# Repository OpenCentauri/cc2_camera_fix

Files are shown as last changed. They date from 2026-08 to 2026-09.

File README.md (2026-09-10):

# Prevent or recover the Elegoo CC2 stock camera failure

Some stock Elegoo Centauri Carbon 2 cameras can stop working after repeated
printer power cycles. This repository provides ways to protect or recover
an affected camera:

- a working camera can receive a small startup fix through USB without
  flashing a firmware image;
- if there is too little free space to install that fix, use a same-camera
  backup to build and restore a preventive image through USB;
- a camera that no longer starts can be recovered from its own flash backup
  with an external programmer.

All routes preserve the identity of **your** camera. There is no generic
firmware image in this repository, and you must never write another camera's
dump to your device.

> **AI-development note:** This fix was developed with the assistance of AI.
> It has produced the expected result in two tested cases, but if you have any
> doubts, independently audit the tools before using them on your hardware.

## First identify your camera

The known failure affects one 8 MiB flash-layout variant of the
`EF-S7-V1.0.30B` camera family. An earlier 16 MiB 30B variant uses materially
different hardware and firmware. A newer `EF-S7-V1.0.30D` revision also uses
different hardware and software and is not affected by this particular
problem.

Do this identification before building a USB cable, buying a programmer, or
running a repair operation.

If the camera feed still works, start with the read-only stream check. Install
[`cc2camera`](docs/INSTALLATION.md), find the printer's IP address or hostname,
and run:

```sh
cc2camera identify-camera PRINTER
```

For example:

```sh
cc2camera identify-camera 192.168.1.50
```

If the stream is unavailable, the signature is unknown, or you want authoritative
visual confirmation, inspect the hardware:

1. Power the printer off and unplug it from mains power.
2. Remove the camera module from the printer by undoing its single mounting
   screw, then unplug its four-wire cable.
3. Look at the large processor on the camera mainboard that's now in front of you.

If it is marked `TX5110`, the camera is likely the newer, unaffected family.
This recovery does not apply. If it is marked `Ingenic T23`, or the marking is
unclear, remove the two housing screws and check the complete PCB revision.

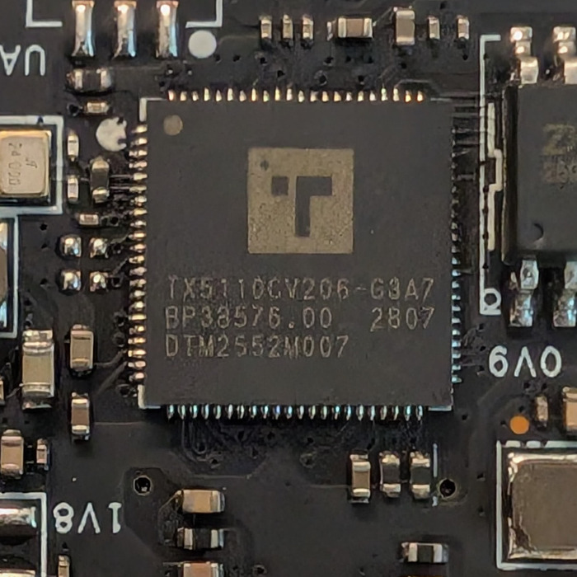
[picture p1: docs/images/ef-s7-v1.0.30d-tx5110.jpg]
TX5110 processor on a newer CC2 camera


The four-digit PCB manufacturing code appears to use `WWYY` week/year order.
It is useful supporting evidence, but is not a safe cutoff on its own: component
or firmware changes may not align exactly with calendar weeks.

| Identification | Observed manufacturing codes | What is known |
|---|---|---|
| `EF-S7-V1.0.30B` / Ingenic T23 / 8 MiB `ZB25VQ64` family | `0226`, `0526` (two units), `1526` | This is the supported layout on which the failure has been observed. Continue below. |
| `EF-S7-V1.0.30B` / Ingenic T23 / 16 MiB `P25Q128H` family | `4025` | This early layout is materially different. The known erase defect has not been established on it, and the current fix does not apply. |
| `EF-S7-V1.0.30D` / likely TX5110 | Not established | This revision is not affected by the known failure. This guide does not apply. |
| Any other revision, processor or flash layout | Not established | It has not been investigated. We do not know whether it is affected, and this guide does not apply. |

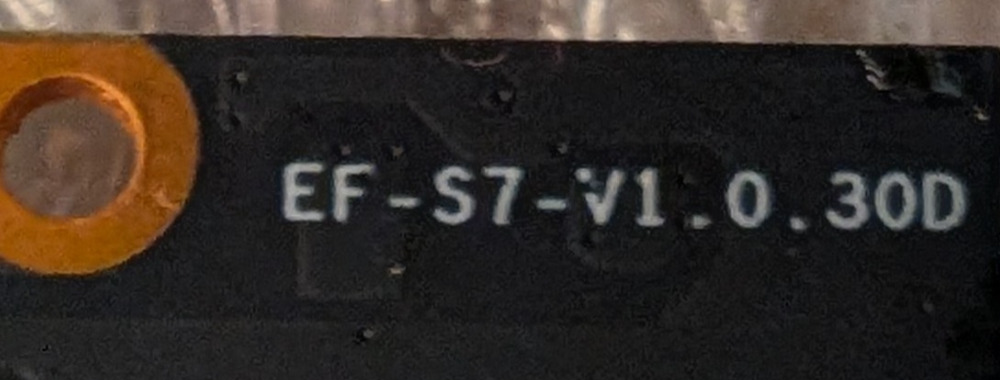
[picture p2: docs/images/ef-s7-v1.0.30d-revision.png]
EF-S7-V1.0.30D PCB marking


Photographs of the `EF-S7-V1.0.30B` board are available in the
[OpenCentauri camera documentation](https://docs.opencentauri.cc/hardware/CC2/camera/).
The stream fingerprint is a convenient read-only family-identification aid.
The complete hardware markings and the tool's firmware and flash-layout checks
determine whether a 30B camera is supported. Never bypass a refusal because a
date code or stream signature appears to match.

## Choose the path that matches your camera

### The affected camera still works

Use the [USB prevention route](#working-camera-usb-prevention). It needs a
simple camera-to-USB cable but no SPI programmer.

### The affected camera no longer works

First check whether the fault is isolated to the camera:

1. Leave the stock camera disconnected.
2. While the printer is off, connect a known-working ordinary USB webcam to
   the printer's front USB port.
3. Power the printer on.

If the replacement webcam produces a feed, the stock camera is likely the
problem. Continue with the
[hardware recovery route](#failed-camera-hardware-recovery).

If the replacement webcam also fails, this test has not isolated the problem
to the stock camera. Stop this camera-recovery procedure.

> **Temporary replacement:** Once the stock camera is disconnected, most
> ordinary USB webcams can be used in the front USB port while you wait for a
> replacement or decide whether to attempt recovery. Connect the webcam before
> powering the printer on so it has the best chance of becoming `/dev/video0`,
> which is the camera device the printer expects. The likely drawback is an
> inconvenient camera angle unless you improvise or print a mount.

## Working camera: USB prevention

Start with the startup fix below. It writes small configuration files and
reapplies a correction each time the camera starts, allowing its filesystem to
reclaim deleted data. It requires no SPI programmer or firmware-image write.
The installer checks that enough already erased space is available before
writing. If space is insufficient, use the
[image restore fallback](#if-there-is-not-enough-space-build-and-restore-an-image).

The startup fix is [physically tested on one supported camera](docs/STARTUP-HOOKS-VALIDATION.md),
including repeated boots and a bounded write/delete pressure test. That camera
already had the earlier preventive image patch; hook-only operation on otherwise
unmodified stock startup was not independently tested.

### What you need

- the affected camera, still able to start;
- access to a printer with a 0.2 mm nozzle;
- four P50 pogo pins, such as P50-J1;
- the USB-A plug and cable from an unused USB data cable;
- [cc2camera installed](docs/INSTALLATION.md), either the Windows executable or Python package;
- the Android platform `adb` executable as described in the installation guide.

### Build the camera-to-USB cable

The included [printable pogo-pin adapter](docs/models/cc2-camera-p50-pogo-adapter.stl)
acts as a plug for the four-pin socket on the camera PCB. Print it with a
**0.2 mm nozzle** and fit four P50 pogo pins; P50-J1 is one suitable example.

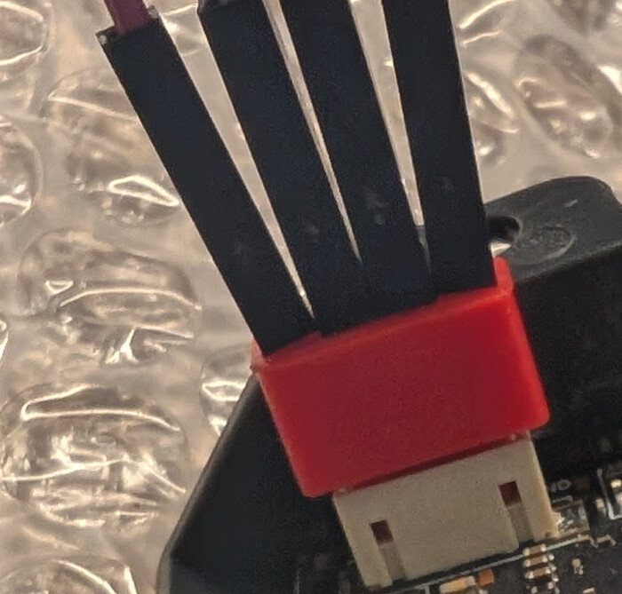
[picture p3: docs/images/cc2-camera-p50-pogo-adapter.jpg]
Printed pogo-pin camera adapter attached to a USB cable


The computer end can be salvaged from an old USB-A cable. Cut off the unwanted
device end, leaving the USB-A plug and enough cable to work with. Make sure it
is a data cable with all four conductors rather than a charge-only cable.

The camera connector carries ordinary USB 2.0:

| Camera pin | Signal | USB-A pin | Typical USB cable color |
|---:|---|---:|---|
| 1 | GND | 4 | Black |
| 2 | D+ | 3 | Green |
| 3 | D- | 2 | White |
| 4 | +5 V | 1 | Red |

Do not trust wire colors unverified. Before connecting the camera, use a
multimeter to confirm every conductor from the USB plug to its pogo pin and
confirm that +5 V is not shorted to ground or either data line.

### 1. Start ADB and make a backup

Follow the [installation guide](docs/INSTALLATION.md) for `cc2camera` and `adb`.
Connect only one camera, then run:

```sh
cc2camera start-adb
cc2camera backup backup.zip
```

Use the command prefix from your [platform's installation instructions](docs/INSTALLATION.md).
If ADB is not on PATH, add `--adb "path/to/adb"` to connected-camera commands.

`start-adb` temporarily starts the camera's existing root ADB service, which
lets the computer run maintenance commands. `backup` reads the complete flash
repeatedly and publishes `backup.zip` only after obtaining three consecutive
identical images. Keep that ZIP unchanged and in a separate safe location.

### 2. Install the startup fix

This step writes files to the camera's configuration partition. Keep power
connected until installation and file readback finish. Read the
[startup-hook guide](docs/STARTUP-HOOKS.md) for prerequisites and recovery
conditions before running:

```sh
cc2camera install-erase-fix --backup backup.zip
```

Confirm with `INSTALL-ERASE-FIX` when prompted. The command checks the camera,
backup, firmware and available space, then installs and reads back the files.
It applies the correction on the next boot; installation does not restart the
camera automatically.

If the command refuses installation **because there is insufficient space**,
continue with the image restore fallback below. For other refusals or any
write/readback failure, stop and resolve the reported problem before proceeding.
Do not bypass validation or retry a partial installation blindly.

### 3. Restart and verify

After successful installation, restart the camera manually. Without optional
persistent ADB, run `start-adb` again to reconnect for verification:

```sh
cc2camera start-adb
adb shell cat /tmp/cc2-hooks.log
```

The log should contain:

```text
cc2flash: erase fix active; master=0x1000; partition geometry=0x4000
cc2flash: 10-erase-fix.sh exit 0
```

Follow the [remaining verification checks](docs/STARTUP-HOOKS.md#verify-on-the-camera)
and confirm the camera feed works before returning it to service. A successful
installation message alone does not establish that the boot hook ran. Stop if
the hook fails or the camera no longer works normally.

### Optional: keep ADB available after restart

Persistent ADB is useful for future maintenance, but is not required for the
erase fix. To enable it, while ADB is online, run:

```sh
cc2camera install-adb-startup --backup backup.zip
```

Confirm with `ENABLE-ADB`. This writes a separate startup hook and performs its
own space checks and readback. After the next restart, ADB should return without
`start-adb`. The erase fix remains independently installed if optional ADB
installation is refused.

### If there is not enough space: build and restore an image

Use the unchanged backup from step 1. This route builds a camera-specific
preventive image and **writes that image to flash through USB**. Keep power
connected throughout restore and verification. Detailed prerequisites and stop
conditions are in the [USB-maintenance reference](usb-maintenance/REFERENCE.md).

```sh
cc2camera build-image backup.zip
cc2camera restore backup-cc2-recovery/cc2-camera-recovery.bin --backup backup.zip
```

The builder validates the backup and creates the preventive image. Do not pass
`--adb` to offline `build-image`. If needed, run `cc2camera start-adb` again before
`restore` and add `--adb "path/to/adb"` to that connected-camera command.

The optional `restore --dry-run` performs the same-camera and allowed-change
checks without opening USB. `restore` repeats those checks, validates the live
camera against the preserved backup, temporarily prepares the known stock SFC
driver, and requires the literal confirmation `RESTORE-CC2` before its first
write. Keep power connected until it returns to normal USB and completes the
required three-read verification. Preserve both the original ZIP and recovery
image, then confirm the camera feed works.

Stop if any command refuses the camera, backup, firmware, partition layout, or
generated image. Do not work around a validation failure. This fallback is for
insufficient space before hook installation; restoring an image from a backup
that already contains hooks has [additional limitations](docs/STARTUP-HOOKS.md#recovery-and-compatibility).

## Failed camera: hardware recovery

This route reads and rewrites the camera's eight-pin SPI flash with an external
programmer. The recommended setup uses the NeoProgrammer graphical
application for every flash operation; only the recovery-image build requires
a command line.

### What you need

- a Windows computer;
- a CH341A/CH341B programmer verified for 3.3 V operation;
- an SOIC-8 test clip and cable;
- a multimeter;
- NeoProgrammer;
- [cc2camera installed](docs/INSTALLATION.md); the standalone Windows executable needs no Python or Git.

The CH341 worked with the flash still soldered on the tested camera. A Bus
Pirate is possible but was not reliable in-circuit on that setup; see the
[programmer reference](hardware-recovery/PROGRAMMER_REFERENCE.md) if you need
that alternative.

### 1. Verify voltage before connecting the camera

With the programmer connected to USB but no camera or clip attached, measure
CH341A pin 28 (`VCC`) relative to ground. It should be approximately **3.3 V**.
Also measure the programmer's flash `VCC` output if possible.

If a measured supply or logic level is near 5 V, stop. Board color, seller
description, purchase date, and jumper position are not proof that a
programmer is safe for a 3 V flash chip.

### 2. Connect the flash

Keep the camera's normal USB/power cable disconnected. Connect the SOIC-8 clip
before plugging the programmer into USB. Align the clip's pin-1/red-stripe
conductor with the flash chip's pin-1 dot or notch, and use the programmer's
25-series SPI position.

Confirm the complete marking on the flash itself. The verified 30B family uses
a 64 Mbit/8 MiB `ZB25VQ64`-family 3 V SPI NOR. If the actual chip, voltage,
capacity, or detected profile differs, stop rather than selecting a merely
similar chip.

### 3. Make three trustworthy backups

In NeoProgrammer:

1. Select **Detect IC** and confirm the exact chip profile and 8 MiB capacity.
2. Select **Read IC** and save the full buffer as `cc2-camera-1.bin`.
3. Without moving the clip, read again and save `cc2-camera-2.bin`.
4. Read a third time and save `cc2-camera-3.bin`.

Each file must be exactly 8,388,608 bytes. The recovery builder compares all
three byte-for-byte. All-`00`, all-`FF`, unstable, wrong-size, or inconsistent
reads mean the connection is not trustworthy. Do not erase anything.

Copy all three files to a separate safe location before continuing. They are
the only verified backup of this camera's identity-bearing data.

### 4. Build the recovery image

Open a terminal in the folder containing your three dump files, as described
in the [installation guide](docs/INSTALLATION.md). Run:

```sh
cc2camera build-image cc2-camera-1.bin --confirm-read cc2-camera-2.bin --confirm-read cc2-camera-3.bin
```

The command performs the stability, firmware, flash-layout, identity, patch,
and generated-image checks. It must finish without an error and create:

```text
cc2-camera-1-cc2-recovery\cc2-camera-recovery.bin
```

If it refuses the dump or reports unfamiliar data, stop. There is deliberately
no general `--force` option.

### 5. Erase, program, and verify

In NeoProgrammer:

1. Detect the chip again and reconfirm its exact profile and 8 MiB capacity.
2. Open the generated `cc2-camera-recovery.bin`. Confirm that the loaded file
   is exactly 8,388,608 bytes. Do not select `config-restored.bin`,
   `serial.cfg`, or any individual region file.
3. Use NeoProgrammer's automatic write sequence with **Erase**,
   **Blank Check**, **Write/Program**, and **Verify** enabled.
4. Require full-chip Verify to finish without any mismatch.

A failed erase, blank check, program, or verify is not a usable result. Keep
the setup connected and diagnose it rather than trying to boot the camera.

Only after complete verification succeeds should you unplug the programmer,
remove the clip, reconnect the camera's normal cable, and test it in the
printer.

## What the repair changes

Affected cameras repeatedly rewrite the same configuration files during every
boot. A defect in the flash driver prevents reliable cleanup of deleted data,
so old filesystem records accumulate until the writable configuration area can
no longer accept the next boot-time writes.

The startup fix corrects the driver's erase setting in memory each boot so
filesystem cleanup can work. It leaves the firmware image in place and stores
its startup files in the writable configuration area.

The image-based repair compacts that area, preserves the camera's own identity,
and changes startup behavior so default files are created only when missing.
It reduces unnecessary writes; it does not persistently repair the driver's
erase setting.

The builder accepts only the known 30B firmware family and allows changes only
inside the audited startup-script window and writable configuration partition.
Technical details, offsets, supported image fingerprints, config modes, and
limitations are in the
[hardware-recovery technical reference](hardware-recovery/TECHNICAL_DETAILS.md).

## Privacy and backups

Raw dumps, `backup.zip`, `serial.cfg`, and generated recovery images contain
unit-specific identifiers. Do not publish them unredacted. Preserve the
original backup separately from the computer used for recovery.

No full camera dump or vendor firmware image is included in this repository.

## Advanced and audit documentation

- [Installation and release downloads](docs/INSTALLATION.md)
- [Complete cc2camera command reference](docs/CLI.md)
- [Startup-fix installation and verification](docs/STARTUP-HOOKS.md)
- [Startup-fix hardware findings](docs/STARTUP-HOOKS-VALIDATION.md)
- [Programmer and alternative-hardware reference](hardware-recovery/PROGRAMMER_REFERENCE.md)
- [Independent recovery-tool verification](hardware-recovery/CC2_RECOVERY_VERIFICATION.md)
- [Hardware-recovery regression results](hardware-recovery/TEST_RESULTS.md)
- [USB-maintenance reference](usb-maintenance/REFERENCE.md)
- [USB project and hardware-validation status](usb-maintenance/PROJECT-STATUS.md)
- [Physical USB restore validation](usb-maintenance/PHYSICAL-VALIDATION.md)
- [Recovered USB protocol](usb-maintenance/PROTOCOL.md)
- [USB reverse-engineering evidence](usb-maintenance/EVIDENCE.md)

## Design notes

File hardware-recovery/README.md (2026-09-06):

# CC2 camera hardware recovery

Start with the repository's
[camera identification and recovery guide](../README.md#first-identify-your-camera).
It determines whether this repair applies and presents the normal
NeoProgrammer workflow with one required command-line invocation.

For details beyond that normal path:

- [CLI reference](../docs/CLI.md) documents inspection, alternate build
  modes, output files, and independent readback verification.
- [Technical details](TECHNICAL_DETAILS.md) document the root cause, exact
  firmware transformation, supported image family, identity handling, safety
  properties, and limitations.
- [Programmer reference](PROGRAMMER_REFERENCE.md) contains the complete
  electrical mapping and the Bus Pirate alternative.
- [Independent verification](CC2_RECOVERY_VERIFICATION.md) and
  [regression results](TEST_RESULTS.md) record the current evidence.

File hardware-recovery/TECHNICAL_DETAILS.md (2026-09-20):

# Hardware-recovery technical details

The normal prevention and recovery paths are documented in the [main user guide](../README.md).
This document records the implementation, validation model, supported image family, and limitations.

## Why the stock camera stops working

The stock camera is a small Linux computer, not just an image sensor. Its firmware has a writable 128 KiB JFFS2 `config` partition. During every boot, the vendor startup script unconditionally copies the same five default configuration files into that partition again.

Normally JFFS2 garbage collection would reclaim the obsolete copies. On this firmware and flash layout, erase/garbage collection does not work correctly. The old records accumulate until the partition cannot accept the next boot-time writes. The camera then fails to finish booting and no longer appears as a working USB camera. From the printer, the symptom is simply a missing or permanently dead camera feed.

This tool repairs both parts of that problem:

- it rebuilds the exhausted `config` partition, either keeping only the
  camera's own serial data or recreating every live regular file once;
- it changes the startup script to create each default file only when it is missing, stopping the deterministic write leak.

## Check that the camera is actually the problem

A missing image does not by itself prove that the camera flash is corrupted. Isolate the camera from the printer before buying or connecting a programmer:

1. Power the printer off and unplug it from mains power.
2. Unscrew the stock camera module and unplug its four-wire cable from the printer. Do not work on the connector while the printer is powered.
3. Connect a known-working, ordinary USB webcam to the printer's front USB port while the printer is still off.
4. Power the printer back on with the stock camera disconnected.
5. If that webcam produces a feed, the printer mainboard, software, and USB-camera path are working; failure of the stock camera module is then likely. If the replacement webcam also fails, diagnose the printer side before attempting this repair.

Connecting the replacement webcam before boot is the safest way to have it appear as `/dev/video0`, which is the device the CC2 uses. Connecting it later can also work, but unplugging and reconnecting USB cameras repeatedly may assign different `/dev/video*` identifiers.

This is a useful isolation test, not proof of this exact flash failure. The builder provides the final check: it refuses a dump unless its firmware structure and invariant bytes match the supported camera firmware exactly.

## What this repair requires

For a failed camera, read and rewrite the eight-pin SPI flash with an external programmer. A working camera can use the USB prevention workflow in the main guide. Both use the same image builder.

The recommended setup is:

- a CH341A/CH341B USB programmer that has been verified for 3.3 V operation;
- an SOIC-8 test clip and cable, allowing the chip to be accessed on the camera board;
- a multimeter;
- NeoProgrammer on a Windows computer;
- Python 3.10 or later for validating the dump and building the repaired image.

A CH341 programmer is inexpensive and worked in-circuit on the tested camera: the flash did not need to be unsoldered. A Bus Pirate is still documented as an alternative, but in-circuit access may fail because other components on the board load or interfere with the SPI bus; on the tested setup it worked only after the flash was unsoldered.

> **Quick voltage safety check:** with the camera disconnected and the programmer powered from USB, measure CH341A pin 28 (`VCC`) relative to ground. It should be approximately **3.3 V**; if it is near 5 V, stop and do not connect the camera. Pin 28 is opposite pin 1 across the notched end of the 28-pin package—confirm the pinout before probing.
>
> This is a useful screening check, not complete certification. Some older CH341A board revisions need a soldered modification or external 3.3 V level shifting, while safe revisions exist and newer stock is often already corrected. Labels and purchase date are not proof: research your exact board and, if uncertain, also measure flash `VCC` and the SPI logic levels. See the [CH341 datasheet](https://www.wch-ic.com/downloads/CH341DS1_PDF.html) and the [older black-board voltage issue](https://wej.k.vu/electronics/ch341a-mini-programmer-fix/) for background.

## What the builder changes

### Persistent startup mitigation

The system patch changes the active copies in `/home/bashrc.sh` from unconditional writes such as:

```sh
cp /system/config/uvc.attr /etc/conf.d/uvc.attr
```

to copy-once checks:

```sh
[ -f /etc/conf.d/uvc.attr ] || cp /system/config/uvc.attr /etc/conf.d/uvc.attr
```

The original and patched scripts are included for audit. The patch preserves the vendor's existing source path for `uvc.config`.

The full system filesystem is not rebuilt. The tool verifies and decompresses the exact stock SquashFS fragment, applies the complete readable source transformation embedded near the top of the Python file, reconstructs the single-block XZ stream with fixed parameters, and updates its SquashFS size field. The reconstructed bytes must equal the exact audited patched hashes. Only this window is changed:

```text
0x463000–0x46AFFF
```

The input window, compressed fragment, decompressed fragment, original `bashrc.sh`, generated `bashrc.sh`, generated XZ stream, and final window each have independent expected SHA-256 checks. The shorter patched XZ stream intentionally leaves the now-unaddressed trailing stock bytes untouched; the authoritative SquashFS fragment size excludes them.

### Config recovery modes

`serial-only` is the default. The
builder extracts the camera's own CRC-valid `serial.cfg` and creates a minimal
128 KiB JFFS2 partition containing:

- one cleanmarker;
- one `serial.cfg` directory entry;
- one uncompressed `serial.cfg` inode;
- the original serial payload byte-for-byte;
- valid JFFS2 header, node, name, and data CRCs.

The five standard UVC/config files are intentionally omitted. The patched startup script creates each missing default once on the first successful boot.

Clean mode refuses to discard CRC-valid names outside the audited stock set.
If you have inspected the source and intentionally want to wipe unfamiliar
config contents too, add `--wipe-unknown-config`. That override still preserves
and cross-checks `serial.cfg`; it is not permission to ignore identity or
firmware validation failures.

`preserve-files` instead resolves the current root-directory view and recreates
every live regular file once in a fresh compact JFFS2 image. It preserves file
contents, mode, owner, timestamps, flags, inode identity, and directory-entry
metadata, while dropping obsolete/dead historical nodes. It supports
uncompressed, zero-filled, and zlib-compressed source fragments and fails
closed on directories, links/special entries, ambiguous metadata, unsupported
compression, fragments larger than the config partition, zlib streams that
expand beyond their declared size, or a live set too large for the audited
compact layout. Zlib decoding caps output at the declared size plus one byte.

## Supported image family

The `EF-S7-V1.0.30B` PCB label covers at least two materially different
hardware and firmware layouts. The four-digit PCB manufacturing code appears
to use `WWYY` week/year order. It is useful evidence, but is not treated as a
compatibility boundary:

| Observed layout | Manufacturing-code observations | Evidence |
|---|---|---|
| Supported 8 MiB `ZB25VQ64` family | `0226`, `0526` (two units), `1526` | The failure was reported on all four cameras. The `1526` unit and one recovered bricked unit have been physically recovered or protected with this fix. |
| Early 16 MiB `P25Q128H` family | `4025` | Two supplied full dumps share the 16 MiB partition map. Photographs show the T23, 30B PCB label, manufacturing code and 128-Mbit flash. Their JFFS2 cleanmarkers occur at `0x8000` intervals, matching an erase size handled by their kernel. The known `0x4000` erase mismatch has not been established on this layout. |

The early dumps were analyzed privately and remain outside the repository.
The 16 MiB family is not accepted by the builder or installers. A manufacturing
code, PCB revision or stream signature never overrides firmware, capacity,
partition-map or erase-geometry validation.

This release intentionally accepts only the exact firmware family already verified in four independent camera dumps with different unit identities:

- 8 MiB `ZB25VQ64` SPI NOR
- Ingenic T23N
- Linux `3.10.14__isvp_pike_1.0__`
- kernel build dated 2025-12-03
- Jovision `ucamera` v1.1.83
- partition layout:

```text
0x000000–0x03FFFF  boot
0x040000–0x18FFFF  kernel
0x190000–0x2E7FFF  root
0x2E8000–0x7CFFFF  system
0x7D0000–0x7DFFFF  HWCONFIG
0x7E0000–0x7FFFFF  config
```

There is no override or `--force` option for a mismatching firmware build. A refusal is a safety feature: do not weaken the checks or copy a reference camera's complete image over an unsupported unit.

## How validation handles different camera identities

A complete raw dump cannot be compared by ignoring only the visible serial
string. JFFS2 appends new nodes on each boot, so two otherwise identical
cameras naturally have different raw `config` histories. The HWCONFIG
partition also contains a per-unit UOID, an associated three-byte value, and a
four-byte little-endian year/month/day field. The date interpretation is based
on the observed `2026-03-02` and `2026-04-01` byte sequences; its exact vendor
semantics remain unknown.

The known 256-byte prefix of its type-12 length-prefixed record is validated.
Two payload lengths have been directly observed:

| Observed shape | Encoded payload length | Bytes after the known 256-byte prefix |
|---|---:|---|
| `type12-length256` | 256 (`0x0100`) | none |
| `type12-length261` | 261 (`0x0105`) | `00 00 02 98 40` or `00 00 00 08 40` |

The second shape was observed in stable multi-read dumps. Their boot, kernel,
root, system, stock startup-script window, partition layout, identity
structures, and exhausted JFFS2 failure states match the supported family.
The record length exactly includes the five added bytes. The camera's own
`ucamera` executable advances over this structure as a little-endian 16-bit
type, a little-endian 16-bit payload length, and that many payload bytes.

The observed serial and UOID families begin with either `12PSSSS3` or
`12PSSSS4`. Both retain the same total lengths and remaining character
structure. The fourth camera established that the adjacent check field spans
three bytes and that the calendar-shaped field varies by unit. Both fields are
preserved exactly and validated structurally rather than treated as firmware
bytes.

The meaning of the five-byte extension is unknown, so its value is not treated
as a firmware invariant. The validator requires record type 12 and one of the
two physically observed payload lengths: 256 bytes with no extension, or 261
bytes with a five-byte opaque extension. The extension is reported by length
and SHA-256. For comparison with the reference firmware, the 261-byte payload
length is normalized to 256 and the five extension bytes to zero. Recovery
preserves the complete input HWCONFIG partition byte-for-byte. Other payload
lengths remain unsupported until physically observed.

The validator therefore performs the strongest safe equivalent of “100% match apart from unit data”:

1. Every firmware byte that should be invariant must match the exact
   fingerprints after normalizing the structurally validated unit fields and
   the five-byte HWCONFIG extension, when present.
2. The 32 KiB SquashFS window containing `bashrc.sh` must equal either the exact stock hash or the exact audited patched hash.
3. These fields are excluded from or normalized for the invariant hash:

```text
0x7D200A–0x7D200C  three-byte HWCONFIG unit check value
0x7D2011–0x7D206E  94-byte HWCONFIG UOID
0x7D206F–0x7D2072  little-endian year/month/day field
0x7D2002–0x7D2003  normalized type-12 payload length
0x7D2104–0x7D2108  opaque five-byte type-12 extension, when present
0x7E0000–0x7FFFFF  writable JFFS2 config log
```

4. The excluded fields are still validated:
   - the type-12 length must be one of the two physically observed lengths;
   - the extension length and SHA-256 are recorded;
   - an all-zero or all-`FF` check value is reported as a warning;
   - the UOID must have an observed prefix and the expected 94-byte structure;
   - the four-byte date must decode as one of the physically observed calendar
     values, `2026-03-02` or `2026-04-01`;
   - `config` must contain CRC-valid JFFS2 nodes;
   - serial-only accepts only the six known filenames unless
     `--wipe-unknown-config` is explicit;
   - preserve-files accepts additional live names only when every entry can be
     safely reconstructed as a regular root file;
   - exactly one unambiguous `serial.cfg` value must be recoverable.

No other differences are accepted. See `REFERENCE_FINGERPRINTS.json`.

## Safety properties

The builder:

- can require any additional physical reads supplied with `--confirm-read` to be byte-for-byte identical;
- requires three identical reads for every unit unless reduced confidence is explicitly accepted;
- refuses files that are not exactly 8 MiB;
- validates exact hashes for every invariant segment;
- accepts only the exact known stock or known patched SquashFS window;
- never edits boot, kernel, root, or HWCONFIG;
- preserves the entire input HWCONFIG partition;
- preserves the original serial payload;
- validates the generated JFFS2 image by parsing it again, including a complete
  content/metadata round trip in preserve-files mode;
- refuses ambiguous, unsupported, or oversized preserve-files layouts;
- refuses unsafe output-directory reuse that could delete inputs or unrelated files;
- validates the complete generated recovery image again;
- proves no bytes changed outside the selected patch/config regions;
- creates a manifest and hashes for every output.

## Limitations

This is a mitigation for the deterministic per-boot write leak. It does not repair the underlying Ingenic SFC/JFFS2 erase-size defect. Other software that performs persistent writes could still consume config space.

The tool supports only the exact firmware build and known type-12 HWCONFIG
prefix represented by the embedded fingerprints. It accepts arbitrary contents
only for the observed five-byte extension. A future Elegoo/Jovision build,
another payload length, or a different record type or known-prefix layout must
be analyzed and fingerprinted separately.

Four real unit identities were directly inspected, including two with the
261-byte HWCONFIG record and one `12PSSSS3` identity. Invariant firmware and
the known HWCONFIG prefix must match exactly after unit-field and extension
normalization, while the UOID and serial must each match their observed
structure.
All unit-specific HWCONFIG bytes and the recovered serial payload are preserved
exactly. Because the proprietary full serial↔UOID derivation is unknown, the
tool does not infer or enforce a relationship between those independently
validated fields.

Static analysis can prove that a bricked dump is transformed into the exact known recovery bytes and that all relevant filesystems/checksums validate. Actual boot recovery still requires a controlled flash, full readback verification, and an observed successful boot; software-only review cannot replace that hardware test.

`serial.cfg` and the generated recovery image contain a unit-specific identifier. Do not publish them unredacted.

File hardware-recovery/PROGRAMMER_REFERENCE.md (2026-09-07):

# Programmer and electrical reference

The recommended NeoProgrammer workflow is documented in the [main user guide](../README.md#failed-camera-hardware-recovery).
This reference retains the complete electrical mapping and alternative-programmer notes.

## Programmer instructions

### Recommended: NeoProgrammer with CH341A/CH341B

NeoProgrammer does not use `cc2-camera-layout.txt`. This workflow erases, writes, and verifies the **complete 8 MiB** `cc2-camera-recovery.bin`, including the unit-specific data copied from the validated input dump.

#### Electrical checks

1. Read the complete part marking on the camera's SPI flash. The verified firmware family uses a 64 Mbit/8 MiB `ZB25VQ64`-family 3 V SPI NOR, but the exact chip and voltage on the board in front of you take precedence. The manufacturer describes `ZB25VQ64` as a 3 V device; do not infer voltage from programmer color, seller description, or a jumper alone. See the [ZB25VQ64 product information](https://www.gdzhianxin.com/index.php?a=show&c=index&catid=108&id=91&m=content).
2. With no camera or clip attached, perform the pin-28 voltage check described above. Also measure the programmer's flash `VCC` output and, if possible, its SPI logic-high levels. Use a proper level/voltage adapter if any measured level does not match the exact flash datasheet.
3. Disconnect the camera's USB cable and every other source of board power. Do not power the camera normally while the programmer supplies the flash. If your successful read setup uses a different, independently verified power arrangement, reproduce that exact arrangement; never connect two power sources blindly.
4. Connect the clip before plugging the CH341 programmer into USB. Align the clip's pin-1/red-stripe conductor with the flash's pin-1 dot/notch, and place the adapter in the programmer's **25-series SPI** position, not the 24-series I²C position.

Standard SOIC-8 SPI NOR signals are:

| Flash pin | Signal | CH341 label |
|---:|---|---|
| 1 | `CS#` | `CS` |
| 2 | `IO1/DO` | `MISO` |
| 3 | `IO2/WP#` | `WP` or pulled high |
| 4 | `GND` | `GND` |
| 5 | `IO0/DI` | `MOSI` |
| 6 | `CLK` | `CLK` |
| 7 | `IO3/HOLD#/RESET#` | `HOLD` or pulled high |
| 8 | `VCC` | verified 3 V supply |

Confirm this mapping against the exact flash datasheet and adapter silkscreen. Do not rely on the table if the package or adapter differs.

#### Establish a trustworthy backup

1. Install the appropriate CH341 driver and start NeoProgrammer. Obtain executables/drivers from a source you trust and scan them before use.
2. Use **Detect IC**, then confirm that the reported manufacturer/device ID, capacity, and exact selected profile correspond to the chip marking. Select `ZB25VQ64` only when that is the actual part. If the exact chip is unavailable, detection is inconsistent, or NeoProgrammer proposes only a vaguely similar `25Q64`, stop rather than guessing.
3. Click **Read IC**, wait for the complete 8 MiB buffer, and save it as `cc2-camera-1.bin`.
4. Without moving the clip, repeat the read twice and save `cc2-camera-2.bin` and `cc2-camera-3.bin`.
5. Require all three files to be exactly 8,388,608 bytes and have identical SHA-256 hashes. On Windows, for example:

```bat
certutil -hashfile cc2-camera-1.bin SHA256
certutil -hashfile cc2-camera-2.bin SHA256
certutil -hashfile cc2-camera-3.bin SHA256
```

All-`00`, all-`FF`, unstable, differently hashed, wrong-size, or intermittently detected reads mean the clip/power/in-circuit setup is not trustworthy. Stop and correct it before any erase or write.

Build the recovery image from those reads:

```bat
cc2camera build-image cc2-camera-1.bin --confirm-read cc2-camera-2.bin --confirm-read cc2-camera-3.bin
```

#### Full-chip erase, program, and verify

1. In NeoProgrammer, re-detect and re-confirm the exact chip profile and 8 MiB capacity.
2. Open the generated `cc2-camera-recovery.bin`. Confirm the loaded buffer/file is exactly 8,388,608 bytes. Do **not** load `config-restored.bin`, `serial.cfg`, or an individual layout region as the full-chip image.
3. Save the three original dumps somewhere separate before continuing. They contain the only verified copy of this camera's unit identity.
4. Use NeoProgrammer's automatic write sequence with **Erase**, **Blank Check**, **Write/Program**, and **Verify** enabled. Depending on the version, this is exposed through **Write IC** or its adjacent operation menu.
5. Do not edit status registers, OTP/security areas, unique IDs, or protection bits pre-emptively. If NeoProgrammer reports write protection, stop and identify the exact status-register meaning from the selected chip's datasheet before changing it.
6. Require NeoProgrammer's verify operation to complete without any mismatch. A failed erase, blank check, write, or verify is not a usable result; keep the setup connected and diagnose it rather than trying to boot.
7. Without moving the clip, run **Read IC** again and save the complete result as `cc2-camera-readback.bin`.
8. Verify that readback with the recovery tool:

```bat
fc.exe /b cc2-camera-1-cc2-recovery\cc2-camera-recovery.bin cc2-camera-readback.bin
```

Only after the tool reports a byte-for-byte match should you unplug the CH341 programmer, remove the clip, reconnect normal camera power, and test boot/USB enumeration.

NeoProgrammer's labels can vary slightly by release, but the required operation order does not: **three stable reads → build → full-chip erase → blank check → program → internal verify → full readback → tool verify**. NeoProgrammer describes the same backup/erase/write/verify capabilities in its [software overview](https://neoprogrammer.org/).

### Alternative: flashrom with a Bus Pirate

The generated `FLASHING.txt` also contains a `flashrom` command for the Bus Pirate. Unlike the NeoProgrammer workflow, it writes only the regions reported as changed and deliberately does not enable programmer-supplied target power.

In-circuit Bus Pirate access may not work on this camera because the rest of the board can interfere with the SPI bus. In the tested setup, the CH341 worked with the flash still soldered to the board, while the Bus Pirate worked only after the chip was unsoldered. Do not interpret unstable or failed reads as permission to write: obtain three identical full dumps first, or switch to the CH341 approach.

If you do use a Bus Pirate, independently verify the exact flash voltage, pinout, wiring, and power arrangement. Never power the camera normally while the programmer is connected unless you have explicitly designed and verified that arrangement.

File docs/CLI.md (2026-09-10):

# cc2camera command reference

Install using the [setup guide](INSTALLATION.md). Start with the workflows in
the [main guide](../README.md); these options are for reference.
Every command accepts `--help`. `cc2camera --version` reports the installed version.
On Windows PowerShell, use `.\cc2camera.exe` for a downloaded executable in the
current folder. Python installations also support `python -m cc2camera`.

## Connected camera

```text
cc2camera devices [--adb EXECUTABLE]
cc2camera device-info [--adb EXECUTABLE] [--serial SERIAL]
cc2camera identify-camera PRINTER [--timeout SECONDS]
cc2camera start-adb [--adb EXECUTABLE] [--serial SERIAL] [--timeout SECONDS]
cc2camera install-adb-startup --backup BACKUP.zip [--adb EXECUTABLE] [--serial SERIAL] [--yes]
cc2camera install-erase-fix --backup BACKUP.zip [--adb EXECUTABLE] [--serial SERIAL] [--yes]
cc2camera backup OUTPUT.zip [--adb EXECUTABLE] [--serial SERIAL]
    [--accept-bootloader-sha256 SHA256]
```

- `devices`: best-effort, read-only USB/HID and ADB listing.
- `device-info`: validate root ADB and the supported MTD partition layout.
  This is not a complete firmware-image inspection.
- `identify-camera`: connect only to the printer's HTTP MJPEG stream on port
  8080 and compare three consecutive JPEG encoder fingerprints with the known
  `EF-S7-V1.0.30B` and `EF-S7-V1.0.30D` signatures. Pass a printer hostname or
  IP address, for example `cc2camera identify-camera 192.168.1.50`. The command
  does not use USB, HID or ADB and does not modify the printer or camera.
  An unrecognized or changing signature is refused as unknown rather than
  guessed. The 30B signature has been observed on two independent known 30B
  cameras; the 30D signature has been observed on one known 30D camera. The
  stream cannot distinguish the early 16 MiB and affected 8 MiB 30B variants.
  Affected 8 MiB cameras have been observed with PCB manufacturing codes
  `0226`, `0526` and `1526`; a supplied early 16 MiB camera is marked `4025`.
  These codes appear to use `WWYY` order, but are supporting evidence rather
  than a safe compatibility cutoff. The tool's firmware and flash-layout
  checks determine whether the fix applies. Default HTTP timeout: 5 seconds.
- `start-adb`: temporarily start the existing daemon; no persistent startup
  file. Default timeout: 30 seconds.
- `install-adb-startup`: install `enabled/90-adb.sh` and the shared
  `/etc/conf.d/system.sh` runner. Requires `ENABLE-ADB` or `--yes`.
- `install-erase-fix`: install `enabled/10-erase-fix.sh` and the shared runner.
  Requires `INSTALL-ERASE-FIX` or `--yes`. It corrects the known kernel's master
  erase size in RAM before camera startup on subsequent boots.
  Both installers require online root ADB, a preserved same-camera backup,
  stable live reads and sufficient clean config space. They perform config
  file writes, not firmware flashing; neither remounts config during installation.
  Different contents at `system.sh` or the selected managed hook path are refused.
  Unrelated regular hooks in `enabled/` remain and execute in filename order.
  Restart manually and follow
  [startup hook verification](STARTUP-HOOKS.md); the erase hook has
  [physical validation on one supported camera](STARTUP-HOOKS-VALIDATION.md).
- `backup`: require three consecutive identical full reads within five
  attempts, then publish a new ZIP atomically. Never overwrites a backup.
  If ADB is offline, explicitly start it and rerun backup; backup itself is
  read-only. A reviewed unknown bootloader can be accepted by its exact
  SHA-256 without bypassing any other check.

`--adb` defaults to `adb`; a path to the executable is also accepted.
`--serial` is the USB ADB serial, not the identifier embedded in the firmware.
It does not relax the restore requirement for exactly one connected camera.

## Offline image work

```text
cc2camera inspect-image INPUT [--confirm-read DUMP]... [--show-identifiers]
cc2camera build-image INPUT [--confirm-read DUMP]... [-o DIR | --output DIR]
    [--config-mode {serial-only,preserve-files}]
    [--wipe-unknown-config] [--allow-fewer-reads] [--show-identifiers]
```

`INPUT` is a raw 8 MiB dump or an unmodified cc2camera backup ZIP.
Inspection validates without creating files; building creates a recovery bundle
in a new `<input-stem>-cc2-recovery/` directory unless `--output` is given.
The complete bundle is published atomically; failed builds leave no partial
bundle at the output path. Existing output directories are refused. Neither
command accesses hardware.

For raw dumps, repeat `--confirm-read` for each independent matching read:

```sh
cc2camera build-image camera-1.bin --confirm-read camera-2.bin --confirm-read camera-3.bin
```

A valid ZIP supplies its own three-consecutive-read evidence. Every raw input
requires three matching reads unless `--allow-fewer-reads` explicitly accepts
the higher risk. This exception is recorded in the bundle and does not bypass
firmware, identity, or mismatch checks.

| Config mode | Behavior |
|---|---|
| `serial-only` (default) | Rebuild config with only the camera's original serial.cfg; missing defaults are created at next boot. |
| `preserve-files` | Rebuild every supported live regular file once, preserving contents and metadata while dropping obsolete records. |

`--wipe-unknown-config` permits discarding unfamiliar names only with
`serial-only`. It never permits discarding the camera's identity.
`--show-identifiers` reveals identifiers in analysis reports; default reports
mask them. Raw dumps, ZIPs, serial.cfg, and recovery images always contain
private unit data regardless of report masking.

The bundle contains:

```text
cc2-camera-recovery.bin
cc2-camera-layout.txt
config-restored.bin
serial.cfg
MANIFEST.json
VALIDATION.txt
FLASHING.txt
SHA256SUMS.txt
```

Use the complete `cc2-camera-recovery.bin` for full-chip programming.
`FLASHING.txt` also contains an advanced flashrom region-write template based
on regions that actually changed. Always require full-chip verification.

## USB restore

```text
cc2camera restore IMAGE --backup BACKUP.zip [--dry-run]
    [--adb EXECUTABLE] [--serial SERIAL]
    [--bootloader-timeout SECONDS] [--reboot-timeout SECONDS]
    [--adb-timeout SECONDS]
```

`--dry-run` validates the candidate, preserved backup, allowed changes, known
preparation kernel, and transfer representation entirely offline. It opens no
transport and writes nothing.
It cannot certify the live camera or predict successful physical writing.

A real restore repeats local validation, requires the user to type `RESTORE-CC2`,
validates the live camera, applies the temporary SFC correction, and writes the
full image. Keep power connected until post-write verification completes.
If needed after reboot, temporary ADB startup requires separate consent.
There is no noninteractive write bypass or post-verification opt-out.

Timeouts default to 30 seconds for bootloader USB, 180 for normal USB return,
and 60 for post-write ADB availability. The last timeout does not cap the flash
reads themselves.

Verification requires three consecutive identical reads and exact agreement
through the end of HWCONFIG. Config may change during the required boot; the
output states explicitly whether config also matched byte-for-byte.

## External programmer verification

Require full-chip verification against the generated 8 MiB image in the
programmer software. If saving an independent readback, compare it with
`fc.exe /b expected.bin readback.bin` on Windows or
`cmp expected.bin readback.bin` on Linux/macOS. Any mismatch is a failure.
The tool does not operate an external programmer.

## Exit status

0 means the requested operation succeeded. 2 means a CLI, validation, or
operating-system error. An unknown `identify-camera` signature is a validation
failure and exits with 2 rather than guessing a camera revision. A successful
dry run is not a successful physical restore. A failed post-write check means a
write may already have occurred; read the error and keep the original backup.

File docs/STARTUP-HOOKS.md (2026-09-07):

# Experimental startup hooks without firmware flashing

This workflow is for the supported T23 camera while it still boots and has
working root ADB. It **writes files to the flash-backed config filesystem**;
it does not flash a firmware image or perform a raw partition erase. Keep a
verified backup from this camera and a working recovery method before testing.
Do not use it on a camera whose config is already exhausted.

The early-boot erase fix has physical validation on one supported camera:
hook execution, config remount, repeated boots, an observed GC erase and a
bounded automatic write/delete pressure test. See the
[hardware findings](STARTUP-HOOKS-VALIDATION.md) for observations and limits.
Offline tests additionally cover admission checks and shell failure paths;
power-loss recovery is not established. Installation never tries to remount
config while `ucamera` is running.

## Install from a checkout

Use the setup instructions in [INSTALLATION.md](INSTALLATION.md). Run from the
repository root so `python -m cc2camera` uses this checkout. Connect only one
camera. Obtain temporary ADB and preserve its backup first:

```sh
python -m cc2camera start-adb
python -m cc2camera backup before-hooks.zip
python -m cc2camera install-erase-fix --backup before-hooks.zip
```

Optional persistent ADB can be installed afterward, while ADB is online:

```sh
python -m cc2camera install-adb-startup --backup before-hooks.zip
```

Install the erase fix first so optional ADB does not consume its required space.
Persistent ADB is not required for the erase fix.

The confirmations are `INSTALL-ERASE-FIX` for the erase fix and `ENABLE-ADB`
for optional persistent ADB.
`--yes` explicitly supplies that consent for scripted local verification.
Both install commands accept `--adb` and `--serial`. They require already-online
ADB; neither silently starts it through HID. Keep the original backup unchanged.

Each command installs its feature in `/etc/conf.d/enabled`, and installs
`/etc/conf.d/system.sh` if absent:

| File | Purpose |
|---|---|
| `system.sh` | Copy the runner and all regular enabled scripts into a private tmpfs directory; execute them in C-locale filename order. |
| `enabled/10-erase-fix.sh` | Validate the known kernel and early-boot state, unmount config normally, correct the master erase size in RAM, and mount config again. |
| `enabled/90-adb.sh` | Start the existing ADB daemon if needed. |

Scripts execute synchronously with `/bin/sh`, before stock startup launches
`ucamera`. They must be regular files; symlinks and subdirectories in `enabled`
are refused by the runner. Hook stdout/stderr goes to `/tmp/cc2-hooks.log`.
A hook failure is logged and subsequent hooks can run if config is mounted.
If config is missing, read-only, or mounted from an unexpected device, the runner starts ADB for recovery and holds
startup rather than allowing the camera to run against an empty mountpoint.
It does not automatically reboot. This deliberate recovery hold lasts until
manual intervention; do not mistake it for a successful camera boot.

There is no migration or automatic overwrite of an existing different
`system.sh` or the selected managed hook. Only those two paths are checked for
expected contents by each installer. Unrelated regular hooks in `enabled/`
remain in place and execute in filename order. Exact files with mode `755`
are idempotent.
If an older or custom script is present, stop, save and review it, then resolve
it explicitly before installation. Do not blindly delete it or retry.

## Space admission and interrupted installation

Each command validates a preserved backup locally, then requires three
consecutive identical live flash reads, the known kernel SHA-256, matching
same-camera immutable data, and the expected partition map. It checks both:

- filesystem available bytes (`statfs`), with one extra logical erase block
  beyond the calculated installation budget;
- complete 16-KiB blocks containing a valid JFFS2 clean marker and otherwise
  only `FF`, with **five clean blocks retained** beyond the installation budget.

Dirty/reclaimable bytes, partial-block holes and entirely `FF` blocks without
clean markers do not count. Unmarked blocks may require the very erase operation
that is broken. The budget accounts for uncompressed data, inode pages,
namespace operations and block-tail slack. Current payloads require a 16-KiB
budget, hence at least six clean marked blocks and 32 KiB available via statfs.
This is deliberately conservative and may refuse a filesystem that could fit
these files under favorable conditions. There is no force option. If admission
fails for insufficient space, use the same-camera backup, image-building and
restore workflow instead. A runtime `force-gc`/unmount workaround is not provided.

The raw check measures already erased, marked blocks rather than assuming that
JFFS2 can reclaim deleted data. `statfs` alone is insufficient: its available
space accounting can include reclaimable dirty space. Neither measurement is
a guarantee against an erase failure, power loss or a concurrent writer.

Files are first pushed to verified tmpfs and read back byte-for-byte. Config is
read again and must be unchanged, and available space is checked again before
persistent writes. The selected hook is installed before the runner, using a
complete temporary file outside `enabled`, sync and rename. Final contents and
permissions are checked through ADB. No existing config file is truncated.

These checks cannot eliminate power-loss failure or a concurrent writer racing
the final check. Keep power stable. A timeout or readback failure can leave
partial installation; retain diagnostics and do not retry blindly. A leftover
`/etc/conf.d/.cc2-new-*` is refused and is never executed as an enabled hook.
No automatic cleanup writes config after an error.

## Verify on the camera

After the erase-fix command reports successful file readback, restart manually.
If persistent ADB was not installed, run `cc2camera start-adb` again to reconnect. Do not
run the erase hook yourself while the camera service is active.

```sh
adb shell cat /tmp/cc2-hooks.log
adb shell cat /proc/mtd
adb shell cat /proc/mounts
adb shell busybox pidof ucamera
adb shell busybox devmem 0x0043b190 32
```

Expected observations:

1. The log reports `10-erase-fix.sh` and contains
   `erase fix active; master=0x1000; partition geometry=0x4000`.
   If the optional ADB hook was installed, `10-erase-fix.sh` appears before
   `90-adb.sh`.
2. Config is mounted read/write from `/dev/mtdblock5` as JFFS2 at `/etc/conf.d`, and **all partition erase sizes
   still read `00004000`** in `/proc/mtd`. `ucamera` starts afterward.
3. If its optional hook was installed, ADB comes back without `start-adb`. The camera feed and its identity still work.
4. The final command returns a freshly read aligned pointer in
   `0x80450000..0x83fffd9c`. To independently read the master erase field,
   subtract `0x80000000` from that pointer and add `0x10`, then use
   `adb shell busybox devmem <calculated-address> 32` **without a value argument**.
   Expected value: `0x00001000`. Do not reuse an address from another boot.

Capture another backup and the kernel log without modifying config:

```sh
python -m cc2camera backup after-hooks.zip
adb shell dmesg
```

Stop if any check is refused, config is missing, the field or partition geometry
is wrong, ADB fails to return, the camera identity/feed changes, or dmesg reports
new erase/CRC/I/O errors. Do not run `flash_eraseall`, format config, kill
`ucamera` to force a remount, or repeatedly power-cycle a failing device.

Successful boot and readback alone establish hook execution, not garbage
collection. The separate [physical validation](STARTUP-HOOKS-VALIDATION.md)
records an observed erase, repeated boots and a bounded automatic GC pressure
test. Users do not need to repeat that stress test as routine installation
verification; the install commands do not stress the config partition.

## Recovery and compatibility

If the runner holds startup because config is missing or unusable, use the recovery ADB
connection to collect `/tmp/cc2-hooks.log`, `dmesg` and `/proc/mounts`. Do not
write to the empty `/etc/conf.d` directory. Use the preserved backup and the
repository's recovery procedure if ordinary mount recovery fails.

With config mounted and stable, removing an enabled hook is a persistent
filesystem operation requiring its own space and recovery assessment; removal
does not undo the current boot's RAM correction. Reboot restores the stock
master value unless the hook runs again. No uninstall command or migration is
provided here.

Full-flash backup still preserves these directories verbatim. The offline
`build-image --config-mode preserve-files` builder supports only flat config
files and **refuses** live subdirectories such as `enabled`; it does not silently
drop them. `serial-only` discards configuration by design and requires explicit
permission to discard unknown names. Do not use either as a hook-preserving
round trip. This workflow does not change the image builder's format support.

## Evidence and remaining uncertainty

Static analysis of all three supplied ROM images found the same kernel:
SHA-256 `0855c3a93f571c3130f1bdd38469e7c806ce713550a3ce536c81167579341545`
for flash bytes `[0x40000, 0x190000)`. The boot hook checks that complete kernel
partition with stock BusyBox MD5
`388e256470b2ad70f4a29cc37e0fee32`, plus exact live instructions, symbols,
partition geometry and the freshly read RAM pointer. MD5 here detects accidental
build differences; it does not authenticate firmware against an adversary.
The installer retains SHA-256. Using the built-in weaker boot fingerprint is an
explicit developer-approved exception; no other gate is relaxed.

The decoded driver selects erase commands for 4, 32 and 64 KiB. Its configured
16-KiB value falls through without initializing the command byte. A second
problem can replace a transfer failure with a later wait-ready success result.
These are static findings, not proof of which command reached the physical chip
on every failed erase. In particular, “the chip does not support 16 KiB” alone
is not an adequate explanation of the driver's behavior.

The hook changes only the master object's erase-size member, through the global
pointer at physical `0x0043b190`, offset `0x10`. Partition objects keep the copied
16-KiB geometry. The decoded loop therefore performs four 4-KiB operations for
a logical 16-KiB request. It does not alter JFFS2's block interpretation: existing
nodes can cross 4-KiB boundaries. The error-propagation defect is not repaired.

[Repository hardware records](../usb-maintenance/SFC-RESTORE-PREPARATION.md) report successful erase/readback after this RAM
field correction and return of failure after reboot. Those are prior reported
observations. The [startup-hook hardware findings](STARTUP-HOOKS-VALIDATION.md)
record physical runner execution, early remount and GC testing. The deliberate
recovery hold remains covered by offline tests, without physical fault injection.
The extracted stock `rcS` invokes `system.sh` after mounting config but before
`/home/bashrc.sh` launches `ucamera`; that establishes the proposed boot window.
Failure to mount config or find the script before that point cannot be repaired
by this hook.

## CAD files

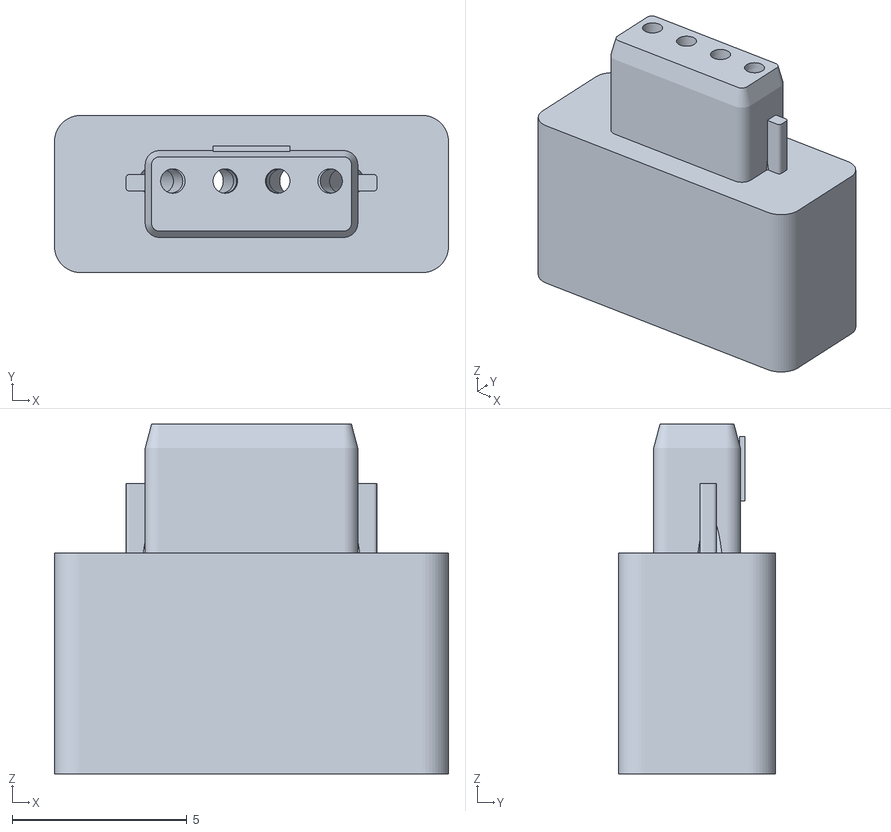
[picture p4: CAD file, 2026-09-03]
docs/models/cc2-camera-p50-pogo-adapter.stl
11.3 x 4.50 x 10.0

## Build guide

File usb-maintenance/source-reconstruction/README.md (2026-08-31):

# CC2 update-path source reconstruction

This directory is a human-readable, C-like reconstruction of the update-related
code in the supplied Elegoo Centauri Carbon 2 camera flash image.

It is **not the vendor's original source code**. Names, types, and control-flow
shape were chosen for readability. Constants, command branches, packet fields,
state transitions, paths, checks, and omissions are derived from the supplied
binaries. Every important reconstructed function is annotated with its original
address so it can be checked against the disassembly.

## Files

- `hid_update_reconstructed.c` — Linux `/bin/hid_update`: normal-mode HID
  framing, version/configuration commands, arbitrary-file upload, upgrade flag,
  and HID event loop.
- `uboot_updater_reconstructed.c` — main U-Boot updater: common frame format,
  metadata/data state machine, ACK/retry behavior, MD5 validation, SPI erase and
  write, HID/CDC transport choice.
- `spl_upgrade_gate_reconstructed.c` — SPL decision that detects the persistent
  upgrade magic and transfers control to the updater.
- `TRACEABILITY.md` — source-address map, confidence notes, and a list of the
  material unsafe behaviors retained in the reconstruction.
- `REPRODUCING.md` — commands for extracting the daemon and disassembling the
  address ranges from the supplied 8 MiB image.
- `protocol_reference.md` — the companion byte-level command and protocol
  reference.

## Analyzed inputs

| Artifact | Size | SHA-256 |
|---|---:|---|
| Supplied SPI-NOR image | 8,388,608 | `269f1b3b205e2ac30ada7cb98a7aeb9ada2e76786dc14abe95ea9c56dce73d1f` |
| Extracted `/bin/hid_update` | 19,048 | `bcbdd698b4b9208f73f7ef1f9846b3a96130a1bcc5c118c0e71543cf4e1ed503` |

The extracted daemon is a stripped little-endian MIPS32r2 ELF with MD5
`8091751fdd4d0d50ea31901663797a86`.

## Scope

The reconstruction covers the complete command surface found in the Linux
maintenance daemon and bootloader updater. It does not attempt to reproduce the
Linux kernel, UVC streaming application, codecs, sensor drivers, or unrelated
U-Boot commands.

No physical-camera write was performed while producing this reconstruction.
USB endpoint assignment and timing therefore remain runtime-unverified.

## How to read the code

Comments use these labels:

- `CONFIRMED` — visible directly in instructions, constants, descriptors, or
  filesystem contents.
- `INFERRED` — a readable name/type or library-level interpretation reconstructed
  from calling convention and use.
- `BUG-COMPAT` — deliberately shows unsafe or surprising behavior present in the
  binary; it is documentation, not recommended implementation.

The source is intended for audit and reasoning, not compilation or deployment.
External helpers such as `transport_send`, `spi_erase`, and `vendor_flash_ioctl`
stand in for vendor/library functions whose internals are outside the relevant
protocol path.

Run the dependency-free protocol checks with:

```sh
python3 verify_protocol_vectors.py
```

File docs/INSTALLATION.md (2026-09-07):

# Install cc2camera

## Windows: standalone executable

1. Open the [GitHub Releases page](https://github.com/phryneas/cc2_camera_fix/releases).
2. Choose a release and expand **Assets**.
3. Download **cc2camera.exe** to a new folder, for example `Documents\CC2-camera`.
4. In File Explorer, open that folder, click its address bar, type `cmd`,
   and press Enter. This opens Command Prompt in the correct folder.
5. Paste this command and press Enter:

```bat
cc2camera.exe --version
```

It should print a version number. Keep this window open for the recovery
instructions. Do not double-click the executable: it is a command-line tool.
In PowerShell, prefix a local executable with `.\`, for example
`.\cc2camera.exe --version`.

The executable is unsigned; Windows may show a reputation warning. Check that
you obtained it from this repository's intended release. Do not disable your
antivirus. If you are not comfortable running it, use the Python route below.
Each release build also attaches `cc2camera.exe.sha256`; you can compare its
digest with `certutil -hashfile cc2camera.exe SHA256`. This checks download
integrity, not publisher identity.

Assets appear only after the release build succeeds. If a release has no
executable, inspect its Actions result or use Python; the source-code ZIP is
not a standalone executable.

## USB workflows also need ADB

Offline image inspection/building and external-programmer recovery do not need
ADB. USB startup, backup, and restore need Google's
[SDK Platform Tools](https://developer.android.com/tools/releases/platform-tools).

On Windows, download and extract the Windows ZIP. Copy the **whole extracted
platform-tools folder** into your CC2-camera folder; keep its DLLs beside
`adb.exe`. There is no need to edit PATH. Test:

```bat
platform-tools\adb.exe version
cc2camera.exe devices --adb "platform-tools\adb.exe"
```

Add `--adb "platform-tools\adb.exe"` to connected-camera commands in the guide.
For example:

```bat
cc2camera.exe start-adb --adb "platform-tools\adb.exe"
cc2camera.exe backup backup.zip --adb "platform-tools\adb.exe"
```

`restore --dry-run` accepts these options but does not access ADB or USB.
On Linux/macOS, download the matching Platform Tools archive and extract it;
use `--adb "/path/to/platform-tools/adb"` if it is not on PATH.
An offline ADB camera is expected before `start-adb`; an authorization,
driver, or device-ambiguity error is not equivalent to that state.

## Python alternative: install directly from GitHub

Use Python 3.10 or newer. No Git or manual repository download is required.
Choose a release tag from Releases. In the command below, replace
`TAG` with that tag (including its leading `v`, if present).

Windows Command Prompt, in your working folder:

```bat
py -m venv .venv
.venv\Scripts\python.exe -m pip install "cc2camera @ https://github.com/phryneas/cc2_camera_fix/archive/refs/tags/TAG.zip"
.venv\Scripts\python.exe -m cc2camera --version
```

Linux/macOS:

```sh
python3 -m venv .venv
.venv/bin/python -m pip install "cc2camera @ https://github.com/phryneas/cc2_camera_fix/archive/refs/tags/TAG.zip"
.venv/bin/python -m cc2camera --version
```

Use that same Python path followed by `-m cc2camera` in place of `cc2camera`
throughout the guide. No environment activation or PATH edit is needed.
HID support is installed with the package. ADB remains separate.
On Linux, your distribution may require its Python venv package and USB device
permissions. Do not use `sudo pip` or bypass an externally-managed-Python error.

## Contributor and release maintenance

Contributors can install from the repository root with
`python -m pip install -e .` and run
`python -m unittest discover -s tests -v`.

The maintainer creates and publishes releases manually in GitHub. Publishing a
release (including a prerelease) triggers the executable workflow on its commit:
install, offline tests, PyInstaller build, frozen CLI smoke checks, hash, upload.
Saving a draft does not trigger it. The workflow creates neither tags nor releases.
Existing assets are not overwritten. The Windows runner builds a console
application with Python/HID support, not ADB or firmware images.
The workflow must be present in the released source.

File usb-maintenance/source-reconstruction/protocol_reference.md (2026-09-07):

# Elegoo Centauri Carbon 2 stock-camera interaction protocol

**Firmware-specific reverse-engineering reference — updated 2026-09-04**

This document describes every command branch found in the supplied CC2 camera's
Linux maintenance daemon and U-Boot updater. It covers normal-mode USB HID,
bootloader HID, the bootloader's alternate CDC transport, configuration access,
the Linux file-upload service, the upgrade-mode trigger, firmware transfer, and
the absence of any USB flash-read command.

The catalog is complete for the two analyzed binaries. It is not a claim about
other firmware revisions. All multibyte integers are little-endian unless noted.

> **Physical status:** one test completed the in-order bootloader HID transfer,
> full-flash erase/write, normal reboot, video check, and independent three-read
> verification. The preceding normal-mode trigger is not safe: its stock erase
> path can fail and page-program the flag over occupied JFFS2 data. The current
> one-command restore remains unsuitable for end users. See
> [the physical validation record](../PHYSICAL-VALIDATION.md).

## 1. Evidence, scope, and confidence

| Artifact | Size | SHA-256 |
|---|---:|---|
| Supplied 8 MiB flash image | 8,388,608 | `269f1b3b205e2ac30ada7cb98a7aeb9ada2e76786dc14abe95ea9c56dce73d1f` |
| Supplied research archive v0.1.0 | 32,904 | `9593b01f3c40085fee6b6d1501538b4a0c2abc93fae0710af5ed25aa5f0d694a` |
| Supplied hardware notes | 4,392 | `7e63ea0ba157b0b6486d4d0f73e26ac09c9e55541fe328e6c71d4dae4babf72e` |
| Extracted `/bin/hid_update` | 19,048 | `bcbdd698b4b9208f73f7ef1f9846b3a96130a1bcc5c118c0e71543cf4e1ed503` |

`/bin/hid_update` is a stripped, little-endian MIPS32r2 ELF with MD5
`8091751fdd4d0d50ea31901663797a86`. Its Linux-side behavior and U-Boot's updater
were reconstructed by static disassembly. The supplied camera image was not
written to physical hardware during this analysis.

Confidence labels used here:

| Label | Meaning |
|---|---|
| Confirmed | Directly represented by code, constants, descriptors, or filesystem data in the supplied image |
| Runtime-unverified | Statically confirmed but not exercised against a physical camera in this work |
| Unknown | Not recoverable with confidence from the supplied image alone |

## 2. System and flash layout

The camera uses two distinct update stages:

1. Linux `/bin/hid_update` handles normal-mode maintenance commands and can set
   two persistent upgrade words.
2. After reboot, SPL sees those words and starts the U-Boot updater, which accepts
   a host-supplied image and writes it to SPI NOR.

The 8 MiB flash map is:

| MTD | Offset | Size | End | Contents |
|---|---:|---:|---:|---|
| `mtd0` | `0x000000` | `0x040000` | `0x040000` | SPL/main U-Boot |
| `mtd1` | `0x040000` | `0x150000` | `0x190000` | Linux uImage |
| `mtd2` | `0x190000` | `0x158000` | `0x2e8000` | root SquashFS |
| `mtd3` | `0x2e8000` | `0x4e8000` | `0x7d0000` | system SquashFS |
| `mtd4` | `0x7d0000` | `0x010000` | `0x7e0000` | plaintext HWCONFIG |
| `mtd5` | `0x7e0000` | `0x020000` | `0x800000` | JFFS2 runtime configuration |

The persistent upgrade words are at flash offset `0x7f8000`, inside `mtd5`.

## 3. USB identities and transports

### 3.1 Normal Linux mode

The active configuration contains:

| Field | Value |
|---|---|
| VID | `0xa108` |
| PID | `0x2240` |
| bcdDevice | `0x0090` |
| Product | `Ingenic HD Web Camera` |
| Manufacturer | `Ingenic Semiconductor Co.,Ltd` |
| Serial | `Ucamera001` |
| `adb_en` configuration | `1` |

The firmware builds a composite camera gadget containing UVC and the maintenance
HID endpoint used by `/bin/hid_update`. ADB is configuration-capable, but the
presence of `adb_en:1` must not be confused with a running daemon; see section 9.

Normal maintenance HID uses report ID `1` and fixed 1,024-byte reports.
`/bin/hid_update` opens `/dev/hidg0` read/write, waits with `select`, and processes
one complete 1,024-byte read at a time. There is no session setup, challenge, or
authentication. Except for the `0x3200` upload sequence field, requests are
independent.

### 3.2 Bootloader HID mode

The U-Boot USB device descriptor is:

```text
12 01 00 02 00 00 00 40 08 a1 08 ff 00 01 00 00 00 01
```

This decodes to USB 2.0, VID `0xa108`, PID `0xff08`, bcdDevice `0x0100`,
64-byte EP0, one configuration, and no USB string descriptors.

The vendor HID report descriptor declares usage page `0xff00`, report ID `1`,
8-bit fields, and report count `0x0bff` (3,071) in each direction. A report is
therefore 3,072 bytes including the report ID. Endpoint addresses and maximum
packet sizes are assigned at runtime and cannot be stated from the template.

### 3.3 Bootloader CDC mode

U-Boot also contains a CDC serial gadget. It feeds the same updater state machine
as HID, so CDC adds no commands. The updater frame is sent directly over CDC,
without the HID report ID or 3,072-byte padding.

The CDC descriptor template contains runtime placeholders, including a zero PID.
The stable CDC PID and endpoint assignments are therefore **unknown** without a
physical enumeration trace.

## 4. Normal-mode HID framing

### 4.1 Report layout

Requests and responses are fixed at 1,024 bytes:

| Offset | Size | Request meaning | Response meaning |
|---:|---:|---|---|
| 0 | 1 | report ID `0x01` | report ID `0x01` |
| 1 | 2 | magic `5a 5a` | magic `5a 5a` |
| 3 | 2 | command | echoed command |
| 5 | 1 | frame type | frame type |
| 6 | 2 | payload length | payload length |
| 8 | 4 | auxiliary value; sequence for `0x3200` | status code |
| 12 | 2 | CRC | CRC |
| 14 | `length` | payload | payload |
| remainder | — | normally zero padding | zero padding |

For valid host traffic, frame type `1` means payload/continuation and frame type
`2` means payload/final. The request parser includes payload in the CRC for both
types. Other frame-type values are not explicitly rejected, but their payload is
not covered by CRC and several handlers still trust `length`; they should not be
used.

The response builder emits a payload only for response frame type `1`. Every
ordinary acknowledgement is type `0`, length zero, with the result in the
32-bit status field.

### 4.2 CRC algorithm

The CRC is a nonstandard reflected use of polynomial `0x1021`:

```python
def cc2_crc16(data: bytes) -> int:
    crc = 0xffff
    for byte in data:
        crc ^= byte
        for _ in range(8):
            old_lsb = crc & 1
            crc >>= 1
            if old_lsb:
                crc ^= 0x1021
    return crc & 0xffff
```

The input is report bytes `0..11`, followed by exactly `length` payload bytes
when request frame type is `1` or `2`. CRC bytes `12..13` and report padding are
excluded. The check vector `b"123456789"` produces `0x1dba`.

The daemon does not bound the declared payload length to the 1,010 bytes remaining
in a report before calculating CRC. Malformed lengths can make it read beyond its
1,024-byte input buffer.

### 4.3 Parser status values

| Status | Meaning |
|---:|---|
| `0` | success |
| `1` | command/handler failure |
| `2` | wrong report ID |
| `3` | wrong magic |
| `4` | CRC mismatch |
| `5` | unknown high-nibble command group |

An unknown command inside a recognized group commonly produces **no response**,
not status `5`. Host software needs a timeout.

### 4.4 Top-level command dispatch

| Command range | Disposition |
|---|---|
| exact `0x0001` | version query |
| other `0x0xxx` | no response |
| any `0x1xxx` | no-op path; no response |
| recognized `0x2xxx` | configuration GET/SET |
| unrecognized `0x2xxx` | no response |
| recognized `0x3xxx` | Linux file upload |
| unrecognized `0x3xxx` | no response |
| **any `0x4xxx`** | set upgrade words and reboot |
| `0x5xxx`–`0xfxxx` | response status `5` |

The `0x4xxx` behavior is group-wide. `0x4000` is the conventional command, but
every command whose high nibble is `4` reaches the same destructive path.

## 5. Complete normal-mode command catalog

### 5.1 Version query

| Command | Request | Success response | Failure |
|---:|---|---|---|
| `0x0001` | No payload required | type `1`, status `0`, first line of `/tmp/version.txt` without newline | status `1` if open/read fails |

The file is opened with mode `r+`. Extra request payload is ignored.

### 5.2 Configuration commands (`0x2xxx`)

Every listed field has an even GET command and the immediately following odd SET
command. These are all configuration commands recognized by this binary:

| GET | SET | Key in `/etc/conf.d/uvc.config` | Present in supplied active config? |
|---:|---:|---|---|
| `0x2000` | `0x2001` | `manufact_lab` | yes |
| `0x2010` | `0x2011` | `serial_lab` | yes |
| `0x2020` | `0x2021` | `productnumber` | no |
| `0x2030` | `0x2031` | `vendor_id` | yes |
| `0x2040` | `0x2041` | `product_id` | yes |
| `0x2050` | `0x2051` | `device_bcd` | yes |
| `0x2f00` | `0x2f01` | `model_lab` | no |
| `0x2f10` | `0x2f11` | `cmei_lab` | no |
| `0x2f20` | `0x2f21` | `appkey` | no |
| `0x2f30` | `0x2f31` | `product_lab` | yes |
| `0x2f40` | `0x2f41` | `adb_en` | yes |
| `0x2f50` | `0x2f51` | `sensor_name` | yes |
| `0x2f60` | `0x2f61` | `i2c_addr` | yes |
| `0x2f70` | `0x2f71` | `default_boot` | yes |
| `0x2f80` | `0x2f81` | `sensor_fps` | yes |
| `0x2f90` | `0x2f91` | `sensor_width` | yes |
| `0x2fa0` | `0x2fa1` | `sensor_height` | yes |
| `0x2fb0` | `0x2fb1` | `hvflip` | yes |
| `0x2fc0` | `0x2fc1` | `rcmode` | yes |
| `0x2fd0` | `0x2fd1` | `bitrate` | yes |
| `0x2fe0` | `0x2fe1` | `qp_value` | yes |

GET semantics:

- Request payload is ignored.
- The daemon scans `/etc/conf.d/uvc.config`, splits each candidate line at `:`,
  trims the key at its first space, and returns the raw value bytes between the
  colon and newline.
- Success is response type `1`, status `0`, with the value as payload.
- A missing key, open error, or parse error returns status `1`.

SET semantics:

- Send the replacement value as request payload using frame type `1` or `2`.
- The daemon rewrites the matching line, preserving the original key/padding and
  replacing the bytes after the colon.
- It buffers the remainder of the file, writes the replacement line and then
  restores that tail. If the result is shorter than the old file, it zero-pads
  back to the old length instead of truncating, so shorter values can leave NUL
  bytes at the end of the configuration file.
- Success is response type `0`, status `0`; failure is status `1`.
- There is no type, range, encoding, or semantic validation.
- Changes affect the JFFS2 runtime copy. The boot script copies the SquashFS
  default only if the runtime file is absent.
- The implementation uses small fixed stack buffers and does not adequately
  constrain lengths. Values should be short textual strings.

Keys absent from the active file still have handlers, but GET/SET fails until a
matching line exists. Unlisted configuration keys such as `gop`, `qp_reform`,
audio fields, and UVC format fields have no HID command in this binary.

### 5.3 Linux arbitrary-file upload commands (`0x3xxx`)

This family is host-to-camera only. It has no download or file-read operation.

Internal states are:

| State | Meaning |
|---:|---|
| `1` | idle |
| `2` | buffer allocated; destination required |
| `3` | receiving file data |
| `4` | final packet received; ready to commit |
| `5` | error |

```mermaid
stateDiagram-v2
    [*] --> Idle
    Idle --> NeedPath: 3000 init
    NeedPath --> Receiving: 311x / 3120 / 3150 / 31f0
    Receiving --> Receiving: 3200 type 1
    Receiving --> Ready: 3200 type 2
    Ready --> Idle: 3300 success
    Receiving --> Error: packet error
    Ready --> Error: commit error
```

All 13 recognized commands are:

| Command | Required state | Operation | Normal next state |
|---:|---:|---|---:|
| `0x3000` | `1` | initialize; allocate `0x01000200` bytes (16 MiB + 512), zero counters | `2` |
| `0x3110` | `2` | select destination path from request payload | `3` |
| `0x3111` | `2` | select destination path from request payload | `3` |
| `0x3112` | `2` | select destination path from request payload | `3` |
| `0x3113` | `2` | select destination path from request payload | `3` |
| `0x3114` | `2` | derive `/system/lib/modules/sensor_%s_t31.ko` using configured `sensor_name` | `3` |
| `0x3115` | `2` | derive `/system/etc/sensor/%s-t31.bin` using configured `sensor_name` | `3` |
| `0x3116` | `2` | select destination path from request payload | `3` |
| `0x3120` | `2` | select destination path from request payload | `3` |
| `0x3150` | `2` | select destination path from request payload through a separate but equivalent handler | `3` |
| `0x31f0` | `2` | select destination path from request payload | `3` |
| `0x3200` | `3` (also erroneously accepts `5`) | append numbered payload data | `3` or `4` |
| `0x3300` | `4` (also erroneously accepts `5`) | remove old path, write accumulated file, chmod `0777` | `1` |

Destination selection details:

- Payload bytes are copied into a shared 128-byte path buffer.
- The path is terminated at the first ASCII space.
- There is no adequate length check before the copy; valid producers should use
  at most 127 bytes and avoid spaces.
- The numeric distinctions among the payload-path commands do not change their
  behavior in this build. Their original vendor meanings are unknown.

`0x3200` data packets use the normal report fields as follows:

| Normal-report field | Meaning |
|---|---|
| command | `0x3200` |
| frame type `1` | more packets follow |
| frame type `2` | final packet |
| auxiliary value at offset 8 | absolute 32-bit packet sequence |
| payload | file bytes to append |

Sequences `0` and `1` are accepted specially. For sequence values `>=2`, the
value must equal the last accepted sequence plus one. The daemon checks that the
cumulative byte count does not exceed `0x01000200`. On a sequence or capacity
error it returns status `1`, frees the buffer, clears its pointer, and enters
state `5`. The state dispatcher nevertheless permits later data/commit calls in
state `5`; this is a firmware bug and is unsafe to exercise.

`0x3300` commit behavior is:

1. Require the final-packet flag.
2. Execute `rm <path>` through the shell, then `sync`.
3. Open `<path>` as `wb` and write exactly the accumulated bytes.
4. Execute `chmod 0777 <path>` through the shell.
5. If the target is exactly `/system/bin/hid_update`, copy the old executable to
   `/system/bin/hid_update_bak` before replacement.
6. Free the upload buffer and return status `0`, state `1` on success.

The remove and chmod commands interpolate the host-controlled path without shell
quoting. Truncation at the first space does not neutralize shell metacharacters.
The protocol has no authentication, signature, hash, atomic replacement, or
readback. It can overwrite persistent configuration or executable files and
should never be exposed to an untrusted USB host.

For recognized commands issued in the wrong state, the dispatcher usually
returns status `0` while doing nothing. Host software must track the state rather
than treating status `0` as proof of an action.

### 5.4 Upgrade-mode trigger (`0x4xxx`)

The conventional HID-mode request uses command `0x4000`, frame type `1`, and
exactly eight payload bytes:

```text
54 44 50 55 a1 03 02 01
```

These are two words:

```text
word0 = 0x55504454
word1 = 0x010203a1
```

The complete meaningful prefix of the 1,024-byte request, including CRC, is:

```text
01 5a 5a 00 40 01 08 00 00 00 00 00 f8 0e
54 44 50 55 a1 03 02 01
```

The remainder is zero padding.

The daemon copies the caller-declared payload length but submits a fixed eight-byte
driver request, so any length other than eight is unsafe. It opens `/dev/ucamera`,
writes the two words to flash offset `0x7f8000` with ioctl `0x2000550c`, then
internally reads the same eight bytes with ioctl `0x2000550d`. That read is only
used for local logging and is never returned to the USB host.

On successful write it replies status `0`, then calls `reboot`. On write failure
it replies status `1` but still follows the reboot path. The response echoes the
actual `0x4xxx` command received.

SPL checks `word0`. Main U-Boot interprets `word1` as:

| `word1` | Transport |
|---:|---|
| `0x010203a0` | CDC |
| `0x010203a1` | HID |
| any other value | HID default |

If Linux starts while `word0` still equals `0x55504454`, `/bin/hid_update` clears
both words to `0xffffffff` during daemon startup.

#### Physical trigger failure

On the tested camera, `0x7f8000` contained the JFFS2 cleanmarker prefix
`85 19 03 20 0c 00 00 00`. The daemon's erase attempt failed, after which its
page program produced the bitwise-AND result
`04 00 00 00 00 00 00 00` instead of the requested words. SPL therefore read
`0x00000004, 0x00000000` and booted Linux normally.

Runtime errors and exact-kernel disassembly agree on the cause: the SFC driver
was configured internally for `0x4000`-byte erases, but its sector-erase routine
selects opcodes only for `0x1000`, `0x8000`, and `0x10000`. A boot-specific live
RAM experiment changed that internal value to `0x1000`; ordinary 16 KiB MTD
erase requests were then successfully subdivided into 4 KiB sector erases.
That dynamic address and mounted-JFFS2 experiment are not a portable procedure.

## 6. Bootloader updater protocol

### 6.1 HID envelope

A bootloader HID OUT report is:

| HID offset | Size | Meaning |
|---:|---:|---|
| 0 | 1 | report ID `0x01` |
| 1 | variable | updater frame described below |
| remainder | — | padding to exactly 3,072 bytes |

IN reports have the same envelope. Use the embedded frame length; HID padding is
not checksummed. Over CDC, send and receive only the embedded updater frame.

### 6.2 Common updater frame

Host-to-device magic is `80 00 ee`; device-to-host magic is `81 00 ee`.

| Frame offset | Size | Meaning |
|---:|---:|---|
| 0 | 3 | direction-specific magic |
| 3 | 1 | frame type |
| 4 | 2 | total frame length, including final checksum |
| 6 | variable | payload |
| `length - 1` | 1 | additive checksum |

The checksum is `sum(frame[0:length-1]) & 0xff`. The smallest well-formed producer
frame is seven bytes. The parser uses the length supplied in the frame and does
not provide a general command namespace. Type-3 frames are checksum-validated;
the type-1 metadata path calls the same validator but mistakenly ignores its
return value, as detailed below.

All observed frame types are:

| Type | Direction | Payload | Meaning |
|---:|---|---|---|
| `1` | host → device | exactly 10 bytes | initialize firmware transfer |
| `2` | device → host | 4-byte LE integer | ACK: next expected absolute packet number |
| `3` | host → device | 4-byte sequence + data | numbered transfer data |
| `5` | device → host | one byte | terminal success (`01`) or failure (`00`) |

Only host types `1` and `3` reach the updater state machine. There is no host
type for command dispatch, flash read, memory read, query, cancel, or reboot.

### 6.3 Type-1 transfer metadata

A canonical type-1 frame is 17 bytes:

| Payload offset | Size | Meaning |
|---:|---:|---|
| 0 | 2 | maximum transfer-data bytes per type-3 frame (`subpack_size`) |
| 2 | 4 | total transfer-stream size, including the 128-byte image header |
| 6 | 2 | data packets accumulated per ACK (`packets_per_ack`) |
| 8 | 2 | firmware version; parsed/logged but not used for acceptance |

U-Boot calculates:

```text
frame_size   = subpack_size + 11
packet_count = ceil(transfer_size / subpack_size)
batch_size   = frame_size * packets_per_ack
batch_count  = ceil(packet_count / packets_per_ack)
```

It allocates a buffer for the entire `transfer_size` plus buffers used to assemble
a batch. Allocation failure prevents normal progress. On success the device sends
type `2` with payload `00 00 00 00`, meaning packet zero is next.

Malformed-metadata handling is weak. After checking the three-byte magic and the
type byte, the state machine unconditionally copies ten payload bytes. It neither
requires total length 17 nor acts on the checksum validator's result. It also
does not reject zero `subpack_size`/`packets_per_ack` before division or impose a
safe upper bound on `transfer_size` before allocation. A valid host must use a
17-byte, correctly checksummed frame with both divisors nonzero and a transfer
size consistent with the intended flash image.

For HID, a practical maximum is `subpack_size = 3060`: six common-header bytes,
four sequence bytes, 3,060 transfer bytes, and one checksum byte make a 3,071-byte
embedded frame; adding the HID report ID makes 3,072.

### 6.4 Type-3 data and ACK semantics

| Type-3 payload offset | Size | Meaning |
|---:|---:|---|
| 0 | 4 | absolute, zero-based packet number |
| 4 | up to `subpack_size` | consecutive transfer-stream bytes |

Packet numbers must be consecutive. U-Boot validates each frame's magic and
additive checksum and copies the data portion into the complete transfer buffer.
At each configured batch boundary it sends a type-2 ACK.

The ACK's four-byte payload is **not a constant**. It is:

```text
u32le(next packet number the device expects)
```

Examples when `packets_per_ack = 1`:

| Event | Type-2 ACK payload |
|---|---|
| metadata accepted | `00 00 00 00` |
| packet 0 accepted and more data remains | `01 00 00 00` |
| packet 1 accepted and more data remains | `02 00 00 00` |
| device requests retransmission beginning at packet 7 | `07 00 00 00` |

The final packet does not receive a type-2 ACK. It leads to MD5 validation and a
type-5 terminal status.

On an invalid frame or sequence, U-Boot resets accumulation to the start of the
current batch and sends an ACK containing that batch's first expected packet.
The error counters eventually produce type `5`, payload `00`; the bad-frame path
tolerates four errors and fails on the next, while the stalled-transfer helper
aborts when its retry counter reaches five. Exact wall-clock timing depends on
the gadget main loop and remains runtime-unverified.

Using `packets_per_ack = 1` minimizes retransmission ambiguity. A host should
still treat the ACK value as authoritative and resend from the requested absolute
packet number when necessary.

### 6.5 Transfer stream and 128-byte image header

The bytes carried by type-3 frames form one logical stream:

| Stream offset | Size | Meaning |
|---:|---:|---|
| 0 | 4 | ignored by this U-Boot build |
| 4 | 4 | target SPI flash offset |
| 8 | 4 | image length |
| 12 | 16 | binary MD5 of image bytes |
| 28 | 100 | ignored by this U-Boot build |
| 128 | `image_length` | bytes to erase/write |

For a valid producer, metadata `transfer_size` is `128 + image_length`. After the
last packet, U-Boot computes MD5 across exactly `image_length` bytes starting at
stream offset 128 and compares all 16 bytes to the header. It does not explicitly
cross-check the header length against the metadata allocation; a malformed larger
`image_length` can make the MD5 path read beyond the received transfer buffer.

On MD5 mismatch, it sends type `5` with payload `00` and does not enter the
erase/write path. On MD5 match, it sends type `5` with payload `01`, waits about
200 ms, then calls:

```text
erase(flash_offset, image_length)
write(flash_offset, image_length, transfer_buffer + 128)
```

The success byte proves only that the **received RAM image** matched its header.
It is transmitted before erase/write. This U-Boot build does not:

- check that `flash_offset + image_length <= 0x800000`;
- check the erase or write return values;
- read the programmed flash back;
- authenticate or verify a signature; or
- preserve partitions outside the requested range automatically.

Host software must enforce the 8 MiB limit and any partition policy. A full-image
write naturally replaces the persistent words at `0x7f8000`. A partial write can
leave the upgrade flag set and produce an update-mode boot loop.

## 7. End-to-end host sequence

A correct HID-mode flow is:

1. Enumerate normal HID `a108:2240` and exchange 1,024-byte reports.
2. Send a valid `0x4000` request with the exact eight-byte HID trigger payload.
3. Read status `0`; expect USB disconnect/reboot.
4. Enumerate bootloader HID `a108:ff08`.
5. Construct the 128-byte image header and split the complete stream into at most
   3,060-byte chunks.
6. Send type-1 metadata; require type-2 ACK value `0`.
7. Send numbered type-3 packets. At every nonfinal batch boundary, parse the
   type-2 ACK as the next expected absolute packet number.
8. After the final packet, require type-5 payload `01` for received-data MD5.
9. Do not treat that byte as programmed-flash verification. Allow time for
   erase/write and reboot before looking for normal mode.
10. Verify flash through an independent read path if one is available.

No protocol-level operation can safely cancel a transfer or clear the persistent
flag once the camera is in U-Boot update mode. Power loss during erase/write may
brick the camera.

## 8. Commands that do not exist

Exhaustive control-flow review found no USB-accessible operation for:

- reading SPI flash in Linux maintenance HID;
- reading SPI flash in U-Boot HID or CDC;
- downloading a Linux file through `0x3xxx`;
- querying U-Boot updater status beyond ACK/terminal status;
- verifying programmed flash;
- erasing without a subsequent write;
- selecting a named MTD partition; or
- authenticating a host or image.

Generic SPI read functions exist elsewhere in U-Boot for boot and console use,
but no updater branch calls them on behalf of USB. Linux ioctl `0x2000550d` reads
only the fixed eight-byte upgrade-word request and does not return those bytes to
the host.

## 9. Readback and guarded ADB startup

The root filesystem contains `/bin/adbd`, and the UVC configuration contains
`adb_en:1`, but the default persistent config does not directly launch the
daemon. Setting `adb_en` alone does not execute it.

The root SquashFS `/etc/init.d/rcS` supplies the missing boot mechanism. It:

1. locates the MTD partition named `config`;
2. mounts its JFFS2 filesystem at `/etc/conf.d`;
3. executes `/etc/conf.d/system.sh` if that file exists; and
4. only afterward mounts `/system` and launches `/home/bashrc.sh`.

Because `/bin/adbd` is in the root filesystem, a persistent `system.sh` whose
exact contents are `/bin/adbd &` starts the daemon at the next boot. The device
owner runtime-verified this by manual file creation. The boot hook and binary
location are independently confirmed in the supplied image.

The client exposes the two startup mechanisms as separate `start-adb` and
`install-adb-startup` commands. `backup` does not enter either path. Without any
setup, the stock gadget always exposes an ADB USB transport without a running
daemon, so the pre-daemon host state is `Ucamera001 offline`, not an absent
device. The startup commands classify both that exact offline state and a
genuinely absent selected device as eligible. A missing local ADB executable,
timeout, multiple or unauthorized devices, a non-root shell, malformed
partition map, failed/short read, or unstable acquisition remains a refusal.

The stock daemon implements legacy ADB `shell` and sync/`pull`, but rejects the
newer `exec-out` service with `error: closed`. The client therefore uses `shell`
only for textual `id` and `/proc/mtd` results, removing the doubled carriage
returns observed on Windows before parsing. It pulls each `/dev/mtdN` through
ADB sync into a fresh private host file, requires the exact validated partition
size, concatenates in MTD order, and deletes the temporary directory. It makes
at most five complete attempts and accepts only three consecutive byte-identical
8 MiB images. A nonconsecutive three-of-five majority is not accepted. It never
sends binary flash data through the terminal-oriented shell service.

This choice is runtime-grounded: on Windows 11 with ADB 35.0.2, a live
`adb pull /dev/mtd4` returned exactly 65,536 bytes. Its local MD5
`56392b3d32797a089432c7b633ef921f` matched `md5sum /dev/mtd4` on the camera.

### 9.1 Temporary upload-command start

`cc2camera start-adb` uses two confirmed bugs without weakening
the general upload-path API:

1. literal targets are truncated only at the first ASCII space; and
2. commit interpolates the remaining host-controlled target into unquoted
   `system("rm %s")` before calling `fopen(target, "wb")`.

The client sends this exact sequence:

| Step | Command | Frame details | Effect |
|---:|---:|---|---|
| 1 | `0x3000` | type `1`, empty payload | allocate/reset upload state |
| 2 | `0x3110` | type `1`, payload `/tmp/.cc2flash-adbd-bootstrap;/bin/adbd&` | select immutable no-space injection target |
| 3 | `0x3200` | type `2`, sequence `0`, payload one newline byte | mark upload final/ready |
| 4 | `0x3300` | type `1`, empty payload | execute injected `rm` shell line, then reach expected failing literal open |

At step 4 the first shell command is exactly:

```sh
rm /tmp/.cc2flash-adbd-bootstrap;/bin/adbd&
```

The `rm` side addresses tmpfs and `/bin/adbd` is launched once in the
background. The subsequent literal path contains `/bin/adbd&` below a normally
nonexistent `/tmp/.cc2flash-adbd-bootstrap;` directory, so `fopen` fails and the
later unquoted `chmod` is not reached. This produces a normal status-1 commit
reply; USB gadget changes may instead remove HID before the reply is readable.
The client accepts failure/timeout/disconnection only for that final exchange.
Live Windows testing confirmed that `/bin/adbd` starts and accepts `adb shell`,
but also showed that the old ADB transport can close during the USB transition;
in that case `adb wait-for-device` exits immediately with `error: closed`.
The client therefore polls the selected device until it is online, tolerating
only absent, stock `offline`, and exact `error: closed` transition states within
the bounded startup timeout. Each `adb get-state` subprocess is capped at the
remaining deadline; non-positive, infinite, and NaN durations are rejected
before HID is sent. An ADB subprocess timeout is a hard failure rather than a
fourth retryable transition state. The command validates root ADB and exits;
the user then runs the separate, strictly read-only `backup` command.

No persistent startup file is created. The handler still executes `sync` after
the shell command, so normal firmware writes already pending against JFFS2 may
be flushed; this mechanism specifically avoids adding the known
`/etc/conf.d/system.sh` mutation rather than promising a quiescent flash.

The uploader enters error state after the expected failed commit. If ADB does
not appear, another attempt may require rebooting the camera to reset the
uploader state.

### 9.2 Persistent startup hook

`cc2camera install-adb-startup` warns that it will overwrite an existing file,
then requires either the interactive phrase `ENABLE-ADB` or its explicit
noninteractive `--yes` option. It sends this normal-HID sequence:

| Step | Command | Frame details | Effect |
|---:|---:|---|---|
| 1 | `0x3000` | type `1`, empty payload | allocate/reset upload state |
| 2 | `0x3110` | type `1`, payload `/etc/conf.d/system.sh` | select persistent destination |
| 3 | `0x3200` | type `2`, sequence `0`, payload `/bin/adbd &` | send the one final 11-byte packet |
| 4 | `0x3300` | type `1`, empty payload | remove/recreate target and chmod `0777` |

After four status-zero replies, `install-adb-startup` exits with status `3`. It
explicitly reports that no flash was read and no host backup file was created.
The user must manually restart or power-cycle the camera and run `backup`. That
command requires a root identity, validates all six MTD names and sizes, and
requires three consecutive identical complete reads within five attempts.

### 9.3 Stable-read and boot-hash gates

Only after the three-read stability gate passes does `backup` fingerprint the
full 256 KiB `boot` partition. The built-in known reference is:

```text
5602ec961b4410ccceea0d4910e4fa768c6998bd4ba86143ba50855bdd0b7a54
```

If the stable image has a different boot SHA-256, the command publishes no
backup and prints that exact observed value. The user may independently review
it and rerun with `--accept-bootloader-sha256 <observed-sha256>`. A supplied hash
that differs from the newly observed partition is rejected. The accepted v2
manifest records whether the basis was `known-reference` or `explicit-hash`.
The raw image and manifest are published as exactly two members of one ordinary
ZIP, `flash.bin` and `manifest.json`. The client completes, flushes, and
CRC-checks a same-directory temporary archive before an atomic create-if-absent
hard link exposes the final `.zip`. The publication step cannot overwrite a
destination created concurrently, and it cannot expose only one half of the
image/evidence pair. Restore rejects additional/duplicate/encrypted members,
unsupported compression, the wrong advertised image size, oversized or
non-object JSON, decoder-limit failures from overlong integers or excessive
nesting, malformed or impossible counters, hash mismatches, and legacy manifest
formats before enabling a write.

After a restore returns to normal-mode USB, `--adb-timeout` bounds only the wait
for the selected daemon to become online. The three-consecutive-read verification
then runs as a separate phase with the normal per-command timeouts. This avoids
misrepresenting a short ADB-availability window as a bound on as many as thirty
partition pulls.

The persistent startup hook is a solderless recovery path, but it is
intentionally **not read-only**:

- `0x3300` removes any previous `/etc/conf.d/system.sh`, so the old file cannot
  be preserved through this protocol;
- normal HID provides no file download or content verification;
- the success response establishes only that the daemon-side write path returned
  success; and
- the client-generated four-command persistent transaction has offline tests
  but no physical USB capture in this work.

The later root ADB partition reads provide flash readback, but they do not recover
the previous contents of `system.sh` after it has been overwritten. Direct SPI
or UART remains the independent route when preserving existing config is
required before any mutation.

## 10. Client compatibility status

| Component | Current client behavior | Firmware behavior | Status |
|---|---|---|---|
| Bootloader data ACK | parses `u32le(next_expected_packet)` and requires the next in-order value; aborts on retry request | payload is the next expected packet, including a batch restart after an error | In-order 2,742-packet physical transfer passed; retransmission remains unimplemented and untested |
| Persistent ADB start | separate guarded command installs `/etc/conf.d/system.sh`; backup remains read-only | `rcS` executes the persistent hook next boot | Implemented and offline-tested; manual hook behavior runtime-verified |
| Temporary ADB start | separate command sends an immutable no-space upload target, tolerates only final-commit failure/disconnect, and polls across the old transport closing | unquoted `rm` target starts `/bin/adbd`; literal `fopen` then fails | Physical startup and root shell verified on Windows |
| Backup acceptance | requires three consecutive identical full reads within five attempts, gates on the known or explicitly accepted boot hash, and publishes one verified ZIP | ADB sync/`pull` can read each raw MTD device | Complete 8 MiB live acquisition verified; strengthened read/archive policy is offline-tested |
| Public Python catalog | exposes all 57 exact normal commands, every `0x4xxx` match, and boot types 1/2/3/5 with builders/decoders | complete analyzed dispatcher/state-machine surface | Implemented with source comments and exhaustive offline mapping tests |

The protocol builder, MD5 header, packet numbering, and bootloader transfer are
consistent with the analyzed code and the one-camera physical result. Restore
is still not hardware-ready because the normal-to-boot trigger has a confirmed
erase failure, retransmission remains unimplemented, and no uninterrupted
workaround has been physically validated.

## 11. Static-analysis anchors

These addresses make the findings reproducible. Linux addresses are ELF virtual
addresses. The main U-Boot image starts at flash file offset `0x6800`, linked at
`0x80100000`; for it, `VA = file_offset - 0x6800 + 0x80100000`.

| Function/data | Address |
|---|---:|
| Linux response builder | `0x00401034` |
| Linux parser/top-level dispatcher | `0x0040123c` |
| Linux HID handler thread | `0x004017d4` |
| configuration GET | `0x00401cd0` |
| configuration SET | `0x00402038` |
| configuration dispatcher | `0x004024c0` |
| upload initialization | `0x00402830` |
| upload packet append | `0x004028dc` |
| upload commit | `0x004029f0` |
| sensor-derived path builder | `0x00402ba8` |
| upload dispatcher | `0x00402e3c` |
| SPL upgrade-word read | `0xf0001c28` |
| SPL `0x55504454` comparison | `0xf0001c54` |
| U-Boot host-frame validator | `0x80117948` |
| U-Boot device-frame builder | `0x801179ec` |
| U-Boot retry/ACK helper | `0x80117b28` |
| U-Boot updater state machine | `0x80117d1c` |
| U-Boot SPI updater initialization | `0x801186ac` |
| U-Boot transport selection | `0x80118714` |
| U-Boot MD5 routine | `0x80119620` |
| U-Boot HID report envelope | `0x8011b9d8` |

## 12. Runtime uncertainties

The following remain hardware-unverified or unknown:

- the bootloader CDC PID and exact serial endpoint configuration;
- host HID API differences on systems other than the tested Windows host;
- retransmission behavior after a physical retry request;
- a safe uninterrupted normal-Linux-to-U-Boot entry procedure;
- general erase/write behavior and failure reporting beyond the one successful
  full-image write;
- whether other CC2 camera firmware revisions use the same commands; and
- any board-level recovery behavior associated with the `BSL0` pad.

These uncertainties do not change the command catalog, ACK semantics, lack of
bootloader USB readback, the physically observed trigger failure, or the unsafe
success-before-write behavior.

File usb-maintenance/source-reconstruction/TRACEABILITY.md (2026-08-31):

# Traceability and confidence

## Linux `/bin/hid_update`

| Reconstructed function | Original VA | Evidence represented |
|---|---:|---|
| `linux_main` | `0x00400b90` | two detached threads; main sleeps forever |
| `process_watch_thread` | `0x00400e90` | `ps > /tmp/1.txt`; scans for `ucamera`; 15-second loop |
| `cc2_crc16` | `0x00400fe8` | reflected right-shift loop using `0x1021`, initial `0xffff` |
| `send_normal_response` | `0x00401034` | 1,024-byte report construction, CRC, write |
| `dispatch_normal_report` | `0x0040123c` | validation, status codes, top-level command groups |
| `hid_event_thread` | `0x004017d4` | device opens, upgrade-word cleanup, `select`/read loop |
| `probe_ucamera_ready` | `0x00401b94` | `/dev/ucamera` read and ioctl `0x20005508` |
| `config_get` | `0x00401cd0` | command/key lookup and value response |
| `config_set` | `0x00402038` | tail-buffered configuration rewrite and zero-padding |
| `dispatch_config` | `0x004024c0` | all 42 GET/SET commands |
| `upload_init` | `0x00402830` | 16 MiB + 512 allocation and field reset |
| `upload_append` | `0x004028dc` | sequence/capacity checks and final flag |
| `upload_commit` | `0x004029f0` | remove/write/chmod/backup behavior |
| `build_sensor_path` | `0x00402ba8` | `sensor_name` lookup and two derived paths |
| `dispatch_upload` | `0x00402e3c` | full `0x3xxx` command state machine |

The ELF's `.pdr` records provide the function starts above even though ordinary
symbols were stripped. PLT relocations identify the libc and pthread calls.

## SPL and main U-Boot

The main U-Boot image begins at flash file offset `0x6800` and is linked at
`0x80100000`, so `VA = file_offset - 0x6800 + 0x80100000`.

| Reconstructed function | Original VA | Evidence represented |
|---|---:|---|
| SPL upgrade-word read | `0xf0001c28` | reads 8 bytes at flash `0x7f8000` |
| SPL magic comparison | `0xf0001c54` | compares word 0 with `0x55504454` |
| `validate_host_frame` | `0x80117948` | host magic and additive checksum |
| `build_device_frame` | `0x801179ec` | response magic, length, payload, checksum |
| retry/ACK helper | `0x80117b28` | batch ACK and five-error abort behavior |
| `updater_receive` | `0x80117d1c` | type-1 metadata and type-3 data branches |
| SPI updater initialization | `0x801186ac` | SPI probe and function-table setup |
| `select_update_transport` | `0x80118714` | persistent `a0`/`a1` mode selection |
| MD5 calculation | `0x80119620` | image-data MD5 |
| HID envelope | `0x8011b9d8` | report ID 1 and 3,072-byte HID reports |

## Important omissions and bug-compatible behavior

These findings are especially useful when verifying host/client assumptions:

1. Neither USB updater implements SPI-flash readback.
2. Any normal-mode command in the `0x4xxx` group reaches the reboot/upgrade path.
3. Normal-mode CRC length is trusted before being bounded to the report.
4. Linux file-upload paths are host-controlled for most `0x31xx` commands and
   are passed through shell strings (`rm %s`, `chmod 0777 %s`) without quoting.
5. Upload state checks also accept state `5` for `0x3200` and `0x3300` because
   the compiled arithmetic test is flawed.
6. U-Boot checks metadata magic/type but calls the common validator without using
   its result before copying the 10-byte metadata payload.
7. U-Boot does not reject zero subpacket size, zero packets-per-ACK, oversized
   transfer size, or inconsistent header/metadata lengths.
8. U-Boot compares MD5 only over `header.image_length` bytes beginning at offset
   128, without proving the allocation contains that range.
9. U-Boot sends the type-5 success byte before SPI erase/write and does not check
   erase/write results or perform a readback.
10. The SPI target range is not checked against the 8 MiB chip boundary.

## What remains inferred or runtime-unverified

- Decompiled local/global names and aggregate types.
- Exact source syntax and original function boundaries for inlined helpers.
- CDC runtime PID and endpoint assignments.
- Normal and bootloader endpoint addresses selected at runtime.
- Hardware timing, disconnect/re-enumeration timing, and physical write outcome.

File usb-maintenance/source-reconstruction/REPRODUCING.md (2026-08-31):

# Reproducing the static analysis

These commands assume the main project archive's `tools/` directory and a local
copy of the supplied 8 MiB flash image. They are read-only.

```sh
IMAGE=cc2-camera-after-bashrc.bin
sha256sum "$IMAGE"
```

The expected SHA-256 is:

```text
269f1b3b205e2ac30ada7cb98a7aeb9ada2e76786dc14abe95ea9c56dce73d1f
```

## Extract `/bin/hid_update`

The root SquashFS starts at flash offset `0x190000`:

```sh
python3 tools/squashfs_extract.py \
  --offset 0x190000 "$IMAGE" extracted-root
sha256sum extracted-root/bin/hid_update
md5sum extracted-root/bin/hid_update
readelf -h -S -r extracted-root/bin/hid_update
```

Expected hashes:

```text
SHA-256 bcbdd698b4b9208f73f7ef1f9846b3a96130a1bcc5c118c0e71543cf4e1ed503
MD5     8091751fdd4d0d50ea31901663797a86
```

The ELF's `.text` VMA and file offsets coincide relative to `0x00400000`.
Examples:

```sh
python3 tools/mips32_disasm.py extracted-root/bin/hid_update \
  --base 0x00400000 --file-offset 0 \
  --start 0x00400fe8 --end 0x0040123c

python3 tools/mips32_disasm.py extracted-root/bin/hid_update \
  --base 0x00400000 --file-offset 0 \
  --start 0x0040123c --end 0x004017d4

python3 tools/mips32_disasm.py extracted-root/bin/hid_update \
  --base 0x00400000 --file-offset 0 \
  --start 0x004024c0 --end 0x00403480
```

Use `.pdr` records to recover the stripped function starts and `.rel.plt` to map
PLT slots to imported libc/pthread names. `readelf -r` lists all 42 PLT entries.

## Disassemble the main-U-Boot updater

The main U-Boot image begins at flash file offset `0x6800`, linked at
`0x80100000`:

```sh
python3 tools/mips32_disasm.py "$IMAGE" \
  --base 0x80100000 --file-offset 0x6800 \
  --start 0x80117948 --end 0x801187cc
```

Thus, for any main-U-Boot address in this reconstruction:

```text
flash_file_offset = VA - 0x80100000 + 0x6800
```

The transport-selection fallthrough can be checked separately:

```sh
python3 tools/mips32_disasm.py "$IMAGE" \
  --base 0x80100000 --file-offset 0x6800 \
  --start 0x80118714 --end 0x801187cc
```

It compares word 1 with `0x010203a0`, then `0x010203a1`, and substitutes
`0x010203a1` for any other value.

## Disassemble the SPL gate

The early SPL image is mapped at `0xf0000000` from flash offset zero:

```sh
python3 tools/mips32_disasm.py "$IMAGE" \
  --base 0xf0000000 --file-offset 0 \
  --start 0xf0001c28 --end 0xf0001c80
```

The read starts at `0xf0001c28`; the comparison with `0x55504454` is anchored at
`0xf0001c54`.

## Verify protocol vectors

From the reconstruction directory:

```sh
python3 verify_protocol_vectors.py
```

This checks the unusual normal-HID CRC, the canonical eight-byte upgrade trigger,
the 17-byte bootloader metadata frame, nonzero ACK packet values, and the 128-byte
image header/MD5 layout without opening a USB device.

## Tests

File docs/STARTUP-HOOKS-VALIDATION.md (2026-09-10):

# Startup-hook hardware validation

These findings cover the supported Ingenic T23 camera with ZB25VQ64 flash
(JEDEC ID `5e4017`), Linux `3.10.14__isvp_pike_1.0__`, build #32 dated
2025-12-03, and PCB manufacturing code `1526`. Tests were performed by the
developer on one camera; private same-camera backup archives were compared
offline. No dumps or identity-bearing file contents are included here.

The tested camera already had the image-based preventive startup change that
copies defaults only when missing. Hook operation and the deliberate pressure
workload are physically tested on that setup. Hook-only operation with an
otherwise unmodified stock startup image was not separately tested.

## Installation and repeated boots: observed

The installer reported three consecutive identical flash reads, successful
hook-file installation/readback, and a reserved write budget of 16,384 bytes.
After reboot, the developer supplied:

```text
cc2flash: running 10-erase-fix.sh
cc2flash: erase fix active; master=0x1000; partition geometry=0x4000
cc2flash: 10-erase-fix.sh exit 0
cc2flash: running 90-adb.sh
cc2flash: 90-adb.sh exit 0
```

The same success log was reported after approximately 5–10 more reboots.
ADB returned automatically, config was mounted read/write as JFFS2, and
`ucamera` was running. The developer confirmed a working camera feed.
The supplied kernel log had no JFFS2 erase/CRC/I/O failure; unrelated USB/video
messages are not evidence about flash erasure.

All six `/proc/mtd` entries continued to report `00004000` erase size.
This is expected: the hook corrects the master driver's RAM field to 4 KiB,
while keeping the partition and filesystem geometry at 16 KiB. Successful
hook completion includes its normal unmount, RAM readback and mount checks.

The stock partition name is uppercase `HWCONFIG`. The earlier
`erase fix refused: partition-map` result was a case-sensitive admission
mismatch, not evidence that an attempted erase failed. The comparison now
normalizes case.

## Garbage collection: observed progression

The config partition is flash range `[0x7e0000, 0x800000)`: 128 KiB,
or eight logical 16-KiB blocks. A “clean block” below means a complete block
containing the valid JFFS2 clean marker followed only by erased `FF` bytes.
It does not mean every block containing deleted records has been reclaimed.

| Snapshot | Clean blocks | Direct observation |
|---|---:|---|
| After hook installation | 7 | Hook files persist; no erase transition in this comparison. |
| After a 16-KiB random write/readback/delete batch | 6 | Deleted test records consume space; developer reported success and no new kernel errors. |
| After 1 cumulative GC HUP request | 6 | An old clean marker becomes obsolete; no completed erase yet. |
| After 5 cumulative requests | 6 | Live records relocate; no completed erase yet. |
| After 13 cumulative requests | 5 | More live records relocate; first block still contains data. |
| After 25 cumulative requests | 6 | First logical block is erased and has a fresh clean marker. |
| After approximately 5–10 further reboots | 6 | All nine live file contents remain unchanged. |
| After 32 automatic pressure batches | 5 | All batches complete; live files remain unchanged. |

Manual requests sent SIGHUP to the identified `jffs2_gcd_mtd5` thread.
They were research operations, not a supported `force-gc` command. A request
need not finish an entire block: the intermediate snapshots show incremental
work. The kernel's GC implementation and
[upstream background thread](https://github.com/torvalds/linux/blob/v3.10/fs/jffs2/background.c)
support that interpretation.

The 25-request snapshot directly establishes an erase: 16,059 previously
programmed bytes in `[0x7e0000, 0x7e4000)` returned to `FF`, and the block
contains a fresh valid clean marker. All nine live files were preserved.
Sending a signal and seeing no kernel error alone would not establish this.

## Automatic pressure test: observation and inference

The test used 32 batches, each creating 8 KiB from `/dev/urandom` in tmpfs,
copying it to a dedicated config test file, calling `sync`, comparing contents,
deleting the test file, calling `sync` again and waiting one second.
It did not send manual GC signals or remount config.

Before writing, it checked the corrected master field and absence of the test
path. Each batch counted full clean blocks using raw MTD reads and a known
clean-block MD5. Stops were one or fewer clean blocks, command/readback
failure, matching kernel errors, or a maximum of 256 KiB cumulative payload.

The developer reported:

```text
Completed batches: 0; clean blocks: 6
Completed batches: 1; clean blocks: 6
Completed batches: 2; clean blocks: 5
...
Completed batches: 31; clean blocks: 5
CC2_PRESSURE_LIMIT_256_KIB
Final clean blocks: 5
```

Every intervening reported count after batch 2 was five. The final dump
contains obsolete test records for inode 18 and inode 49, consistent with the
first and final creations. There is no live pressure-test file.
All nine live files, including camera configuration and the three hook files,
are byte-for-byte identical to the after-reboots backup. Flash outside config
is also byte-for-byte identical.

**Inference:** successful synchronized random-data writes totaling twice the
partition capacity, with readback and a stable supply of clean blocks, strongly
support automatic reclamation keeping up with this workload.

**Limit of the dump comparison:** the two endpoint images contain no observed
0-to-1 bit transitions. A block that begins erased, is written and erased
during the test, and ends erased appears unchanged. These snapshots therefore
do not identify or count the individual automatic erase cycles. The direct
erase evidence comes from the separate manual-GC comparison above.

The test stopped at its workload limit, not near exhaustion. It did not
establish recovery from a nearly full initial filesystem, nor guarantee
indefinite endurance or survival under interrupted power.

## Space admission and the full-partition fallback

Installer admission combines filesystem availability with already erased,
clean-marker blocks. Dirty/reclaimable bytes do not satisfy the raw-space gate.
That distinction matters when erasure is broken: filesystem accounting alone
does not establish immediately writable physical space.

The current installation budget is one 16-KiB block, with five additional clean
blocks retained; statfs must report at least 32 KiB available. The pressure
experiment's lower stop threshold does not relax the installer's admission
policy. A successful install on this camera is not physical validation of
every borderline-space refusal or interrupted-write path.

For insufficient installation space, the chosen workflow is **same-camera
backup → patch image → restore**. No runtime `force-gc` route is provided.
The developer observed open `ucamera` descriptors for three config files;
stopping execution does not close those descriptors. SIGTERM is not a
freeze/resume mechanism, and successful ordinary unmount after stopping the
service was not established. Runtime service manipulation was abandoned.

## Evidence fingerprints and reproducibility

The following are SHA-256 hashes of the complete `flash.bin` members, not the
ZIP containers. Each archive passed the preserved-backup checks, including
the recorded three consecutive identical reads.

| Private snapshot label | SHA-256 |
|---|---|
| after-gc-hup-25 | `374220e6ee44bef82e1764e99debbf1f7b903eea4794e56d5b55a629e4a60129` |
| after-reboots | `502d0b3bee256a03658bb51173f6ed944c70e5eaafa298bc9bbe97bae540ff19` |
| after-auto-gc-pressure | `c4b324b5f350b0a66a0c070f1307d169a0686b57eeedc75b24f894f542f17d13` |

Read-only comparison method: validate each archive, compare bytes outside
config, split config into eight 16-KiB blocks, check exact clean-marker/FF
patterns, and scan CRC-valid JFFS2 nodes. Resolve latest directory entries
(inode zero means deletion) and reconstruct live file fragments by version.
An accurate node bit alone does not mean a record belongs to a live file.
Compare reconstructed file contents, and separately count bit transitions
and previously programmed bytes returning to FF.

This testing establishes successful operation on the stated setup, with direct
manual-GC erase evidence and strong automatic-GC evidence. Recovery hold under
an injected mount failure, power-loss behavior, near-full initial state and
hook-only operation on unmodified stock startup remain outside the physical
coverage. The separate driver error-propagation defect is not corrected by
the erase-size hook.

See [STARTUP-HOOKS.md](STARTUP-HOOKS.md) for installation and routine
verification. Repeating the pressure experiment is not required for normal use.

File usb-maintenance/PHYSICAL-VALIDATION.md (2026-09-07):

# Physical USB restore validation

**Initial experiment date:** 2026-09-04  
**Integrated validation date:** 2026-09-06  
**Hardware:** one `EF-S7-V1.0.30B` camera with an Ingenic T23N and ZB25VQ64

This document records the initial destructive investigation and the later
successful physical validation of the integrated USB restore path. It separates
direct observations from remaining limits. Console excerpts have been shortened and all host paths, camera
serials, unit-specific identifiers, and unit-specific image hashes have been
removed.

## Result at a glance

| Question | Result |
|---|---|
| Can the U-Boot HID updater receive a complete image? | **Yes**, on the tested camera: all 2,742 packets were accepted and the RAM-image MD5 matched. |
| Can it erase and write the full 8 MiB flash? | **Yes**, on the tested camera: normal USB returned and an independent three-read ADB backup matched the candidate through HWCONFIG. |
| Did the camera work afterward? | **Yes**: normal HID returned and a live video picture was observed. |
| Does the integrated `cc2camera restore` enter U-Boot reliably? | **Yes**, on the tested supported camera: it dynamically located and corrected the live SFC field, then the stock flag write entered U-Boot without manual preconditioning. |
| Did the complete integrated restore pass physical verification? | **Yes**: one uninterrupted CLI invocation completed pre-write stable reads, flag creation, bootloader transfer/write, normal reboot, and three-read post-write verification. |

The initial test separated a working bootloader transfer from a broken stock
Linux trigger. The implemented restore path now validates the exact supported
kernel and live camera, dynamically prepares the SFC field, and performs that
transition successfully as part of the complete verified operation.

## Relevant flash layout

The 128 KiB JFFS2 config partition is `/dev/mtd5`, at full-flash range
`0x7e0000–0x7fffff`. The Linux daemon stores the two persistent upgrade words
at full-flash offset `0x7f8000`, which is config-relative offset `0x18000` and
the start of the seventh 16 KiB JFFS2 eraseblock.

The requested eight bytes are:

```text
54 44 50 55 a1 03 02 01
```

They decode as `0x55504454` (`UPDT`) and `0x010203a1` (HID transport). SPL
enters the updater only when it reads those values.

## First attempt: trigger corruption instead of upgrade mode

Before the first restore attempt, the target contained a valid JFFS2
cleanmarker:

```text
85 19 03 20 0c 00 00 00 b1 b0 1e e4
```

The normal-mode HID handler attempted to program the upgrade words without
successfully erasing the containing NOR sector. SPI NOR page programming can
change a bit from 1 to 0, but cannot change 0 back to 1. The physical result
was exactly the bitwise AND of the old and requested bytes:

```text
old:       85 19 03 20 0c 00 00 00
requested: 54 44 50 55 a1 03 02 01
result:    04 00 00 00 00 00 00 00
```

The client consequently timed out waiting for bootloader HID:

```text
Entering bootloader HID mode; the 8-byte flag write begins now.
cc2flash: error: timed out waiting for HID a108:ff08
```

UART proved this was not merely a Windows enumeration race. SPL read the
damaged value and continued into ordinary Linux:

```text
flash_flag1 = 0x00000004, flash_flag_2 = 0x00000000
```

No U-Boot metadata or image packet was sent during this attempt, and no
full-flash erase/write began.

On the following Linux boot, JFFS2 also detected the damaged cleanmarker and
tried to erase the affected block. That erase failed:

```text
jffs2: Magic bitmask 0x1985 not found at 0x00018000: 0x0004 instead
the transfer length is error,803,jz_spi_norflash_erase_sector
jffs2: Newly-erased block contained word 0x4 at offset 0x00018000
```

An independently acquired stable backup confirmed that boot through HWCONFIG
was byte-identical to the pre-attempt backup. Changes were confined to config,
including the exact AND result at `0x7f8000`.

## Kernel erase-size mismatch

The running MTD interface reports a 16 KiB erase size:

```text
/dev/mtd5 size:      131072
/dev/mtd5 erasesize: 16384
```

Static disassembly of the exact camera kernel found that
`jz_spi_norflash_erase_sector` selects opcodes only for these internal sizes:

| Internal size | Opcode | Operation |
|---:|---:|---|
| `0x1000` | `0x20` | 4 KiB sector erase |
| `0x8000` | `0x52` | 32 KiB block erase |
| `0x10000` | `0xd8` | 64 KiB block erase |

There is no branch for the configured `0x4000` value. The erase command is
therefore invalid for this 16 KiB configuration, matching the runtime driver
errors above.

For one test boot, `/proc/kallsyms` and the exported driver object were used to
locate the live internal erase-size field. Its physical address was derived at
runtime; it is **not a stable address across boots or devices**. Changing only
that live field from `0x4000` to `0x1000` caused each 16 KiB MTD erase request
to be split into supported 4 KiB sector erases. `flash_eraseall /dev/mtd5`
then completed without driver errors, and all 128 KiB read back as `0xff`.

During that diagnostic experiment, the field was restored to `0x4000`
afterward. The later implementation derives and validates the live pointer,
sets the field only for the restore transition, and relies on reboot to
reinitialize the driver; it remains a temporary preparation rather than a
persistent kernel fix.

## Lab path that reached U-Boot

The experiment then established the following facts:

1. With the live erase-size field temporarily set to `0x1000`, the config
   partition could be erased and formatted as JFFS2.
2. A camera-specific `serial.cfg` was recreated before reboot. The subsequent
   boot mounted config cleanly and the patched startup script recreated the
   ordinary default files. The optional persistent `system.sh` was absent.
3. Normal attempts to remount config read-only failed because `ucamera` kept
   writable descriptors open. BusyBox `mount -f` only faked the operation, and
   SysRq `u` did not remount this JFFS2 mount.
4. Sending `SIGSTOP` to `ucamera` kept its PID visible to `monitor.sh`, so the
   shell watchdog did not reboot the camera. Normal HID and the temporarily
   started ADB service remained reachable.
5. Erasing config while it was still mounted read-write was physically possible
   with `ucamera` stopped, but is filesystem-unsafe and is not an end-user
   procedure.
6. A restore was triggered while `ucamera` was still stopped, so the host timed
   out waiting for a HID response. After `SIGCONT`, the pending handler ran,
   programmed the now-erased flag location, and rebooted.
7. SPL then read the exact requested words and U-Boot enumerated as HID
   `a108:ff08`.

The decisive UART excerpt was:

```text
Upgrade_flag0 = 0x55504454, Upgrade_flag1 = 0x10203a1
...
flash_flag1 = 0x55504454, flash_flag_2 = 0x010203a1
...
Upgrade mode = hid mode!!!
```

This proved that an erased target could accept the normal daemon's eight-byte
program and that stopping `ucamera` was the wrong ordering. The integrated path
therefore leaves `ucamera` running, performs no manual config erase, and keeps
the validated preparation and HID trigger inside one bounded operation.

## Bootloader transfer and full-flash write

Because the original CLI invocation had already exited, a one-off continuation
used the existing validated image/header builders and HID transfer function
against the waiting bootloader. It did not bypass image validation.

The complete 8 MiB image plus its 128-byte header required 2,742 packets. The
host observed the expected ACK sequence and final type-5 success. UART showed
all 16 received-image MD5 bytes matching, followed by the erase and write path:

```text
the whole firmware get,img size = 800000 ,img offset = 0
#####start erase flash#####
*****start write flash*****
Data transfer complete
```

The terminal type-5 success still proves only the RAM-image MD5; U-Boot sends
it before erase/write and does not check or report the SPI operation return
values. The independent readback below is what established write success.

## Independent post-write verification

After normal USB mode returned:

- the camera produced a live video picture;
- temporary root ADB startup succeeded through normal HID;
- `cc2camera backup` obtained three consecutive identical 8 MiB reads in three
  attempts;
- every byte from boot through the end of HWCONFIG (`0x000000–0x7dffff`)
  matched the validated candidate;
- the invariant firmware fingerprint and permanent startup-script patch passed
  strict validation;
- the live JFFS2 config contained the six expected names and no `system.sh`;
- config was not byte-identical to the initial clean image, as expected after
  first boot recreated default files.

Therefore the physical evidence validates the in-order bootloader HID transfer,
full-chip erase/write, normal reboot, video operation, and independent ADB
readback on this one camera.

## Integrated automatic restore validation

The follow-up test exercised PR #10 exactly as implemented, without manually
changing RAM, manually erasing config, stopping `ucamera`, or using a separate
transfer continuation:

1. `cc2camera start-adb --serial <camera>` started temporary root ADB.
2. `cc2camera restore ... --backup ... --serial <camera>` displayed the complete
   write plan and received the literal `RESTORE-CC2` confirmation.
3. The integrated preparation obtained three consecutive identical live flash
   reads, matched them to the preserved backup, dynamically located and verified
   the SFC object and its erase-size member, synchronized pending writes, and
   set/read back `0x1000`.
4. The stock HID trigger entered bootloader mode. All 2,742 transfer packets were
   accepted, U-Boot accepted the image MD5, and full-flash erase/write began.
5. Normal USB returned. After separately confirmed temporary ADB startup, the
   command obtained three consecutive identical post-write reads in three
   attempts.
6. Every boot-stable byte through HWCONFIG matched the candidate. Config changed
   during the required verification boot and was correctly not claimed
   byte-exact.

Sanitized host result:

```text
Validating the live camera and preparing its temporary SFC erase size.
Flash read 3/5 complete; consecutive identical: 3/3
Entering bootloader HID mode; the 8-byte flag write begins now.
Transfer: 100% (2742/2742)
Bootloader accepted the image MD5 and has started erase/write.
Normal mode returned; requiring three consecutive identical flash reads for post-write verification.
Flash read 3/5 complete; consecutive identical: 3/3
Restore complete: three consecutive post-write reads match every boot-stable byte through HWCONFIG.
```

The UART capture independently showed the flag erase/write, exact upgrade words,
SPL recognition, bootloader HID mode, and completed U-Boot write. No
`transfer length is error,803` occurred during the integrated flag operation.
The same error reappeared after Linux rebooted with its ordinary `0x4000`
configuration, confirming again that this preparation is intentionally temporary.

Therefore the integrated `cc2camera restore` path is physically verified end to
end on the supported camera and kernel: stable preflight readback, automatic RAM
preparation, stock trigger, stock bootloader transfer/write, reboot, live normal
USB, and independent stable post-write readback all succeeded.

## Remaining limits

- Physical validation covers one `EF-S7-V1.0.30B`/T23N/ZB25VQ64 camera and
  the exact gated stock kernel. Other board and firmware revisions remain
  unsupported unless separately analyzed and added.
- The live driver-object address must always be derived and verified at runtime.
  Hard-coding the address observed in either experiment would be unsafe.
- The decoded erase loop predicts one 4 KiB physical erase for the eight-byte
  flag operation, but that precise collateral footprint was not independently
  measured before the subsequent full-flash write. The preserved backup remains
  mandatory.
- Reboot restores the original `0x4000` configuration; this is preparation for
  the stock update transition, not a persistent fix for later JFFS2 erase/GC.
- Automatic retransmission is not implemented. Both successful physical
  transfers proceeded in order without requesting retransmission.

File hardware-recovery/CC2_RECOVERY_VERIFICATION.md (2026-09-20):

# CC2 camera recovery tool — independent verification

> **Historical verification record:** This document describes the v1.1.0 tool
> and the two physical dumps available on 2026-08-22. It is retained as an
> audit record, not as the current compatibility contract. See
> [TECHNICAL_DETAILS.md](TECHNICAL_DETAILS.md) for the current supported
> HWCONFIG/identity structures and [TEST_RESULTS.md](TEST_RESULTS.md) for the
> four-camera validation record.

Review date: 2026-08-22  
Reviewed tool: `cc2_sig_tool.py` v1.1.0

## Conclusion

The revised tool correctly recognizes both supplied bricked CC2 camera ROMs, preserves their distinct unit identities, rebuilds their exhausted JFFS2 config partitions, and installs the intended copy-once startup mitigation. It is fail-closed for invariant firmware changes and produces the exact recovery hashes already recorded for both units.

The software-level recovery claim is verified. A new hardware-level recovery claim is not possible from files alone: definitive proof still requires writing a physical bricked camera, obtaining a byte-identical full readback, and observing successful boot/USB enumeration.

## Direct evidence

| Property | Bricked unit A | Bricked unit B |
|---|---:|---:|
| Input SHA-256 | `4325aebe84d70dd937de1790aa48f4b36ee2731def0ee5504ed080e4df13e819` | `ff9c8962abd06a14661db1857f6318b06f6378e93c4d812d96224094063bbcf9` |
| Config non-`FF` use | 98.567% | 98.486% |
| CRC-valid JFFS2 nodes | 630 | 655 |
| Obsolete nodes | 628 | 653 |
| Live names | `serial.cfg` only | `serial.cfg` only |
| Generated SHA-256 | `5939d62a32fd97ab15a5d9b8ab71571831f0f2a30d66019c23deef892905ec09` | `269f1b3b205e2ac30ada7cb98a7aeb9ada2e76786dc14abe95ea9c56dce73d1f` |

The inputs have different serial values, UOIDs, two-byte HWCONFIG check values, and raw config histories. Every supposedly invariant byte has the same fingerprint. For each output:

- boot, kernel, root, all unmodified system bytes, and the complete HWCONFIG partition remain byte-for-byte equal to that unit's input;
- the exact CRC-valid `serial.cfg` payload recovered from that unit is preserved;
- config becomes the canonical minimal JFFS2 image;
- the generated ROM passes the complete validator again.

Unit B's generated SHA-256 equals the permanent hardware-readback hash recorded in the earlier test results. The raw readback was not provided in this review, so that historical file itself could not be independently compared.

## Does the patch fix the stated bug?

Yes, for the specific deterministic boot-write mechanism.

The stock `/home/bashrc.sh` executes five unconditional `cp` commands into the JFFS2-backed `/etc/conf.d` on every boot. JFFS2 is log structured, so rewriting the same logical files still appends new nodes and obsoletes older ones. Both bricked dumps exhibit the expected end state: roughly 98.5% physical use and hundreds of obsolete nodes.

The patch changes each command to the POSIX-shell form:

```sh
[ -f /etc/conf.d/file ] || cp /system/config/file /etc/conf.d/file
```

After recovery, the minimal config contains only `serial.cfg`. The five defaults are therefore created once on the first successful startup. On later boots their destination files exist, so those five persistent writes stop. The patched script has the same 5,699-byte length as stock and passes `sh -n`.

This mitigates the observed write leak; it does not fix the underlying Ingenic SFC/JFFS2 erase or garbage-collection defect. Other persistent writers could still consume the partition.

## Does it recover an already bricked image?

At the image level, yes. Both supplied bricked configs retain one unambiguous CRC-valid serial but are almost physically exhausted. The builder replaces that log with a small CRC-valid JFFS2 partition containing the same serial and ample erased space, then applies the permanent startup mitigation.

The result for both real units is deterministic and matches the previously documented output hashes. This is sufficient to verify image construction, identity preservation, and filesystem consistency. Only an actual flash/readback/boot test can establish electrical and runtime recovery for a particular board.

## Historical cross-serial behavior and residual risk

At the time of this review, cross-serial support was directly verified on two
real units and structurally tested on a third synthetic identity.

The validator normalizes the observed five-byte opaque HWCONFIG extension and
excludes the known unit-specific HWCONFIG fields and mutable config log from
invariant comparison. It still requires:

- exact firmware and known HWCONFIG-prefix hashes everywhere else;
- a type-12 payload with one of the physically observed lengths, 256 or 261;
- the exact stock or audited patched SquashFS window;
- a 94-byte UOID with the observed character structure;
- exactly one recoverable serial matching the observed serial format;
- valid JFFS2 CRCs and only known config filenames.

Every raw image requires three byte-identical physical reads by default. `--allow-fewer-reads` is an explicit reduced-confidence escape hatch and is recorded with a warning in generated artifacts.

The proprietary full serial↔UOID derivation and the meanings of the two-byte
HWCONFIG check value and five-byte record extension remain unknown. The tool
therefore validates the serial and UOID structures independently, records the
extension length and hash, and preserves all of those bytes exactly. It cannot
prove their full semantic relationship. This is the principal residual
cross-device identity risk. Requiring multiple physical reads minimizes
corruption risk without inventing an unverified formula.

## Auditability improvements in v1.1

The earlier ~32 KiB Base85-encoded XOR blob was removed. The patch is now produced from:

1. the complete readable old and new shell blocks;
2. exact hashes for the stock XZ stream, decompressed fragment, stock script, patched script, patched decompressed fragment, patched XZ stream, and final 32 KiB window;
3. deterministic standard-library LZMA2/XZ construction with a 128 KiB dictionary;
4. one explicit SquashFS fragment-size update.

An independent read-only SquashFS v4/XZ parser extracted `bashrc.sh` from the stock and generated ROMs. The extracted files were byte-for-byte equal to the supplied original and patched scripts, respectively.

Additional safety changes:

- `--keep-config` refuses any exhausted or noncanonical partition;
- every raw image requires three matching reads by default unless reduced confidence is explicitly accepted with `--allow-fewer-reads`;
- readback verification first validates that the expected image is patched and canonical;
- output overwrite cannot recursively delete inputs, subdirectories, symlink targets, or unrelated files;
- generated Bus Pirate examples use documented `dev` and `spispeed` parameters and do not silently enable target power. See the [official flashrom Bus Pirate documentation](https://flashrom.org/supported_hw/supported_prog/buspirate.html).

## Regression results

All executed tests passed:

- both actual bricked inputs generated their exact expected outputs;
- an already patched canonical output rebuilt idempotently with no write region;
- a structurally valid unseen serial/UOID with three matching reads was accepted and preserved;
- one-bit mutations in kernel or the system patch window were rejected;
- structurally valid serial and UOID values with different prefixes were accepted and preserved;
- unknown contents in the observed five-byte type-12 extension were accepted
  and preserved, while short and unobserved record lengths were rejected;
- keeping either exhausted config was rejected;
- a one-bit programmer readback mismatch was rejected;
- the deterministic XZ, readable source replacement, JFFS2 writer/parser, strict post-build validation, and shell syntax checks all passed.

## Recommended hardware validation sequence

1. Make three full reads without moving the clip; require identical SHA-256 hashes.
2. Run `analyze`, then `build` with the other two reads supplied via `--confirm`.
3. Verify the exact flash part voltage and all SPI connections from the marking/datasheet.
4. Write only the generated layout regions. Do not power the target simultaneously from USB/device power and programmer target power.
5. Without disturbing the connection, make a full 8 MiB readback.
6. Run the tool's `verify` command and require byte-for-byte identity.
7. Disconnect the programmer, restore normal power, and observe boot and USB enumeration.

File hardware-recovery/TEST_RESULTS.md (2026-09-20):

# Validation and regression test results

Tool version: `1.2.1`

Review date: 2026-09-04

## USB-backup interoperability regression tests

- A strict `cc2flash-backup-v2` ZIP with exactly `flash.bin` and
  `manifest.json` is accepted without extraction.
- Image size, SHA-256, MD5, boot fingerprint and acceptance basis, exact MTD
  partition map, and three-consecutive-of-five acquisition policy are checked
  before the flash image reaches the firmware validator.
- A manifest/image hash mismatch and any extra ZIP member are rejected.
- The validated manifest contributes exactly three evidenced physical reads,
  satisfying the build gate for every image without `--allow-fewer-reads`.
- The hardware-recovery self-test and all nine focused
  interoperability/config-mode tests pass on Python 3.12.
- Oversized zero-filled fragments are rejected before allocation. Zlib
  fragments are rejected before decompression when their declared size exceeds
  the config partition, and decompression output is bounded when the stream
  expands beyond its declared size.

## Attached current USB-backup interoperability

The locally supplied current-format ZIP was used only as a test input and was
not added to the repository. Its manifest records three consecutive identical
reads, the known bootloader fingerprint, and the camera's six-partition map.

- The unmodified ZIP passed strict archive, evidence, partition-map, firmware,
  identity, and JFFS2 validation without reduced-read overrides.
- Default clean-data correctly refused the live unfamiliar `system.sh` name.
- Clean-data with `--wipe-unknown-config` and preserve-data both built directly
  from the ZIP without extraction.
- Preserve-data retained the contents and relevant metadata of all seven live
  regular files: `dev_config.cfg`, `serial.cfg`, `system.sh`, `uvc.attr`,
  `uvc.config`, `uvc2.attr`, and `uvc_dualstream.config`.
- The preserved config contains one cleanmarker, one dirent and one inode per
  file, and zero obsolete nodes.
- Both generated full images passed USB maintenance's image safety checks and
  same-camera allowed-region comparison against `flash.bin` from the ZIP.

The table below retains the earlier two-unit regression record. Unit B's clean
output/readback equality was re-executed with the newly attached files; unit A
was not present in this interoperability run.

## Full-ROM regression record

| Input | Unit identity | Input SHA-256 | Config state | Generated SHA-256 | Result |
|---|---|---|---|---|---|
| Shared bricked camera | distinct unit A | `4325aebe84d70dd937de1790aa48f4b36ee2731def0ee5504ed080e4df13e819` | 98.567% non-`FF`; 628 obsolete nodes; only `serial.cfg` live | `5939d62a32fd97ab15a5d9b8ab71571831f0f2a30d66019c23deef892905ec09` | passed |
| Second bricked camera | distinct unit B | `ff9c8962abd06a14661db1857f6318b06f6378e93c4d812d96224094063bbcf9` | 98.486% non-`FF`; 653 obsolete nodes; only `serial.cfg` live | `269f1b3b205e2ac30ada7cb98a7aeb9ada2e76786dc14abe95ea9c56dce73d1f` | passed |

Both inputs have the same exact invariant firmware fingerprint and stock SquashFS window, but different serials, UOIDs, three-byte HWCONFIG check values, and raw JFFS2 histories. Each output preserves its own complete HWCONFIG partition and exact recovered `serial.cfg` payload.

The attached unit-B hardware readback was independently hashed and compared
byte-for-byte with the newly generated clean-data image in this review.

## `12PSSSS3` identity variant validation

Validation date: 2026-09-20

A fourth physical camera supplied a stable multi-read dump with SHA-256
`574c71e6572093ea1b65c3ca9c3e5e1dd1e55d71443ca7b282db8ce700c45c85`.
The contributor compared multiple independent reads by MD5; one representative
raw dump was available for the local software test and was not added to the
repository.

- Boot, kernel, root, and every invariant system byte match the supported
  firmware exactly.
- The stock startup-script window is present.
- The type-12 record has the observed 261-byte shape and a second observed
  opaque extension value.
- The serial and UOID use the structurally matching `12PSSSS3` family.
- The dump established a three-byte unit check at `0x7D200A–0x7D200C` and a
  calendar-shaped field at `0x7D206F–0x7D2072`, decoding to `2026-03-02`.
- After normalizing those validated unit fields, every remaining HWCONFIG byte
  matches the existing cameras exactly.
- Config is 98.761% non-`FF`, with 634 CRC-valid nodes, 632 obsolete nodes, and
  only `serial.cfg` live.
- Strict inspection passed. A local serial-only recovery build passed complete
  post-build validation and produced SHA-256
  `c28fdd1865219a82dd815bea3333acba91091ac809721b130e805adb53062b66`.
  The build preserved HWCONFIG byte-for-byte and changed only the audited
  startup-script window and config partition.

The local recovery build used the explicit reduced-read option because only
one representative file, rather than all independently acquired copies, was
available in the test environment. This is software validation only; the
generated image was not flashed or boot-tested.

## Independent filesystem and patch checks

- A separate read-only SquashFS v4/XZ parser extracted `/home/bashrc.sh` from stock and generated images.
- The stock extraction was byte-for-byte equal to `bashrc-original.sh` (`984e1d34…a48417d`).
- The generated extraction was byte-for-byte equal to `bashrc-patched.sh` (`eab95c4e…e0f88`) and passed `sh -n`.
- The v1.1 tool contains no Base85/XOR binary patch. It applies a readable shell block replacement, constructs the exact XZ container, and reproduces the same patched 32 KiB SHA-256 (`36e9b9b2…51b2b`).
- Recovered configs contain one cleanmarker, one `serial.cfg` dirent, one uncompressed inode, and valid JFFS2 header/node/name/data CRCs; all remaining bytes are `FF`.
- The generated ROMs pass the complete strict validator again after construction.

## Regression and rejection tests

- The observed type-12 HWCONFIG records with 256-byte and 261-byte payloads are
  accepted. Unknown contents in the five-byte extension are normalized and
  preserved exactly.
- A payload shorter than the known 256-byte prefix, unobserved 257-, 262-, and
  512-byte payloads, and a non-type-12 record are rejected. Mutations after the
  declared extension remain covered by invariant validation.
- A locally reconstructed full image with the third camera's invariant variant
  bytes passed strict analysis and recovery generation; the generated image
  retained HWCONFIG byte-for-byte. This is software validation, not a physical
  flash or boot test of that camera.
- Four distinct real serial/UOID identities were inspected; the available
  full-ROM regression inputs were accepted and preserved.
- An additional structurally valid synthetic identity with two confirmation
  reads (three total): accepted and preserved.
- A raw image with only one read: rejected unless `--allow-fewer-reads` is explicit.
- One-bit kernel mutation: rejected.
- One-bit system-patch-window mutation: rejected.
- Structurally valid serial and UOID values with different prefixes: accepted
  and preserved independently.
- `--keep-config` on either exhausted bricked partition: rejected.
- One-bit full-programmer readback mismatch: rejected with the affected region.
- Rebuilding an already patched canonical image: idempotent; no write region reported.
- Existing output directory containing an unknown entry: rejected instead of deleting it.

## Scope of the recovery claim

Software-level recovery is verified: the available bricked dumps are transformed into strict, canonical images with the documented hashes, readable patched startup logic, preserved unit identity, and valid filesystem structures. One output also equals the earlier recorded permanent readback hash.

Hardware-level recovery is not newly proven by this review. That requires flashing a physical bricked camera, making a full byte-identical readback, and observing a successful boot/USB enumeration. The tool's generated `FLASHING.txt` makes that the required final validation step.

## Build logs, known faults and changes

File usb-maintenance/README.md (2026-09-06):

# CC2 camera USB maintenance

Start with the repository's
[camera identification and prevention guide](../README.md#first-identify-your-camera).
It determines whether this work applies and presents the supported USB backup,
preventive-image build, restore, and verification sequence.

The current detailed installation, backup, restore, API, limitation, and test
documentation remains in the [USB-maintenance reference](REFERENCE.md).

Before considering a write, also read:

- [Project status](PROJECT-STATUS.md)
- [Physical USB restore validation](PHYSICAL-VALIDATION.md)
- [SFC restore preparation](SFC-RESTORE-PREPARATION.md)
- [Protocol documentation](PROTOCOL.md)
- [Reverse-engineering evidence](EVIDENCE.md)

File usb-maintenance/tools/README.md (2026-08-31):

# Analysis helpers

These dependency-free tools make the static analysis reproducible without
redistributing the supplied firmware:

- `squashfs_extract.py` reads the XZ-compressed SquashFS 4 images used by the
  dump and extracts their files read-only.
- `mips32_disasm.py` is the small little-endian MIPS32/MIPS32r2 disassembler
  used for the address anchors in `EVIDENCE.md`.
- `mips_pic_xrefs.py` locates PIC/GOT references to strings in stripped MIPS
  ELFs and the linked U-Boot image.

Run each tool with `--help` for its exact arguments.  Never run an extractor
against a mounted device; give it an offline image file.

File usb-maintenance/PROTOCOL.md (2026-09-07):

# Elegoo Centauri Carbon 2 stock-camera interaction protocol

**Firmware-specific reverse-engineering reference — updated 2026-09-04**

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

## 1. Evidence, scope, and confidence

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

Confidence labels used here:

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

## 2. System and flash layout

The camera uses two distinct update stages:

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

The 8 MiB flash map is:

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

The persistent upgrade words are at flash offset `0x7f8000`, inside `mtd5`.

## 3. USB identities and transports

### 3.1 Normal Linux mode

The active configuration contains:

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

### 3.2 Bootloader HID mode

The U-Boot USB device descriptor is:

```text
12 01 00 02 00 00 00 40 08 a1 08 ff 00 01 00 00 00 01
```

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

### 3.3 Bootloader CDC mode

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

## 4. Normal-mode HID framing

### 4.1 Report layout

Requests and responses are fixed at 1,024 bytes:

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

### 4.2 CRC algorithm

The CRC is a nonstandard reflected use of polynomial `0x1021`:

```python
def cc2_crc16(data: bytes) -> int:
    crc = 0xffff
    for byte in data:
        crc ^= byte
        for _ in range(8):
            old_lsb = crc & 1
            crc >>= 1
            if old_lsb:
                crc ^= 0x1021
    return crc & 0xffff
```

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

### 4.3 Parser status values

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

### 4.4 Top-level command dispatch

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

## 5. Complete normal-mode command catalog

### 5.1 Version query

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

The file is opened with mode `r+`. Extra request payload is ignored.

### 5.2 Configuration commands (`0x2xxx`)

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

GET semantics:

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

SET semantics:

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

### 5.3 Linux arbitrary-file upload commands (`0x3xxx`)

This family is host-to-camera only. It has no download or file-read operation.

Internal states are:

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

```mermaid
stateDiagram-v2
    [*] --> Idle
    Idle --> NeedPath: 3000 init
    NeedPath --> Receiving: 311x / 3120 / 3150 / 31f0
    Receiving --> Receiving: 3200 type 1
    Receiving --> Ready: 3200 type 2
    Ready --> Idle: 3300 success
    Receiving --> Error: packet error
    Ready --> Error: commit error
```

All 13 recognized commands are:

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

Destination selection details:

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

`0x3200` data packets use the normal report fields as follows:

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

`0x3300` commit behavior is:

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

### 5.4 Upgrade-mode trigger (`0x4xxx`)

The conventional HID-mode request uses command `0x4000`, frame type `1`, and
exactly eight payload bytes:

```text
54 44 50 55 a1 03 02 01
```

These are two words:

```text
word0 = 0x55504454
word1 = 0x010203a1
```

The complete meaningful prefix of the 1,024-byte request, including CRC, is:

```text
01 5a 5a 00 40 01 08 00 00 00 00 00 f8 0e
54 44 50 55 a1 03 02 01
```

The remainder is zero padding.

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

SPL checks `word0`. Main U-Boot interprets `word1` as:

| `word1` | Transport |
|---:|---|
| `0x010203a0` | CDC |
| `0x010203a1` | HID |
| any other value | HID default |

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

#### Physical trigger failure

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

## 6. Bootloader updater protocol

### 6.1 HID envelope

A bootloader HID OUT report is:

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

### 6.2 Common updater frame

Host-to-device magic is `80 00 ee`; device-to-host magic is `81 00 ee`.

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

All observed frame types are:

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

### 6.3 Type-1 transfer metadata

A canonical type-1 frame is 17 bytes:

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

U-Boot calculates:

```text
frame_size   = subpack_size + 11
packet_count = ceil(transfer_size / subpack_size)
batch_size   = frame_size * packets_per_ack
batch_count  = ceil(packet_count / packets_per_ack)
```

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

### 6.4 Type-3 data and ACK semantics

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

The ACK's four-byte payload is **not a constant**. It is:

```text
u32le(next packet number the device expects)
```

Examples when `packets_per_ack = 1`:

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

### 6.5 Transfer stream and 128-byte image header

The bytes carried by type-3 frames form one logical stream:

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

```text
erase(flash_offset, image_length)
write(flash_offset, image_length, transfer_buffer + 128)
```

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

## 7. End-to-end host sequence

A correct HID-mode flow is:

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

## 8. Commands that do not exist

Exhaustive control-flow review found no USB-accessible operation for:

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

## 9. Readback and guarded ADB startup

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

The root SquashFS `/etc/init.d/rcS` supplies the missing boot mechanism. It:

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

The client exposes the two startup mechanisms as separate `start-adb` and
`install-adb-startup` commands. `backup` does not enter either path. Without any
setup, the stock gadget always exposes an ADB USB transport without a running
daemon, so the pre-daemon host state is `Ucamera001 offline`, not an absent
device. Only temporary `start-adb` accepts that offline state or an absent selected
ADB device as a reason to attempt HID startup. Persistent `install-adb-startup`
requires already-online root ADB and a preserved backup. A missing local ADB executable,
timeout, multiple or unauthorized devices, a non-root shell, malformed
partition map, failed/short read, or unstable acquisition remains a refusal.

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

### 9.1 Temporary upload-command start

`cc2camera start-adb` uses two confirmed bugs without weakening
the general upload-path API:

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

The client sends this exact sequence:

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

At step 4 the first shell command is exactly:

```sh
rm /tmp/.cc2flash-adbd-bootstrap;/bin/adbd&
```

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

### 9.2 Persistent startup hook

The supported command is `cc2camera install-adb-startup --backup BACKUP.zip`.
It requires already-online root ADB, a preserved same-camera backup, three
consecutive stable live reads and sufficient clean config space. Consent is
`ENABLE-ADB` or explicit `--yes`.

It stages and reads back files in tmpfs, then installs the shared
`/etc/conf.d/system.sh` runner and `enabled/90-adb.sh` through ADB filesystem
operations. It verifies persistent bytes and permissions. Different contents at
`system.sh` or the selected `enabled/90-adb.sh` path are refused, not overwritten.
Unrelated regular hooks in `enabled/` remain and execute in filename order.
No HID upload transaction is used.
Restart manually after success. For offline ADB, first run `start-adb`, then
`backup`. See [startup hooks](../docs/STARTUP-HOOKS.md).

### 9.3 Stable-read and boot-hash gates

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

```text
5602ec961b4410ccceea0d4910e4fa768c6998bd4ba86143ba50855bdd0b7a54
```

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

Persistent hook installation writes config files and requires its backup before
mutation. Normal HID offers no file download/readback; it is used only by the
separate temporary ADB-start mechanism described above, not the hook installer.

## 10. Client compatibility status

| Component | Current client behavior | Firmware behavior | Status |
|---|---|---|---|
| Bootloader data ACK | parses `u32le(next_expected_packet)` and requires the next in-order value; aborts on retry request | payload is the next expected packet, including a batch restart after an error | In-order 2,742-packet physical transfer passed; retransmission remains unimplemented and untested |
| Persistent ADB start | guarded ADB command installs shared runner and ADB hook after backup and space checks | `rcS` executes the persistent hook next boot | Offline-tested; shared runner and persistent ADB physically verified on one camera |
| Temporary ADB start | separate command sends an immutable no-space upload target, tolerates only final-commit failure/disconnect, and polls across the old transport closing | unquoted `rm` target starts `/bin/adbd`; literal `fopen` then fails | Physical startup and root shell verified on Windows |
| Backup acceptance | requires three consecutive identical full reads within five attempts, gates on the known or explicitly accepted boot hash, and publishes one verified ZIP | ADB sync/`pull` can read each raw MTD device | Complete 8 MiB live acquisition verified; strengthened read/archive policy is offline-tested |
| Public Python catalog | exposes all 57 exact normal commands, every `0x4xxx` match, and boot types 1/2/3/5 with builders/decoders | complete analyzed dispatcher/state-machine surface | Implemented with source comments and exhaustive offline mapping tests |

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

## 11. Static-analysis anchors

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

## 12. Runtime uncertainties

The following remain hardware-unverified or unknown:

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

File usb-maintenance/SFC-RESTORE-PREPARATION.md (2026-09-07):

# SFC preparation for stock HID restore

## Scope and prerequisites

`restore` temporarily changes one internal Linux SFC erase-size word before
asking the stock HID updater to write its bootloader flag. It does not install
an updater, replace bootloader software, erase config manually, or stop
`ucamera`. The subsequent stock bootloader transfer still replaces the full
8 MiB flash with the explicitly confirmed, same-camera recovery image.

Use an independently preserved three-consecutive-read backup. Keep dumps outside
the repository. The recovery image must match it outside the audited system
patch window and config partition. Start root ADB explicitly before restore:

```sh
cc2camera start-adb --serial <camera-serial>
cc2camera restore fixed.bin --backup backup.zip --serial <camera-serial>
```

The preparation requires exactly one online ADB device and one normal camera
HID interface, with matching serials. The serial is a transport-selection check,
not proof of unit identity: stable live flash is also compared with the backup,
including HWCONFIG. Unknown kernels, layouts, instructions, pointers, values,
ambiguous devices, and failed checks are refused without a HID upgrade request.
Read-only commands do not perform this preparation.

## Exact supported kernel and pointer derivation

The full kernel partition at `0x040000–0x18ffff` must have SHA-256:

```text
0855c3a93f571c3130f1bdd38469e7c806ce713550a3ce536c81167579341545
```

This gate is checked on the local backup before hardware access and again on
the stable live image. The known kernel uImage loads at `0x80010000` and contains
an LZMA-compressed payload. The following is independently decoded MIPS
interoperability information, not vendor source:

| Virtual instruction address | Instruction | Meaning |
|---|---|---|
| `0x801f06d4` | `lui s3, 0x8044` | Upper part of global address |
| `0x801f06e0` | `lw a0, -20080(s3)` | Load object pointer from `0x8043b190` |
| `0x801f0764` | `lw v0, 16(v0)` | Recovery erase-loop stride at object `+0x10` |
| `0x801efca4` | `lw v0, 16(s1)` | Sector opcode selection from the same member |

The driver selects sector-erase opcode `0x20` for `0x1000`, `0x52` for `0x8000`,
and `0xd8` for `0x10000`. Its `0x4000` configuration has no corresponding branch.

Live `/proc/kallsyms` must contain exactly one entry for each:

| Symbol | Virtual address |
|---|---|
| `recovery_norflash_erase` | `0x801f06cc` |
| `jz_spi_norflash_erase_sector` | `0x801efc74` |
| `direct_erase_norflash` | `0x801f080c` |

The implementation also checks the four live instruction words above. These
fixed code/global addresses apply only to the exact gated kernel, not other
builds. The **object address is read afresh on every invocation**:

```text
object_virtual = read32(0x0043b190)
erase_size_physical = object_virtual - 0x80000000 + 0x10
```

The observed `0x818b4800` pointer yielded `0x018b4810`. That heap address is not
hard-coded. The pointer must be aligned and in the bounded cached 64 MiB RAM
window above kernel/static memory; the inspected object member range must fit.
The MTD partition map must retain its known `0x4000` geometry, and the internal
member must be either `0x4000` or an already-patched `0x1000`.

## Mutation and failure behavior

After all preflight reads, preparation runs `sync`, checks device selection
again, and rechecks the object pointer and old member value inside the same
remote shell invocation as the write. It writes only `0x1000`, reads it back,
requires an explicit success marker, and independently rereads the pointer and
member before permitting the HID trigger. Already-patched state is verified
without rewriting it. Legacy ADB shell exit status alone is not considered
evidence of remote success. Each ADB subprocess retains its bounded timeout.

No rollback to `0x4000` is attempted. A failure after the write may leave the
live field patched; the error says so, and no automatic retry or HID trigger
follows. A later HID timeout may mean a request is pending or the camera has
already rebooted: inspect device state before deciding what to do next. Do not
disconnect power during a bootloader erase/write. Reboot reinitializes the
driver, so this is not a persistent kernel fix.

The stock flag operation requests eight bytes at full-flash `0x7f8000`
(`/dev/mtd5` offset `0x18000`). The decoded loop and opcode selection predict a
single 4 KiB erase, followed by the flag program. **Its exact physical footprint
was not independently measured before the subsequent full-flash restore.**
The flag sector belongs to mounted JFFS2 and can contain live records; successful
upgrade entry does not promise config preservation if the subsequent restore
fails. The preserved backup remains essential.

## Physical evidence and integrated validation

The first supplied UART log and host transcript established this manual
sequence on the tested camera:

1. Start temporary root ADB through the existing normal-HID command.
2. Sync and manually set/read back the live field as `0x1000`.
3. Run ordinary `cc2camera restore`, leaving `ucamera` running and not manually
   erasing config.
4. Complete all 2,742 packets, return to normal USB, and obtain three consecutive
   identical post-write reads matching every boot-stable byte through HWCONFIG.

Sanitized UART observations:

```text
erase_flash addr=8355840,len=8
write_flash offset=8355840,size=8
Upgrade_flag0 = 0x55504454, Upgrade_flag1 = 0x10203a1
flash_flag1 = 0x55504454, flash_flag_2 = 0x010203a1
Upgrade mode = hid mode!!!
```

The flag operation did not emit the prior erase error. However, the subsequent
Linux boot again emitted `transfer length is error,803,jz_spi_norflash_erase_sector`,
and the developer read back `0x4000`. The startup-script mitigation does not
permanently repair this kernel erase path. Config was deliberately not claimed
byte-exact after the verification boot.

The follow-up test exercised the integrated PR #10 command without any manual
RAM edit or other preconditioning. It obtained three consecutive identical
pre-write reads, completed all automated SFC pointer/instruction/value checks,
set and verified the live field, entered stock bootloader HID, transferred all
2,742 packets, returned to normal USB, and obtained three consecutive identical
post-write reads. Those reads matched every boot-stable byte through HWCONFIG;
config was correctly reported separately after first-boot changes.

Sanitized host result:

```text
Validating the live camera and preparing its temporary SFC erase size.
Flash read 3/5 complete; consecutive identical: 3/3
Entering bootloader HID mode; the 8-byte flag write begins now.
Transfer: 100% (2742/2742)
Normal mode returned; requiring three consecutive identical flash reads for post-write verification.
Flash read 3/5 complete; consecutive identical: 3/3
Restore complete: three consecutive post-write reads match every boot-stable byte through HWCONFIG.
```

The accompanying UART capture showed the flag erase/write, exact upgrade words,
SPL recognition, bootloader HID mode, and completed U-Boot write. The integrated
flag operation emitted none of the earlier erase errors. Linux later returned
to its ordinary `0x4000` field and its unrelated runtime erase errors, as
expected for a temporary preparation.

Offline synthetic tests cover preparation success and refusal paths, dynamic
heap addresses, matching transport selection, kernel and instruction gates,
stable-read failures, pointer bounds, unexpected values, sync failure, guarded
write failure, readback failure, restore ordering, and absence of a HID trigger
on refusal. Existing post-restore readback tests remain in place. The supplied
kernel was independently decoded locally; neither it nor either raw log is
committed.

**Hardware-verified:** the integrated automatic preparation and complete restore
passed physical write and three-read readback verification on the supported
camera and exact gated kernel. Other firmware revisions and the precise
pre-transfer collateral erase footprint remain unverified.

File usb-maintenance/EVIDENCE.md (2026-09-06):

# Static-analysis and runtime evidence

For the first destructive physical restore experiment—including the failed
normal-mode trigger, kernel erase-size mismatch, successful bootloader write,
and independent readback—see
[PHYSICAL-VALIDATION.md](PHYSICAL-VALIDATION.md). Raw dumps, UART logs, host
paths, serials, and unit-specific hashes are intentionally not published.

## Inputs

| Artifact | Size | SHA-256 |
|---|---:|---|
| supplied SPI dump | 8,388,608 | `269f1b3b205e2ac30ada7cb98a7aeb9ada2e76786dc14abe95ea9c56dce73d1f` |
| recovered `/bin/hid_update` | 19,048 | `bcbdd698b4b9208f73f7ef1f9846b3a96130a1bcc5c118c0e71543cf4e1ed503` |

Recovered `/bin/hid_update` MD5 is
`8091751fdd4d0d50ea31901663797a86`, matching the task's known binary.

## Flash mapping

Magic and filesystem parsing confirm:

| Flash range | Content |
|---|---|
| `0x000000–0x03ffff` | SPL and U-Boot |
| `0x040000–0x18ffff` | uImage Linux kernel |
| `0x190000–0x2e7fff` | SquashFS root |
| `0x2e8000–0x7cffff` | SquashFS system |
| `0x7d0000–0x7dffff` | plaintext HWCONFIG partition |
| `0x7e0000–0x7fffff` | JFFS2 config partition |

The dependency-free extractor in `tools/squashfs_extract.py` handles the two
XZ-compressed SquashFS 4 filesystems in this dump.  Extracted vendor files and
the supplied dump are not redistributed with this project.

## Linux updater anchors

The recovered MIPS32/uClibc ELF opens `/dev/hidg0` and `/dev/ucamera`.
Disassembly confirms:

| Function | Finding |
|---|---|
| response builder at `0x00401034` | fixed 1024-byte report and normal CRC |
| parser/dispatcher at `0x0040123c` | magic, CRC, status, command groups |
| configuration GET at `0x00401cd0` | reads one of 21 keyed values |
| configuration SET at `0x00402038` | tail-buffered keyed rewrite and zero-padding |
| configuration dispatcher at `0x004024c0` | all 42 even/odd GET/SET commands |
| upload initialization at `0x00402830` | allocates 16 MiB + 512-byte receive buffer |
| upload packet append at `0x004028dc` | sequence/length/final-packet handling |
| upload commit at `0x004029f0` | shell remove, file write, chmod, optional daemon backup |
| upload dispatcher at `0x00402e3c` | all 13 recognized `0x3xxx` commands and five states |
| high-nibble `0x4000` branch | write/read eight bytes at flash `0x7f8000`, reply, reboot |

The transition ioctls are `0x2000550c` (write) and `0x2000550d` (read), with a
driver request length of eight bytes.

## SPL anchors

The SPL is in the first flash boot region and its analyzed code maps directly
from flash offset zero to the linked `0xf0000000` region. At linked address
`0xf0001c28` it reads eight bytes from SPI offset `0x7f8000`. At
`0xf0001c54` it constructs and compares `0x55504454`.

## Main U-Boot mapping

The main U-Boot binary starts at flash offset `0x6800`, linked at
`0x80100000`.  Equivalently, a flash file offset maps to virtual address:

```text
VA = 0x800f9800 + flash_offset
```

Its canonical PIC global pointer is `0x80136ef0`.

| Address / file offset | Finding |
|---|---|
| file `0x354bc` | HID USB descriptor, `a108:ff08` |
| file `0x35607` | HID report descriptor, ID 1 and 3071-byte reports |
| `0x80117948` | host-frame magic and additive-checksum validator |
| `0x801179ec` | device-frame builder (`81 00 ee`) |
| `0x80117d1c` | complete metadata/data receive state machine |
| `0x801186ac` | SPI flash initialization |
| `0x80118714` | read flags and select CDC/HID transport |
| `0x8011b9d8` | HID response envelope; fixed 3072-byte USB request |
| `0x80119620` | MD5 implementation |

Within `0x80117d1c`, the only accepted host types are 1 and 3.  The final path
copies the first 128 bytes to a local header, computes MD5 over the following
`header.image_size` bytes, compares header bytes 12–27, and invokes the SPI
object's erase and write methods using header words at offsets 4 and 8.

The metadata branch calls the host-frame validator at `0x80117948` but does not
branch on its return value before copying ten payload bytes. The data branch at
`0x801181d8` does test the validator result. This establishes that metadata magic
and type are checked by the outer branch while metadata length/checksum are not
fully enforced; type-3 checksums are enforced.

## ADB startup and backup path

The extracted root filesystem contains `/bin/adbd` and BusyBox. Both active
system camera configurations contain `adb_en :1`, and strings in `adbd` include
its root-service paths. The default image does not directly launch `adbd`.

The root SquashFS `/etc/init.d/rcS` does, however, contain a generic persistent
startup hook. Its established boot order is:

1. identify the partition named `config`;
2. mount its JFFS2 filesystem at `/etc/conf.d`;
3. test for `/etc/conf.d/system.sh` and execute it when present; and
4. only then mount the system SquashFS and run `/home/bashrc.sh`.

Because `/bin/adbd` is in root SquashFS, the exact file contents `/bin/adbd &`
are valid at that point. The device owner independently runtime-verified that
manually creating this file starts ADB after restart. The normal-HID uploader's
ability to select an arbitrary persistent path, append the 11 content bytes,
remove/recreate the target, and chmod it `0777` is statically confirmed at the
Linux updater anchors above. The persistent-file client HID sequence remains
runtime-unverified in this analysis. The separate temporary command-injection
sequence has since been verified on physical hardware as described below.

## Live Windows ADB transport validation

The device owner ran the client-generated temporary startup sequence against a
physical camera on Windows 11 with Google ADB 35.0.2. The sequence started the
stock daemon, changed `Ucamera001` from `offline` to `device`, and provided a
root interactive shell. The old composite transport first returned
`error: closed`, establishing the need for bounded state polling after HID.

The same session compared the daemon's read services:

| Probe | Result |
|---|---|
| `adb shell id` | success: `uid=0(root) gid=0(root)` |
| `adb exec-out id` | failure: `error: closed` |
| `adb shell cat /proc/mtd` | success; expected six-partition map, with doubled CR on Windows |
| `adb pull /proc/mtd` | success: 227 bytes |
| camera `md5sum /dev/mtd4` | `56392b3d32797a089432c7b633ef921f` |
| `adb pull /dev/mtd4` | success: 65,536 bytes; local MD5 matched camera |

The pulled `mtd4` SHA-256 was
`ff1d60111d2517e1423a0b9c72b7b3c62e9388e54217929cbd33e2d16909958c`.
This establishes ADB sync/`pull` as a byte-preserving Windows transport for a
raw MTD character device on this firmware. A subsequent client invocation
successfully acquired and published a complete 8 MiB image:

| Property | Value |
|---|---|
| Full-image SHA-256 | `bccc6818a998d1c143c94543194e2d314cdee7a5f43b62db1fc6bb0b038c22a7` |
| Full-image MD5 | `245763ac1fd9a6afdc79450886266a09` |
| 256 KiB boot SHA-256 | `5602ec961b4410ccceea0d4910e4fa768c6998bd4ba86143ba50855bdd0b7a54` |

Comparison with the supplied reference image showed byte identity for boot,
kernel, root, system, and HWCONFIG; differences were confined to the live JFFS2
config partition. The boot SHA-256 above is therefore the client's built-in
known reference. The first same-boot acquisition attempt failed the then-current
two-read equality gate, while the next invocation succeeded. This motivated the
stronger policy of requiring three consecutive identical images while allowing
at most five attempts for live state to settle.

The stable-read gate precedes the boot-hash gate. An unknown boot hash is not
reported or accepted from a lone read: it is exposed only after three
consecutive full images agree, and it must then be accepted by exact value.

## Corrected bootloader ACK interpretation

The type-2 frame builder receives four bytes from U-Boot state at
`global + 0x6118`. Metadata initialization clears that value, producing the
initial ACK `00 00 00 00`. After a successful nonfinal batch, the state machine
adds `packets_per_ack` to the current absolute packet base, stores the result at
the same location, and transmits it. Thus the type-2 payload is
`u32le(next_expected_packet)`, not four constant zero bytes. The existing
v0.1.0 Python transport's data-ACK comparison is not hardware-compatible.

## Human-readable reconstruction

`source-reconstruction/` contains annotated C-like source for the Linux daemon,
the SPL upgrade gate, and the U-Boot updater. It is explicitly not presented as
the vendor's original source: recovered constants, branches, paths, packet
fields, and state transitions are separated from inferred names and normalized
control flow. `source-reconstruction/TRACEABILITY.md` maps each reconstructed
function to its original virtual address, while `REPRODUCING.md` gives read-only
commands for regenerating the relevant disassembly from the supplied image.

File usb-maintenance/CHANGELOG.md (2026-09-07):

# Changelog

## Unreleased — physically validated USB restore

- Removed whole-image reference hashes from runtime analysis and removed their
  stable-read shortcut. Every raw dump now requires three matching physical
  reads unless reduced confidence is explicitly accepted with
  `--allow-fewer-reads`.
- Documented the initial destructive trigger failure: the stock SFC erase path
  does not handle its configured 16 KiB size, so page-programming over an
  occupied JFFS2 cleanmarker produced the NOR bitwise-AND result instead of the
  upgrade words.
- Added fail-closed restore preparation that dynamically derives and validates
  the live SFC object, temporarily selects the supported 4 KiB erase size, and
  verifies readback before sending the stock HID flag request.
- Physically validated the integrated one-command `cc2camera restore` path on
  the supported camera and exact gated kernel: three stable pre-write reads,
  automatic RAM preparation, stock bootloader entry, all 2,742 packets, full
  8 MiB erase/write, normal reboot, and three stable post-write reads matching
  every boot-stable byte through HWCONFIG.
- Confirmed that the preparation requires no manual config erase, process
  suspension, replacement updater, or bootloader modification.

## v0.8.0 — hardware/USB recovery interoperability

- Bumped the Python client to v0.6.0.
- Added `plan-restore --backup` so the candidate/preserved-backup pair can be
  validated without opening USB.
- Made both `plan-restore --backup` and `restore` require the replacement to
  match the preserved camera backup byte-for-byte outside hardware recovery's
  audited `0x463000–0x46afff` SquashFS window and
  `0x7e0000–0x7fffff` config partition.
- Split strict preserved-backup loading from its compatibility hash API so the
  restore guard compares actual bytes, not only filenames or unit identifiers.
- Documented the complete
  `cc2camera backup → cc2_sig_tool build → cc2camera restore` workflow.
- Post-restore verification now asks for separate interactive consent before
  starting ADB temporarily when a clean config returns without the persistent
  hook. Restore `--yes` does not bypass this prompt; declined and non-interactive
  invocations send no ADB-start HID command. Successful readback requires an
  exact match through the end of HWCONFIG and reports config changes caused by
  the verification boot instead of incorrectly claiming a full byte-exact
  mismatch.
- Uses one `--adb-timeout` deadline for the preliminary post-restore ADB probe
  and the post-HID availability wait; the initial `get-state` can no longer add
  an independent ten-second delay.
- Expanded the offline suite from 78 to 85 tests, including allowed-region
  interoperability, wrong-unit rejection, offline pair planning, post-boot
  config handling, temporary ADB startup, and proof that a compatibility
  failure occurs before USB is opened.

## v0.7.0 — read-only backup and stable boot fingerprint

- Bumped the Python client to v0.5.0.
- Made `backup` strictly read-only. An offline camera now receives instructions
  for the separate `start-adb` or `install-adb-startup` commands; it is never
  mutated as an automatic fallback.
- Requires three consecutive byte-identical 8 MiB reads within at most five
  attempts, matching the repository's hardware-recovery
  minimum while allowing live JFFS2 state two additional chances to settle.
- Added a known SHA-256 gate for the complete 256 KiB boot partition:
  `5602ec961b4410ccceea0d4910e4fa768c6998bd4ba86143ba50855bdd0b7a54`.
- Unknown boot partitions fail only after the three-read gate, print the exact
  observed hash, and require an exact reviewed
  `--accept-bootloader-hash <sha256>` override before any backup is published.
- Publishes the raw image and `cc2flash-backup-v2` manifest as the two members
  of one ordinary ZIP. The completed archive is flushed, CRC-checked, and
  exposed through an atomic same-filesystem create-if-absent hard link. This
  eliminates both the prior half-pair window and concurrent overwrite race.
  Restore consumes the ZIP directly.
- Makes the ADB startup deadline bound each `get-state` subprocess and rejects
  zero, negative, infinite, and NaN durations before sending HID.
- Type-checks untrusted manifest counters before comparison, so malformed JSON
  is rejected as a protocol error instead of escaping as `TypeError`.
- Rejects impossible v2 stable-read counts and unsupported ZIP compression as
  clean protocol errors.
- Rejects damaged DEFLATE/LZMA member streams as clean protocol errors instead
  of allowing decompressor exceptions to escape with a traceback.
- Rejects overlong JSON integers and excessive manifest nesting as clean
  protocol errors instead of allowing decoder exceptions to escape.
- Treats an ADB subprocess timeout as an immediate hard failure, keeping the
  startup poll's retry set limited to absent, stock `offline`, and exact
  `error: closed` transition states.
- Defines restore `--adb-timeout` as the bounded online-availability wait; the
  stable readback then runs as a separate operation under per-command timeouts.
- Expanded the offline suite from 54 to 78 tests, including stability ordering,
  hash output/override behavior, create-if-absent ZIP publication, malformed
  manifests, bounded availability timeouts, read-only backup, and separate ADB
  commands.

## v0.6.0 — temporary ADB startup through upload command

- Bumped the Python client to v0.4.0.
- Added `backup --start-adb-through-upload-command`, which uses the recovered
  normal-HID uploader's unquoted target handling to start `/bin/adbd` for the
  current boot and then continues directly into the existing two-pass read.
- Classifies the stock camera's expected pre-daemon `offline` ADB state as
  startup-eligible; ambiguity, authorization, and other ADB failures still
  refuse both HID fallbacks.
- Replaces the single post-injection `adb wait-for-device` call with a bounded
  state poll. Live Windows testing showed that a successful startup closes the
  old USB transport first, causing `wait-for-device` to exit with
  `error: closed` even though the new daemon then accepts `adb shell`.
- Uses the stock daemon's legacy `shell` service for text and its binary-safe
  sync/`pull` service for MTD acquisition. Live Windows testing established that
  `exec-out` is unsupported, while a 65,536-byte `/dev/mtd4` pull exactly
  matched the camera-side MD5.
- Kept the ordinary upload target builder's shell-metacharacter rejection and
  added one immutable, audit-oriented builder for the exact no-space target
  `/tmp/.cc2flash-adbd-bootstrap;/bin/adbd&`.
- Treats only the final `0x3300` failure, timeout, or HID disconnect as expected;
  initialize, target, and final-data failures still abort before injection.
- Preserved `--bootstrap-adb` as a mutually exclusive persistent alternative.
- Expanded the offline suite from 41 to 54 tests, including ADB-offline
  classification, the exact injected
  frame, expected commit rejection, HID re-enumeration, legacy text-shell
  parsing, ordered binary pulls, and same-run backup.

## v0.5.0 — complete public Python command library

- Bumped the Python client to v0.3.0.
- Added the audit-oriented `cc2camera.commands` module with all 57 exact
  normal-mode command values, all 21 configuration GET/SET pairs, all 13 upload
  operations, the complete 16-bit dispatcher map, and group-wide `0x4xxx`
  matching.
- Added typed, side-effect-free builders for version/configuration/upload/
  upgrade operations and U-Boot metadata/data frames.
- Added all four U-Boot frame types and strict next-expected-packet/terminal
  response decoders.
- Refactored HID transport to use the shared builders; ordinary in-order restore
  ACK validation now matches the disassembly. Retransmission remains explicit
  but unimplemented, and no destructive physical test was performed.
- Expanded the offline suite from 22 to 41 tests, including a two-packet ACK
  sequence, metadata safety validation, and exact catalog/table checks.

## v0.4.0 — guarded ADB-startup fallback

- Bumped the Python client to v0.2.0.
- Confirmed the root `rcS` boot hook that executes persistent
  `/etc/conf.d/system.sh` before mounting `/system`.
- Added an ADB availability classifier so only a genuinely absent selected
  device can enter recovery; local ADB errors, ambiguity, authorization/root
  failures, and partition mismatches do not trigger a device write.
- Added the exact normal-HID upload of `/bin/adbd &`, interactive typed
  confirmation, explicit `--bootstrap-adb` automation opt-in, exit status `3`,
  and manual-restart instructions.
- Expanded the offline suite from 13 to 22 tests. Restore remains blocked by
  the known next-expected-packet ACK incompatibility.

## v0.3.0 — source-reconstruction checkpoint

- Added annotated C-like reconstructions of Linux `/bin/hid_update`, the SPL
  upgrade gate, and the main-U-Boot update state machine.
- Added exact function/address traceability and read-only reproduction commands.
- Added dependency-free vectors for the normal CRC, upgrade trigger, bootloader
  metadata/ACK framing, and image-header MD5 layout.
- Documented the configuration SET routine's tail buffering and zero-padding.
- Retained the prior corrections that U-Boot ACKs carry the next expected packet
  number and that stock startup scripts do not autostart `adbd`.

At this checkpoint, the Python client was still the original research
implementation and was blocked by the two issues then described in
`PROJECT-STATUS.md`; v0.4.0 resolves the ADB-startup half only.

## v0.2.0 — complete protocol reference

- Added the complete normal-HID and U-Boot HID/CDC protocol catalog.
- Corrected the bootloader ACK interpretation.
- Corrected the earlier assumption that ADB is immediately available on stock
  USB.

## v0.1.0 — initial research client

- Added offline protocol builders/parsers, HID transport scaffolding, ADB backup
  logic, safety gates, and 13 mocked/offline tests.

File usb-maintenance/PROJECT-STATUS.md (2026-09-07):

# Project status

**Documentation checkpoint: 2026-09-04**

## Completed

- Confirmed the 8 MiB flash/MTD map and both SquashFS filesystems.
- Recovered and disassembled the exact 19,048-byte `/bin/hid_update`.
- Documented the complete 1,024-byte normal-HID frame and CRC.
- Cataloged the version command, all 42 configuration commands, all 13 Linux
  file-upload commands, and the group-wide `0x4xxx` bootloader trigger.
- Documented U-Boot HID/CDC framing, metadata, numbered data, ACK values, retry
  behavior, the 128-byte image header, MD5 check, and SPI erase/write sequence.
- Established that neither updater stage exposes flash or file download.
- Corrected the earlier ADB assumption: `adbd` exists but is not autostarted.
- Confirmed that root `rcS` mounts JFFS2 at `/etc/conf.d` and executes an
  optional `/etc/conf.d/system.sh` before mounting `/system`.
- The guarded `install-adb-startup --backup BACKUP.zip` command requires online
  root ADB, stable reads and clean space. It installs/readbacks a shared runner
  and separate ADB hook through ADB, refuses different contents at `system.sh`
  or the selected `enabled/90-adb.sh` path, and requires a manual restart.
  Unrelated regular enabled hooks remain and execute in filename order.
- Added a separate nonpersistent `start-adb` command that starts `/bin/adbd`
  through the uploader's unquoted `rm` target, waits for root ADB, and exits
  without reading flash or installing a persistent file.
- Made `backup` strictly read-only. It requires three consecutive identical
  full reads within five attempts before evaluating a known boot-partition
  SHA-256 or an exact user-reviewed override.
- Publishes `flash.bin` and `manifest.json` inside one verified ZIP through an
  atomic same-filesystem create-if-absent hard link; a concurrently created
  destination is never overwritten, and restore validates the archive directly.
- Bounds every post-HID ADB probe by the remaining startup deadline, rejects
  invalid durations before HID, and rejects malformed manifest field types as
  ordinary protocol errors.
- Replaced backup use of unsupported `adb exec-out` with legacy text `shell`
  plus binary-safe sync/`pull`. A live Windows pull of `/dev/mtd4` returned the
  exact expected 65,536 bytes and matched the camera-side MD5.
- Corrected the bootloader ACK interpretation: type-2 payload is
  `u32le(next_expected_packet)`.
- Reconstructed the complete update-relevant Linux daemon, SPL gate, and main
  U-Boot state machine as annotated C-like source with exact address anchors.
- Added reproducible extraction/disassembly commands and dependency-free packet
  vectors for independent review.
- Added `cc2camera.commands`, a public typed catalog for all 57 exact normal-HID
  commands, the full 16-bit dispatcher behavior, and all four U-Boot frame types.
- Added side-effect-free builders for every recovered operation, plus typed ACK
  and terminal-status decoders, with source anchors and safety comments beside
  the implementation.
- Refactored the CLI-used HID paths to consume the public builders rather than
  maintaining a second set of command literals.
- Added direct interoperability with hardware recovery: its builder consumes
  the preserved USB ZIP, while `restore --dry-run --backup` and `restore` prove the
  generated image matches that same camera outside the two audited edit
  regions.
- Made post-write verification compatible with both hardware-recovery config
  modes: after a serial-only boot it separately prompts for permission to start
  ADB temporarily, requires an exact match through HWCONFIG, and separately
  reports config changes made by that boot. Starting temporary ADB requires
  separate consent.

## Client status

The included Python client is now v0.6.0 with 106 passing offline tests. Its
backup path is strictly read-only and requires three consecutive identical full
reads within five attempts. Temporary and persistent ADB setup are separate
commands rather than fallback flags on `backup`. An accepted backup is one ZIP
archive, so the raw image cannot be published without its evidence manifest.
The restore path parses type-2 payloads as the next expected absolute packet and
rejects a retransmission request with an explicit error; automatic
retransmission is not implemented. A physical integrated restore completed the automatic live SFC preparation,
all 2,742 packets, full-flash erase/write, normal reboot, and required
three-read post-write verification. The earlier unprepared trigger failure is
now detected and avoided by exact-kernel, live-state, and readback gates.

Before opening USB, restore now compares the replacement with `flash.bin` from
the validated preserved ZIP. Only hardware recovery's exact SquashFS patch
window and config partition may differ. This rejects a wrong-camera recovery
image or unsupported additional edits. The same check is available read-only
through `restore --dry-run --backup`.

After restore, the client acquires another three consecutive reads. All bytes
through `0x7dffff` must match the candidate exactly. The writable config
partition is compared and reported separately because the first successful
serial-only boot recreates missing defaults before ADB can read it back.

The expanded tests verify exact catalog completeness, all 21 configuration
pairs, all 13 uploader commands, all four U-Boot frame types, group-wide
`0x4xxx` behavior, builders/decoders, stable-read/hash/archive gates, bounded
deadline propagation, post-restore availability-timeout separation,
malformed-manifest, JSON decoder-limit, unsupported-ZIP, and corrupt
compressed-member rejection,
hard failure on a hung ADB subprocess, the exact
`3000 → 3110 → 3200(final) → 3300` ADB-startup upload, interactive guards, and
proof that declined or non-interactive post-restore prompts send no HID command,
the temporary command-injection transaction, and the prior backup/image safety
checks.

Post-restore ADB availability uses one deadline for the preliminary probe and
the post-HID wait. The preliminary `get-state` subprocess cannot exceed
`--adb-timeout`, and it no longer adds its default ten-second budget before the
documented wait.

Without any setup, the stock USB gadget always enumerates an ADB transport as
`offline` until `adbd` starts. The availability classifier treats that exact
state, as well as a genuinely absent device, as eligible for both the temporary
and persistent startup mechanisms. Ambiguous, unauthorized, non-root, and
malformed-device states remain refusals.

## Hardware status

- A destructive physical experiment was completed on one
  `EF-S7-V1.0.30B`/T23N/ZB25VQ64 camera. The sanitized record is in
  [PHYSICAL-VALIDATION.md](PHYSICAL-VALIDATION.md).
- The first normal-mode trigger attempted to write the eight-byte upgrade flag
  over a JFFS2 cleanmarker at `0x7f8000`. Its erase failed, and the observed
  bytes were exactly the bitwise AND of the old data and requested flag. SPL
  read `0x00000004, 0x00000000`, so it booted Linux rather than U-Boot HID.
- Runtime logging and exact-kernel disassembly identified an erase-geometry
  mismatch: the driver was configured for `0x4000`, while the sector-erase
  routine has opcode cases only for `0x1000`, `0x8000`, and `0x10000`.
  Temporarily changing the boot-specific live field to `0x1000` made complete
  MTD erases succeed. Restore now derives, validates, changes, and reads back
  that field immediately before the stock flag operation. Reboot resets it, so
  this remains temporary preparation rather than a persistent fix.
- After experimental config preconditioning, SPL read the exact upgrade words
  and bootloader HID `a108:ff08` enumerated. A one-off continuation transmitted
  all 2,742 packets. U-Boot accepted the RAM-image MD5, erased and wrote the
  complete 8 MiB image, and returned to normal USB.
- The camera produced live video after the write. Temporary ADB startup then
  worked, and a post-write backup obtained three consecutive identical 8 MiB
  reads in three attempts. Boot through HWCONFIG matched the candidate exactly;
  strict validation passed, while config differed only as expected from the
  serial-only first boot. `system.sh` was absent.
- A later test exercised the integrated client as one uninterrupted operation,
  without a manual RAM edit, config erase, process suspension, or separate
  continuation. It obtained three stable pre-write reads, completed the dynamic
  preparation and stock HID transition, wrote the image, returned to normal
  USB, and obtained three stable post-write reads matching every boot-stable
  byte through HWCONFIG.
- No direct USB flash-read command was found. The temporary ADB route avoids
  installing a persistent file: it attempts a tmpfs removal, starts `/bin/adbd`,
  and then reaches the vendor's `sync` plus expected failing `fopen`. Normal
  firmware activity may still have pending JFFS2 writes, so this is not a claim
  that every flash byte remains unchanged during a live boot.
- The device owner physically verified the shared startup runner, persistent
  ADB, erase correction and repeated boots on one supported camera.
  [Hardware findings](../docs/STARTUP-HOOKS-VALIDATION.md) distinguish direct
  erase observations from automatic-GC inference and record the test limits.
- The temporary upload-command ADB start is derived from the reconstructed
  `hid_update` control flow. Its first physical-camera test successfully started
  `/bin/adbd` and allowed `adb shell`; the Windows host exposed a now-corrected
  retry bug by returning `error: closed` from the old USB transport first.
- An earlier live session confirmed that stock `adbd` rejects `exec-out`, but its
  sync service pulls raw MTD devices without byte changes. A later invocation
  acquired a complete 8 MiB image with SHA-256
  `bccc6818a998d1c143c94543194e2d314cdee7a5f43b62db1fc6bb0b038c22a7`.
  Its boot partition is byte-identical to the supplied reference image and has
  SHA-256
  `5602ec961b4410ccceea0d4910e4fa768c6998bd4ba86143ba50855bdd0b7a54`.
  The strengthened three-consecutive-read policy has now also passed both the
  pre-write and post-write physical acquisitions used for this experiment.

The authoritative protocol and full command catalog are in `PROTOCOL.md`; static
anchors and hashes are in `EVIDENCE.md`. The human-readable reconstruction and
its audit guide are in `source-reconstruction/`.

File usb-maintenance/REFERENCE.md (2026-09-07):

# USB-maintenance reference

The normal user journey begins in the [main camera guide](../README.md). This document retains the complete installation, command, API, protocol-status, limitation, and test reference.

`cc2camera` is a safety-focused maintenance client and protocol description for
the stock Elegoo Centauri Carbon 2 camera firmware found in the supplied
8 MiB flash dump.

> **Research status:** a physical test validated in-order bootloader HID
> transfer, full-flash erase/write, normal reboot, video, and independent
> three-read verification on one camera. The same test found that the preceding
> normal-mode trigger can fail destructively when its config-sector target is
> occupied. The integrated client now validates and temporarily corrects that
> live erase-size field; its complete restore path passed physical write and
> three-read verification on the supported camera. Preserve a three-read backup
> and read [SFC restore preparation](SFC-RESTORE-PREPARATION.md) together with
> `PHYSICAL-VALIDATION.md` before restoring.

The important result is that the bootloader USB updater is **write-only**. It
does not implement a flash-read request. The included backup implementation
instead reads `/dev/mtd0` through `/dev/mtd5` over root ADB. It uses the
legacy shell service for text checks and binary-safe `adb pull` for MTD bytes;
the stock daemon does not support modern `adb exec-out`. `backup` is strictly
read-only: if ADB is offline, run the separate `start-adb` command for a
temporary start. With ADB online and a backup preserved, use
`install-adb-startup --backup BACKUP.zip` to install the persistent
`/etc/conf.d/system.sh` hook and then restart.

This code was recovered by static analysis and tested offline against the
provided dump. Live Windows testing has validated temporary HID startup, root
`adb shell`, byte-exact `adb pull`, and a complete 8 MiB backup. Capture a
backup accepted from three consecutive identical reads before considering
restore.

## Human-readable source reconstruction

The `source-reconstruction/` directory translates the update-relevant binary
paths into annotated C-like source:

- `hid_update_reconstructed.c` covers the complete normal-mode command parser,
  all configuration and upload commands, the persistent flag write, and the HID
  event loop.
- `spl_upgrade_gate_reconstructed.c` covers the early upgrade-magic decision.
- `uboot_updater_reconstructed.c` covers metadata/data frames, ACK/retry state,
  MD5 validation, transport selection, and SPI erase/write ordering.
- `TRACEABILITY.md` maps functions to binary addresses, and `REPRODUCING.md`
  gives commands to regenerate the relevant disassembly.

This is an audit aid, not recovered original vendor source or a replacement
updater. Read `source-reconstruction/README.md` before relying on it.

## Install

Follow the [installation guide](../docs/INSTALLATION.md).
The Windows executable includes Python and HID support; ADB is installed
separately. The complete command syntax is in the [CLI reference](../docs/CLI.md).

For contributor installation, run `python -m pip install -e .` at the repository
root. Run the offline suite there with `python -m unittest discover -s tests -v`.

## Public Python command API

`cc2camera.commands` mirrors the complete recovered command surface, including
commands that the CLI does not currently use. The module is intentionally
side-effect free and contains large audit comments beside the numeric tables,
wire builders, binary-address anchors, state requirements, and hazards.

The public catalog contains:

- `NormalCommand`: all 57 exact normal-mode values—one version query, 42
  configuration GET/SET commands, 13 file-uploader commands, and canonical
  `0x4000`;
- `CONFIGURATION_COMMANDS`: all 21 literal configuration-key pairs, including
  whether each key was present in the supplied active configuration;
- `UPLOAD_COMMANDS`: the full 13-command uploader state machine;
- `NORMAL_DISPATCH_MAP`: the silent/no-op/unknown behavior for the complete
  16-bit command space, plus group-wide `0x4xxx` matching;
- `BOOT_FRAME_TYPES`: U-Boot types 1, 2, 3, and 5, with directions and payload
  meanings; and
- typed builders and response decoders for every implemented operation.

For example, these calls only construct and inspect bytes; they do not open USB:

```python
from cc2camera.commands import (
    ConfigurationKey,
    NormalCommand,
    build_config_get_request,
    build_config_set_request,
    build_upload_target_request,
    describe_normal_command,
)
from cc2camera.protocol import parse_normal_report

request = build_config_get_request(ConfigurationKey.SENSOR_NAME)
assert parse_normal_report(request).command == 0x2F50

replacement = build_config_set_request("adb_en", "1")
assert parse_normal_report(replacement).command == 0x2F41

# Every recovered literal-path selector is available, not just CLI-used 0x3110.
target = build_upload_target_request(NormalCommand.UPLOAD_TARGET_31F0, "/tmp/a")

# Noncanonical values are reported accurately because all 0x4xxx values reboot.
assert describe_normal_command(0x4ABC).name == "upgrade_and_reboot_0x4abc"
```

Sending is separate and explicit: open `HidHandle` and pass a built report to
`hid_transport.exchange_normal`. Configuration SET, upload commit, and upgrade
reports mutate the device; building them does not.

## Backup workflow

Connect exactly one camera in normal USB mode, then:

```sh
cc2camera devices
cc2camera device-info
cc2camera backup backup.zip
```

Without any setup and before `adbd` starts, the stock camera always exposes its
USB ADB function and appears in `adb devices` as `Ucamera001 offline`. The client
treats that exact offline state like an absent transport for both startup
mechanisms; it does not treat ambiguity, authorization errors, or other ADB
failures the same way.

If ADB is already online, `backup` proceeds without a normal-HID write. To start
the installed daemon only for this boot, use the separate command:

```sh
cc2camera start-adb
cc2camera backup backup.zip
```

This sends `0x3000`, the immutable no-space target
`/tmp/.cc2flash-adbd-bootstrap;/bin/adbd&` through `0x3110`, one harmless final
newline through `0x3200`, and then `0x3300`. The vulnerable daemon executes:

```sh
rm /tmp/.cc2flash-adbd-bootstrap;/bin/adbd&
```

before attempting to open the complete target as a literal pathname. That open
is expected to fail because the semicolon-suffixed tmpfs component is not a
directory. A status-1 reply or HID disconnect after `0x3300` is therefore not
used as the success signal. Live Windows testing showed that the old USB
transport can first return `error: closed` even though the newly started daemon
already accepts `adb shell`. The client polls through that exact transition,
stock `offline`, and temporary absence for up to 30 seconds. It then verifies
root ADB and stops; `backup` is a separate read-only invocation. Other ADB
errors and earlier upload failures remain fatal. Override the wait only when
necessary:

```sh
cc2camera start-adb --timeout 60
```

This route does not install a persistent file or require a restart. The vendor
handler nevertheless calls `sync`, and the running stock firmware may already
have pending JFFS2 changes, so it is not a guarantee that unrelated live-system
writes never reach flash. It specifically avoids the known `system.sh` change.

For optional persistent ADB, obtain online root ADB and preserve a backup first:

```sh
cc2camera start-adb
cc2camera backup backup.zip
cc2camera install-adb-startup --backup backup.zip
```

If installing the erase fix too, install it before optional persistent ADB so
its space budget takes priority. See [startup hooks](../docs/STARTUP-HOOKS.md).

The installer requires `ENABLE-ADB` (or explicit `--yes`), validates the backup
and live camera, checks clean config space, stages/readbacks files in tmpfs,
and installs the shared runner plus `enabled/90-adb.sh` through ADB. It verifies
persistent bytes and permissions. Different contents at `system.sh` or the
selected `enabled/90-adb.sh` path are refused. Unrelated regular hooks in
`enabled/` remain and execute in filename order. It does not use destructive HID
file upload. Restart manually after
successful installation.

`start-adb` is a no-op when the selected ADB device is already online.
`backup` never invokes either command automatically. Offline ADB requires the
temporary `start-adb` command, not the persistent installer.

`backup` requires the exact recovered partition sequence and sizes:

| MTD | Start | Size | Name |
|---|---:|---:|---|
| mtd0 | `0x000000` | `0x040000` | boot |
| mtd1 | `0x040000` | `0x150000` | kernel |
| mtd2 | `0x190000` | `0x158000` | root |
| mtd3 | `0x2e8000` | `0x4e8000` | system |
| mtd4 | `0x7d0000` | `0x010000` | hwconfig |
| mtd5 | `0x7e0000` | `0x020000` | config |

It attempts at most five complete reads and requires three **consecutive**
byte-identical 8 MiB images. A three-of-five majority is insufficient. Only
after that stability gate does it hash the 256 KiB `boot` partition and compare
it with the built-in known SHA-256:

```text
5602ec961b4410ccceea0d4910e4fa768c6998bd4ba86143ba50855bdd0b7a54
```

An unknown boot hash stops the command after the three matching reads and
prints the exact observed hash. After independently reviewing it, that one
value can be accepted explicitly:

```sh
cc2camera backup --accept-bootloader-sha256 <observed-sha256> backup.zip
```

The supplied value must exactly match the newly observed hash. Only then does
the client publish `backup.zip`. The ordinary ZIP contains exactly:

| Member | Purpose |
|---|---|
| `flash.bin` | accepted raw 8 MiB flash image |
| `manifest.json` | `cc2flash-backup-v2` acquisition evidence |

The manifest records the acquisition counts, hashes, partition map, boot
fingerprint, and acceptance basis. Both members are completed and CRC-checked
under a temporary name before one same-filesystem create-if-absent hard link
exposes the final ZIP. Publication cannot replace an archive that appears
concurrently, and an interruption cannot publish only the image or only its
evidence. Standard ZIP tools can extract `flash.bin` for independent inspection.

### Hardware-recovery interoperability

Pass the unmodified ZIP directly to the hardware-recovery builder; its embedded
three-consecutive-read evidence satisfies that tool's physical-read gate:

```sh
cc2camera inspect-image backup.zip
cc2camera build-image backup.zip
```

The builder writes
`backup-cc2-recovery/cc2-camera-recovery.bin`. It does not alter or replace
`backup.zip`. Preserve that original archive: it remains the acquisition
evidence required by restore.

Validate the resulting pair without opening USB:

```sh
cc2camera restore --dry-run \
  backup-cc2-recovery/cc2-camera-recovery.bin \
  --backup backup.zip
```

This proves that the candidate is a full restore image and is byte-identical to
the preserved camera backup everywhere except hardware recovery's audited
`0x463000–0x46afff` SquashFS patch window and
`0x7e0000–0x7fffff` config partition. The same compatibility check runs again
before `restore` opens USB, preventing a recovery image from another camera
or an image with unsupported additional edits from being written.

If ADB lists more than one device, pass the camera serial explicitly:

```sh
cc2camera backup --serial Ucamera001 backup.zip
```

The exact serial exposed by ADB may differ; use `cc2camera devices` to inspect it.

## Restore workflow (physically validated on the supported camera)

Root ADB must already be online; use the separate `start-adb` command if needed.
Connect only one ADB device and one normal camera HID interface, with matching
serials. See [SFC restore preparation](SFC-RESTORE-PREPARATION.md) for the exact
kernel gate, runtime pointer derivation, failure behavior, and hardware evidence.

Validate a candidate without opening USB:

```sh
cc2camera restore --dry-run fixed.bin --backup backup.zip
```

A full restore requires exactly `0x800000` bytes.  It also rejects an image
whose word at `0x7f8000` is the persistent upgrade magic, because that image
would return to upgrade mode on every reboot.

Restore requires the separately preserved three-read backup and its v2
manifest.
The replacement must match that backup outside the two hardware-recovery
regions documented above.
The transport parses each nonfinal ACK as the next expected absolute packet and
aborts if U-Boot requests retransmission, which this research client does not yet
implement. The command currently exists as:

```sh
cc2camera restore fixed.bin --backup backup.zip
```

Without correcting the live SFC erase size, the stock flag operation can damage
an occupied JFFS2 node without entering the bootloader. The integrated command
now validates and applies that temporary preparation before sending the flag.
The original failure, manual investigation, and successful end-to-end automated
validation are recorded in [PHYSICAL-VALIDATION.md](PHYSICAL-VALIDATION.md) and
[SFC-RESTORE-PREPARATION.md](SFC-RESTORE-PREPARATION.md).

The command prints the complete target range and hashes, then requires the
literal confirmation `RESTORE-CC2` for every real restore. Its phases are:

1. Validate `fixed.bin` and both members of `backup.zip` locally.
2. Require the known kernel, three consecutive identical live reads, and a
   match to the preserved backup outside the audited recovery regions. Validate
   root/MTD geometry, kernel symbols/instructions, and the runtime SFC pointer.
   Sync, set the internal erase size to `0x1000`, and verify it before sending
   the stock 8-byte upgrade flag through normal Linux HID. No manual config
   erase or process suspension is performed; `0x4000` is not restored in RAM.
3. Wait for bootloader HID `a108:ff08`.
4. Transfer a 128-byte update header plus the image in numbered packets.
5. Require the bootloader's whole-image MD5 success indication.
6. Wait without removing power while the bootloader erases, writes, and reboots.
7. Ensure root ADB is online. If it is offline, ask interactively whether to
   start `/bin/adbd` temporarily through normal HID; only an explicit `y` or
   `yes` sends that command. Then acquire three consecutive identical flash
   images over ADB.
8. Require every boot-stable byte from `0x000000` through the end of HWCONFIG at
   `0x7dffff` to match `fixed.bin`. Report whether config also stayed exact;
   serial-only images legitimately create default config files during this boot.

The bootloader reports MD5 acceptance **before** erase/write and offers no
post-write status or readback. ADB readback is therefore mandatory for a successful USB restore.

Consent to the flash write and consent to start ADB are separate. Both require interactive confirmation. Empty or negative input, and non-interactive stdin, send
no ADB-start HID command and leave the completed restore explicitly
unverified.

`--adb-timeout` is one deadline shared by the initial bounded ADB probe and, if
the temporary start is explicitly confirmed, the post-HID wait for ADB to come
online. Once ADB is online, stable post-write verification begins as a separate
operation with the ordinary per-command timeouts; the option does not claim to
bound up to five complete flash reads.

Do not unplug the camera after the MD5 response. A failed transfer before the
MD5 check does not erase flash, but the persistent flag may leave the camera in
bootloader mode; reconnecting the bootloader and retransmitting a full known
image is then the intended recovery path.

## Current limits

- Temporary ADB startup, binary-safe partition pulls, and a complete 8 MiB
  backup have been exercised on a physical camera from Windows. One first-run
  acquisition failed its equality gate while live state was settling; a later
  invocation produced matching full reads. The client now requires three
  consecutive matches within five attempts.
- Bootloader data ACK parsing now matches the disassembly for in-order packets,
  and one physical in-order transfer completed all 2,742 packets. Automatic
  retransmission remains absent and was not exercised.
- The bootloader full-flash erase/write, normal reboot, live video, and
  independent three-consecutive-read verification succeeded on one camera.
  The manual RAM-patched trigger and the later integrated automatic preparation
  both succeeded. The integrated run completed the full write, normal reboot,
  and required three-read verification.
- The stock Linux SFC driver advertises a 16 KiB erase size while its erase
  routine has opcode cases for 4, 32, and 64 KiB only. A boot-specific live RAM
  change to the internal size made 4 KiB sector erases work, confirming the
  mismatch. Restore now validates and applies that temporary preparation; it
  is not a persistent kernel fix and resets on reboot.
- Persistent ADB installation requires a backup and online ADB, refuses different
  contents at `system.sh` or the selected `enabled/90-adb.sh` path, and verifies
  installed contents. Unrelated regular enabled hooks remain and execute. The temporary upload-command
  route deliberately relies on a vendor command-injection bug. That temporary startup has now been
  hardware-verified, but the vendor handler's `sync` caveat remains.
- CDC transport is identified but not implemented; HID is the bootloader's
  default and the path used here.
- Range writes are intentionally omitted.  Although the header accepts an
  arbitrary offset and length, a partial write normally leaves the upgrade
  flag at `0x7f8000` set and can cause an upgrade-mode boot loop.
- The stock bootloader does not bounds-check the image range and does not check
  or report the return values of its SPI erase/write calls.  The client applies
  the missing range checks itself.

See [PROTOCOL.md](PROTOCOL.md) for the recovered wire formats and
[EVIDENCE.md](EVIDENCE.md) for static-analysis offsets and hashes. Read
[PROJECT-STATUS.md](PROJECT-STATUS.md) before running the client.

## Tests

```sh
python -m unittest discover -s tests -v
```

The 106 tests exercise the 57-entry normal command catalog, all configuration and
upload mappings, command builders, U-Boot frame types/ACK decoders, frame
vectors, checksums, image headers, packet numbering, partition validation, ADB
absence/offline/error classification, three-consecutive-of-five acquisition,
boot-hash gating, create-if-absent ZIP publication, strict v2 manifest parsing
including JSON decoder-limit failures,
unsupported-compression rejection, both explicit ADB startup commands,
hardware-recovery region compatibility, boot-stable post-write comparison,
separately confirmed temporary ADB startup after a serial-only restore, and
pre-USB wrong-unit rejection,
bounded/validated availability timeouts, expected final-commit
failure/disconnection, the Windows `error: closed`
transport handoff, legacy text-shell parsing, ordered binary MTD pulls and
temporary-file cleanup, CLI mutation guards, dynamic SFC pointer derivation,
exact-kernel/instruction/value gates, transport matching, guarded RAM write and
readback failures, restore ordering, and the HID state machines without opening
a device.

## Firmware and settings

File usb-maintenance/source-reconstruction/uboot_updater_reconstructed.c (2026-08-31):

/*
 * Human-readable reconstruction of the CC2 main-U-Boot USB updater.
 *
 * NOT ORIGINAL SOURCE.  Function addresses refer to the U-Boot image linked at
 * 0x80100000 (flash file offset 0x6800).  This file preserves missing checks and
 * ordering bugs for auditability; it is not a safe updater implementation.
 */

#include <stdint.h>
#include <stddef.h>
#include <stdlib.h>
#include <string.h>

enum {
    FLASH_SIZE = 0x00800000,
    UPGRADE_WORD_OFFSET = 0x007f8000,
    HID_REPORT_SIZE = 3072,
    HID_REPORT_ID = 1,
    COMMON_OVERHEAD = 7,
    DATA_OVERHEAD = 11,
    IMAGE_HEADER_SIZE = 128
};

enum updater_type {
    HOST_METADATA = 1,
    DEVICE_ACK = 2,
    HOST_DATA = 3,
    DEVICE_TERMINAL = 5
};

typedef enum {
    TRANSPORT_CDC,
    TRANSPORT_HID
} update_transport;

typedef struct {
    uint16_t subpack_size;
    uint32_t transfer_size;
    uint16_t packets_per_ack;
    uint16_t version;
} transfer_metadata;

typedef struct {
    uint8_t ignored0[4];
    uint32_t flash_offset;
    uint32_t image_length;
    uint8_t image_md5[16];
    uint8_t ignored1[100];
} image_header;

typedef struct {
    transfer_metadata meta;
    uint32_t packet_count;
    uint32_t batch_count;
    uint32_t next_packet;
    uint32_t batch_first_packet;
    uint32_t stream_used;
    uint8_t *stream;
    uint8_t bad_frame_count;
    uint8_t stall_count;
    uint8_t terminal_state;
} updater_state;

typedef struct spi_flash spi_flash;

static updater_state U;
static spi_flash *G_flash;
static update_transport G_transport;
static uint8_t G_device_frame[512];
static uint16_t G_device_frame_length;

static uint16_t rd16(const uint8_t *p) {
    return (uint16_t)(p[0] | ((uint16_t)p[1] << 8));
}

static uint32_t rd32(const uint8_t *p) {
    return (uint32_t)p[0] | ((uint32_t)p[1] << 8) |
           ((uint32_t)p[2] << 16) | ((uint32_t)p[3] << 24);
}

static void wr16(uint8_t *p, uint16_t v) {
    p[0] = (uint8_t)v;
    p[1] = (uint8_t)(v >> 8);
}

static void wr32(uint8_t *p, uint32_t v) {
    p[0] = (uint8_t)v;
    p[1] = (uint8_t)(v >> 8);
    p[2] = (uint8_t)(v >> 16);
    p[3] = (uint8_t)(v >> 24);
}

static uint32_t ceil_div_u32(uint32_t n, uint32_t d) {
    /* BUG-COMPAT: callers do not establish d != 0. */
    return (n + d - 1) / d;
}

/* Vendor/U-Boot effects outside the protocol state machine. */
extern int transport_send(const uint8_t *frame, size_t frame_length);
extern void uboot_md5(const uint8_t *data, uint32_t length, uint8_t out[16]);
extern spi_flash *spi_flash_probe(unsigned bus, unsigned chip_select,
                                  unsigned hz, unsigned mode);
extern int spi_flash_erase(spi_flash *flash, uint32_t offset, uint32_t length);
extern int spi_flash_write(spi_flash *flash, uint32_t offset, uint32_t length,
                           const void *data);
extern int spi_flash_read(spi_flash *flash, uint32_t offset, uint32_t length,
                          void *data);
extern void mdelay(unsigned milliseconds);

/* 0x80117948 */
static int validate_host_frame(const uint8_t *frame, uint16_t received_length)
{
    static const uint8_t host_magic[3] = {0x80, 0x00, 0xee};
    if (memcmp(frame, host_magic, 3) != 0)
        return -1;

    /* CONFIRMED: validation is driven by the supplied/global received length;
     * bytes 0..length-2 sum modulo 256 and must equal the last byte. */
    uint8_t sum = 0;
    for (uint16_t i = 0; i + 1 < received_length; ++i)
        sum = (uint8_t)(sum + frame[i]);
    return sum == frame[received_length - 1] ? 0 : -1;
}

/* 0x801179ec */
static const uint8_t *build_device_frame(uint8_t type,
                                         const void *payload,
                                         uint16_t payload_length)
{
    memset(G_device_frame, 0, sizeof(G_device_frame));
    G_device_frame[0] = 0x81;
    G_device_frame[1] = 0x00;
    G_device_frame[2] = 0xee;
    G_device_frame[3] = type;
    G_device_frame_length = (uint16_t)(payload_length + COMMON_OVERHEAD);
    wr16(G_device_frame + 4, G_device_frame_length);
    if (payload)
        memcpy(G_device_frame + 6, payload, payload_length);

    uint8_t sum = 0;
    for (uint16_t i = 0; i + 1 < G_device_frame_length; ++i)
        sum = (uint8_t)(sum + G_device_frame[i]);
    G_device_frame[G_device_frame_length - 1] = sum;
    return G_device_frame;
}

static void send_ack(uint32_t next_expected_packet)
{
    uint8_t payload[4];
    wr32(payload, next_expected_packet);
    build_device_frame(DEVICE_ACK, payload, 4);
    (void)transport_send(G_device_frame, G_device_frame_length);
}

static void send_terminal(uint8_t success)
{
    build_device_frame(DEVICE_TERMINAL, &success, 1);
    (void)transport_send(G_device_frame, G_device_frame_length);
}
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

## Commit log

2026-08-26 Initialize CC2 camera recovery project
2026-09-02 Validate the current USB backup format
2026-09-03 Restructure camera recovery documentation
2026-09-03 Document printable USB camera adapter
    [cc2-camera-p50-pogo-adapter.stl]
2026-09-03 Fix camera adapter photo asset
2026-09-07 Match partition name case consistently in the early boot hook
2026-09-07 Document startup-hook hardware validation and GC pressure findings
2026-09-07 Require usable config mounts and reconcile startup workflow documentation
2026-09-08 Add experimental native on-printer HID hook installer
2026-09-08 Recognize observed 30D USB signature before camera access
2026-09-09 Add read-only MJPEG camera fingerprinting
2026-09-09 Expose camera stream identification in CLI
2026-09-09 Test MJPEG camera fingerprint matching
2026-09-09 Cover identify-camera CLI behavior
2026-09-09 Document stream-based camera identification
2026-09-09 Lead camera identification with read-only stream check
2026-09-09 Support missing camera version metadata and temporary HID status files
2026-09-09 Record normal camera feed after HID installation and verification
2026-09-20 Support PSSSS3 camera identity variant
2026-09-27 Publish ARM HID binary through the existing release workflow
2026-09-27 Revert "Add experimental on-printer HID erase-fix installer"
